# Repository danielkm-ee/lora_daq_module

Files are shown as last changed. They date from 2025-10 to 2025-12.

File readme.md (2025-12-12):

# LoRA DAQ Node
For our Electrical and Computer Engineering practicum at Portland State for 2025 we have developed a LoRA based data acquisition node that can be used for data collection and monitoring systems over large areas.

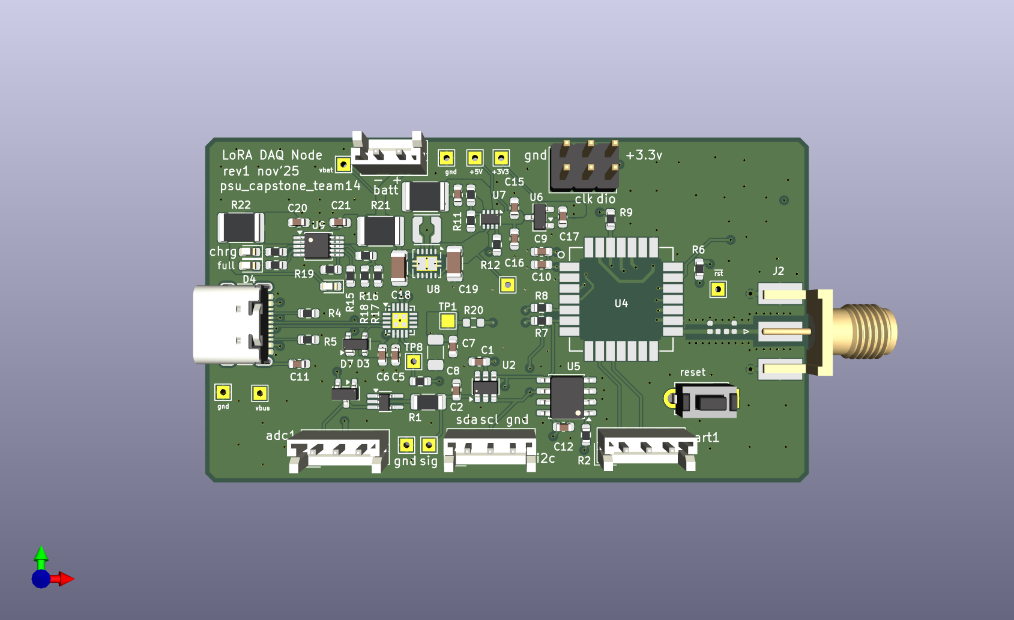
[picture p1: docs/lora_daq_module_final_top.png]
3d model of lora board top


This board is powered by the Seeed Studios Wio-E5 LoRA module for use with it's designated antenna.

## Supported Peripherals
We've done our best to provide a versatile range of peripherals for high quality data collection and application flexibility. This includes a UART interface for communicating with the device via it's USB-C port, a SWD interface for loading and debugging applications, a 16-bit ADC and I2C connector that can be used with analog and I2C compatible sensors.

The device may be powered via it's USB-C (USB 2.0) connection, or by a 1s1p lithium ion battery. The device also
supports battery charging when powered by USB-C with the battery connected.

List of Peripherals
------------------
* 16-bit ADC
* I2C interface
* MicroSD card slot
* 2 external UART interfaces (one via USB-C port)
* 6-pin SWD header for ST-Link v2
* SMA connector for the 868-916MHz LoRA Antenna
* 2-pin JST EH connector for battery power and charging

## Credits
* Manaf Alali - hardware schematics
* Eyad Ahmed  - firmware
* Daniel Monahan - hardware schematics and layout
* Saleh Sabti - hardware schematics
* Dingyu Zhou - firmware

> All team members contributed to every aspect of the project, going beyond the general roles specified here.

----
*Portland State University ECE411 Practicum project, Fall 2025*

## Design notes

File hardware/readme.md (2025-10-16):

# LoRA DAQ Hardware
Here you will find the KiCAD project files for the lora daq module. This project has been separated into three main parts:  
* `adc.kicad_sch` includes the input filter and supporting hardware related to the adc  
* `power_management.kicad_sch` includes the battery controller, ldos, and dc-dc converters  
* `lora_module.kicad_sch` includes the wio-e5, lora antennae, and eeprom  

## KiCAD Version Control Notes (Please read these!)
KiCAD version control will be managed through this git repository, there are some important things to 
keep track of while you work!  

### Git Management
To keep things nice, please keep all of your work confined to the schematic for your module. This should also 
correspond to your git branch. Here's an example:

Say I'm working on the ADC, first I'll make a git branch for my work...
```
$ git checkout -b schematic-adc
Switched to a new branch 'schematic-adc'
```
then I'll do work in the adc.kicad_sch file, and when I'm ready to submit the updated schematic I'll upload it to
my schematic branch.
```
$ git add ./adc.kicad_sch
$ git commit -m "added buffer to the input filter of the ads1115"
$ git push --set-upstream origin schematic-adc
Enumerating objects: 22, done.
Counting objects: 100% (22/22), done.
Delta compression using up to 14 threads
Compressing objects: 100% (20/20), done.
Writing objects: 100% (20/20), 8.72 KiB | 4.36 MiB/s, done.
Total 20 (delta 5), reused 0 (delta 0), pack-reused 0
remote: Resolving deltas: 100% (5/5), completed with 1 local object.
remote: 
remote: Create a pull request for 'test' on GitHub by visiting:
remote:      https://github.com/danielkm-ee/lora_daq_module/pull/new/schematic-adc
remote: 
To github.com:danielkm-ee/lora_daq_module.git
 * [new branch]      schematic-adc -> schematic-adc
Branch 'schematic-adc' set up to track remote branch 'schematic-adc' from 'origin'.
```
This way I can push/pull changes to the adc schematic separately, so I can safely work on the adc schematic without 
the need to resolve merge conflicts.

### Symbol and footprint libraries
When you are creating KiCAD symbols, they will be stored in your local *project* directory. We want these files to 
stay local to your machine until we can all collectively incorporate them into a project symbol library, so we've set 
up the .gitignore file to prevent accidental uploads of your local kicad schematic files, this includes symbols, 
footprints, and project settings related to your local UI.

> #### Files to keep local:
> * `fp-info-cache` -- this helps kicad pull up your most recent footprints faster, this thing is disposable and kicad creates and replaces it automatically
> * all `*.pretty` files -- these are footprint library files, they group your local symbols into library groups
> * all `*.kicad_mod` files -- these are your actual footprints (called 'modern footprint files')

> It is important that these aren't added to your commits because they will cause merge conflicts.

You are free to create and manage your footprint and symbol libraries locally in any way you choose--try to be 
organized because it will help us create a shared symbol library.

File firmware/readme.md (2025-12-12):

# LoRA DAQ Firmware

## Toolchain Setup

This project targets the **STM32WLE5** (Cortex-M4) MCU and uses a GNU-based toolchain with openocd to flash and debug.

### 1. Install Build Tools (on Ubuntu or WSL)
```bash
sudo apt update
sudo apt install build-essential gcc-arm-none-eabi gdb-multiarch make openocd
sudo apt install -y clang-format
```

### 2. Verify Installation
```bash
arm-none-eabi-gcc --version
openocd --version
```
### 3. Project Structure
```
firmware/
├── src/           # Application code and nessary files from external repo
├── config/        # HAL & board configuration TODO
├── lib/           # STM32CubeWL HAL + CMSIS
├── startup_stm32wle5xx.s
├── stm32wl.ld     # Linker script
└── Makefile
```

### 4. Build and Flash
#### Build firmware
```
make
```
#### Flash to STM32 (via ST-Link)
```
make flash
```

#### External make
```
make tx         # Build firmware with TX configuration
make rx         # Build firmware with RX configuration
make flash_tx   # Flash TX firmware to the board
make flash_rx   # Flash RX firmware to the board
```

### 5. Every time before push
#### Run a clean build
```
make clean
make
```
#### Auto-format your C code
```
make format
```
## Development Notes

This firmware is being developed for a LoRa-based data-acquisition system. Its main goals are to:
- Sample digital data from the ADC and other digital sensors over I2C interface
- Transmit the collected data through LoRa
- Store measurements in an external storage module through SPI interface
- Provide real-time debug output over UART
- Implement a low-power architecture using timer-driven interrupts

### HAL Module Configuration
The file `firmware/src/stm32wlxx_hal_conf.h` controls which HAL peripheral modules are enabled in the project.  
To disable a module, comment out its corresponding `HAL_xxx_MODULE_ENABLED` line.

### How to Use HAL Functions
To learn how a specific peripheral works, refer to the HAL driver source files located in:
`firmware\lib\STM32WLxx_HAL_Driver\Src`

### File Structure of Src
I think our initial idea for the `firmware/src` files struture is to put all the header and source code under one folder, but to make clearer for each module we develop, I lay out our code structure as follows:
```
src/
├── app/
│   ├── main.c
│   └── main.h
├── i2c/
│   ├── i2c_driver.c
│   └── i2c_driver.h
├── lora/
│   ├── lora_app.c
│   └── lora_app.h
├── power/
│   ├── power_mgmt.c
│   └── power_mgmt.h
├── scheduling/
│   ├── scheduler.c
│   └── scheduler.h
├── sensors/
│   ├── ads1110.c
│   ├── ads1110.h
│   ├── sensor_digital.c
│   └── sensor_digital.h
├── storage/
│   ├── data_buffer.c
│   └── data_buffer.h
├── uart/
│   ├── uart_debug.c
│   └── uart_debug.h
├── Other system configure files... (Placement TBD)
```
firmware/
├── Makefile           # Main Build Script (Tx/Rx targets, Flash rules)
├── config/            # Hardware Configuration (Pins, Clocks, Interrupts)
├── src/               # User Application Code
│   ├── app/           # Main Entry & Logic
│   ├── lora/          # LoRaWAN Stack & App Layer
│   ├── sensors/       # Drivers (AM2320, ADS1110)
│   ├── scheduling/    # Task Scheduler
│   ├── power/         # Power Management
│   ├── storage/
│   └── i2c/ & uart/   # Hardware Interfaces
├── lib/               # Vendor Libraries (STM32 HAL, CMSIS, Radio Drivers)
├── Utilities/         # Shared Helpers (Timers, LPM, Trace)
└── build/             # Compilation Output (.elf, .bin, .hex)

#### TODO:
- [x] cleanup structure for contribution and reviews
- [] cleanup the external relied system configuration files
- [] better code structure

### LoRa module
The LoRa module was built using the reference project at
https://github.com/Seeed-Studio/LoRaWan-E5-Node/tree/main/Projects/Applications/LoRaWAN/LoRaWAN_End_Node  

It relies on the SubGHz LoRa driver that I included in `firmware\lib\SubGHz_Phy`. At first, I tried to use the radio driver on its own to configure LoRa directly on the chip, but it didn’t work until I pulled in most of the `.c` and `.h` files from the example application. Those files appear to contain essential HAL initialization and system-level setup that the driver depends on. Because of this, all files placed directly under the `src` folder are currently used for HAL and board-level configuration. After adding them, I was able to configure LoRa transmission successfully and confirm it using my SDR.

Some of these files directly under `/src` are clearly unnecessary and should eventually be removed. I will check after all system have been set up.

I also tried to understand the original Seeed code to get more understanding for lora, but it includes extensive LoRaWAN network-server configuration. This adds a large amount of logic beyond the PHY layer, which makes it harder to follow for our case for point-to-point LoRa use case. So I directly referred to `radio.h` under `firmware\lib\SubGHz_Phy` to locate the functions used for radio initialization and configuration. 

Update: I have test with external dev board flashing RX firmware `make rx` and verify through a point-to-point test that our LoRa module is correctly configured and can transmit the correct packet signal that can be decoded.

All of the LoRa application code is organized under `src/lora`.

#### TODO:
- [x] Test the signal physically transmitted
- [x] Test the signal can be decode from other LoRa board

### Scheduling Interrupt
The scheduling system of transmitting and sampling for now is implemented using a timer-based interrupt driven by TIM2 timer. I abandoned initial thought for implementing FreeRTOS for such structure. (Yes, a bit complex for me - I overestimate myself and maybe not too important to consider that if we want to add more color for the firmware, but at first we should have a at least functional firmware!)

The timer is configured to generate an interrupt every millisecond, and its internal counter is used to track elapsed seconds. Inside the interrupt callback, the firmware increments a `second_counter` and check if our counter has reached the setup sampling and transmission intervals. When the accumulated seconds meet the intervals goal, the interrupt will set `sample_flag` or `tx_flag`, while in the main loop will use to check to decide which action to take.

In the main loop, using `__WFI();` to let CPU just sleep while no interrupt.

All of the scheduling code is organized under `src/scheduling`.

#### TODO:
- [x] Think of a way for low power schdeduling
- [] Power profiling to see if the codebase really enable low power

### UART Debug
The current stage of UART is enable upon code that I took from the reference project at
https://github.com/Seeed-Studio/LoRaWan-E5-Node/tree/main/Projects/Applications/LoRaWAN/LoRaWAN_End_Node

The UART setup is handled through functions in `firmware\src\timer_if.c`(taken from example code), which has enabled the UART peripheral. Using this setup, I wrote application UART codes for serial debugging outputs.

All of the UART code is organized under `src/uart`.

#### TODO:
- [x] Enable UART to debug
- [] Using UART to see the data sampling and receiving

### Sensor interface and Sensor Data

#### TODO:
- [] Enable I2C
- [] Data structure for nessary information and transmission 
- [] Configure sensors and ADC properly
- [] Validate correct data acquisition

### Test
I want all the test code that everyone commits to be formatted using clang-format, and I also want testing to be driven through the Makefile.

#### TODO:
- [] enable CI test
- [] think of unit test cases

## Stage of Development
TODO:
- [x] Building and Flashing code structure
- [x] Enabling LoRa
- [] Enabling I2C
- [] Configure ADC and digital sensor if needed
- [x] UART debuging
- [] Github CI test
- [] LoRa testing
- [] Sensor data validation

### (HEAD -> firmware_init, origin/firmware_init)

#### Stage commit 398cc2e363845a623673a12c9f33951d18dbbad1 
At this stage of the commit, we are now able to enable LoRa transmission, UART debugging output, and schedule the main loop for sampling and transmitting using a timer-based interrupt. After you build the project with the Makefile and flash the firmware, you should see UART output over USB like:
```
Sampling...
Transmitting...
Transmission complete.
```
This repeats every 1 second. If you also connect the SMA output to a signal analyzer or an SDR, you should see the waveform dancing at 915 MHz.
#### Stage commit 2383b4ef38c4a43d3942959597c4a2f3eaec716b
At this stage of the commit, we have initialized the bare-metal coding structure so the firmware can be built and flashed without relying on any external tedious GUI tools. Instead, we build the code using gcc and flash it using OpenOCD. In this commit, we managed to drive the onboard LED through GPIOB PIN 5 using the official HAL driver.

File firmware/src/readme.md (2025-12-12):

# Source Code Structure

## Modules

- `app/` - Main application
- `lora/` - LoRa communication
- `i2c/` - I2C sensors
- `uart/` - UART interface
- `power/` - Power management
- `scheduling/` - Task timing

## step up files (Don't Modify)
Files in `src/` are configuration/setup files required by our chip — do not edit them.

## Adding a Module

1. Create `src/your_module/`
2. Add `your_module.h` and `your_module.c`
3. Update Makefile
4. Test before integrating

## Build
```bash
make clean
make
make flash
```

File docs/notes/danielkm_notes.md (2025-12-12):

# Development notes
author: daniel

## RN2483 using nRF52810 host
I’ve looked into two LoRA solutions tonight (10/9/25) and this is the one I think we would enjoy the most.

I read the datasheets for the STM32wl55cc with the RN2483, the stm board uses cortex m4 and cortex m0 cpus, the m4 is for general embedded systems use, the m0 is the rf/secure/lora enabled cpu. It gets complicated.

I like the RN2483 because it’s controlled through a UART with acii commands and has a nice LoRAWAN protocol api that we could control using any MCU we choose. This allows us the freedom to use nRF as we wanted. The caveat compared to using the stm board is that st provides it’s own debug programmer, and nrf requires some for of SWD like J-Link. Initally I was like.. damn.. because J-Flash probes are like $400-$1200, but then I found the J-Link EDU Mini for $60.

We’d need an nRF chip supporting uart, swd, and i2c at the minimum, so I found the cheapest option and it’s the nRF52810, for about $2.40 per chip in a QFN48 or QFN32 package.

[https://shop-us.segger.com/product/j-link-edu-mini-8-08-91](https://shop-us.segger.com/product/j-link-edu-mini-8-08-91)
When we eventually need to flash a bootloader on the nRF chip, this is the most affordable option.

#### Useful sources from tonight
[lorawan primer](https://www.iotforall.com/a-primer-for-loralorawan)
[antenna strip trace impedence calculator for future layout stuff](https://www.pasternack.com/t-calculator-stripline.aspx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)
[another lorawan primer](https://en.iotrouter.com/in-what-topology-are-lora-and-lorawan-network-structures-deployed/)

# Wio-E5 Schematic development notes

Making a note here while I try to finish the schematic for the lora module.

During the design review Eric brought up some good points regarding the peripherals. Here's what we've landed on thus far...

On-Board Peripherals:
- I2C EEPROM - for storing device configuration, calibration parameters, unique device ID and whatnot
- SD Card - for storing data locally maybe used for debugging or as a failsafe, but we figured it would provide some much-obliged flexibility.

Other things I've been working to implement are the SWD connections. According to docs from STM32 and the datasheet for the wio-e5 board the default pins for the serial peripheral interface (SPI) SWD/ST-Link are as shown in the table here.

| Wio Package Pin | STM32 Pin Name | Description |
| :---: | :---: | :--- |
| 3 | PA13 | SWDIO |
| 4 | PA14 | SWCLK |

As far as the remaining pins, I've attempted to retain the pinout according the Wio-E5 datasheet, though I am providing the exported pinout in [docs](../wio-e5pinout.csv).

Here's a table showing the current pinout:

| Position | Name | Type | Signal | Label |
| --- | --- | --- | --- | ----- |
| A1 | VSSSMPS | Power  | | |
| A2 | VDDSMPS | Power  | | |
| A4 | PA14 | I/O | DEBUG_JTCK-SWCLK | |
| A5 | VDDA | Power  | | |
| A7 | VDD | Power  | | |
| A8 | VBAT | Power  | | |
| A9 | PA12 | I/O | | |
| B1 | VLXSMPS | Power  | | |
| B2 | VFBSMPS | Power  | | |
| B3 | PA15 | I/O | I2C2_SDA | |
| B4 | PB15 | I/O | I2C2_SCL | |
| B5 | VREF+ | MonoIO | | |
| B6 | PC14-OSC32_IN  | I/O | | |
| B7 | VSS | Power  | | |
| B8 | PA13 | I/O | DEBUG_JTMS-SWDIO | |
| B9 | PA11 | I/O | | |
| C1 | PB3 | Output | GPIO_Output | |
| C2 | PB4 | Output | GPIO_Output | |
| C3 | PB7 | I/O | USART1_RX | |
| C4 | PB9 | I/O | SPI2_NSS | |
| C5 | PC15-OSC32_OUT | I/O | | |
| C6 | PB14 | I/O | SPI2_MISO | |
| C7 | PC13 | I/O | | |
| C8 | PA10 | I/O | SPI2_MOSI | |
| D2 | PB5 | Output | GPIO_Output | |
| D3 | PB8 | I/O | | |
| D4 | PC2 | I/O | | |
| D5 | PC3 | I/O | | |
| D6 | PA0 | I/O | | |
| D7 | PB13 | I/O | SPI2_SCK | |
| D8 | PB2 | I/O | | |
| D9 | VSS | Power  | | |
| E1 | PB6 | I/O | USART1_TX | |
| E2 | VDD | Power  | | |
| E3 | VSS | Power  | | |
| E4 | PC5 | I/O | | |
| E5 | PA9 | Output | GPIO_Output | |
| E6 | PB12 | I/O | | |
| E7 | PB1 | I/O | | |
| E8 | VDDRF | Power  | | |
| E9 | VDD | Power  | | |
| F1 | PC1 | I/O | LPUART1_TX | |
| F2 | PC0 | I/O | LPUART1_RX | |
| F3 | PC4 | I/O | | |
| F4 | PA6 | I/O | | |
| F5 | NRST | Reset  | | |
| F6 | PB0-VDD_TCXO | I/O | | |
| F7 | VDDRF1V55 | Power  | | |
| F8 | OSC_OUT | MonoIO | | |
| G2 | PC6 | I/O | | |
| G3 | PA1 | I/O | | |
| G4 | PB11 | I/O | | |
| G5 | VSS | Power  | | |
| G6 | VSSRF | Power  | | |
| G7 | VSSRF | Power  | | |
| G8 | VSSRF | Power  | | |
| G9 | OSC_IN | MonoIO | | |
| H1 | PA3 | I/O | USART2_RX | |
| H2 | PA2 | I/O | USART2_TX | |
| H3 | PA7 | I/O | | |
| H4 | PB10 | Output | GPIO_Output | |
| H5 | VDD | Power  | | |
| H6 | VSSRF | Power  | | |
| H7 | RFI_N | MonoIO | | |
| H8 | VDDPA | Power  | | |
| H9 | VR_PA | Power  | | |
| J1 | PA4 | I/O | | |
| J2 | PA5 | I/O | | |
| J3 | PA8 | I/O | | |
| J5 | PH3-BOOT0 | I/O | | |
| J6 | RFI_P | MonoIO | | |
| J8 | RFO_LP | MonoIO | | |
| J9 | RFO_HP | MonoIO | | |

# Nov 12th -- Schematic updates and Preliminary layout

## Schematic updates 
Yesterday I was able to merge the drawing sheets for the adc, lora module, and power management schematics. I worked on the schematic to get it ready for layout, and added to the power management schematic.

Here's a quick changelog:
--------------
* Added power switching IC to select USB vs Battery power to the power management schematic
* Added two pin connector for battery
* added pullup for the reset pin on the lora module
* added large DNP capacitor at the 3V3 output from the CP2102 as a fallback power supply
* added footprints to all components

More detailed comments
----------------
There are two ways we can arrange the power circuits. We could (1) boost the 3.7V battery voltage, then perform power switching between VBUS and VBATT, then send the winner to the LDO. or (2) compare VBUS and VBATT, then send the winner to the boost/buck converter, then the LDO. Currently I'm using option (1), but we may want to move to option (2) as the power switching circuit will help to limit current draw from the battery when we are not using it.

When adding footprints I attempted to be accurate as I could without making custom footprints. It's possible that the footprints I've used need modifications and we'll have to check on that before we order the boards next week.

## Preliminary Layout
Tonight I was able to arrange the components, and I've used reference layouts for every aspect of the circuit. This includes the layouts provided on the data sheets for the MCP73833, TPS2116, and TPS63002, and otherwise I used the dev board and application notes as a reference.

I was not able to lay out all of the traces, particularly because I haven't decided how I want my power planes set up. Tonight I focused on fitting the components onto the board with a great attention to detail on their arrangement and orientations. I'll be submitting the preliminary layout and current schematics to canvas for the week 6 assignment, and to github (for the assignment and for our own reference.)

# Nov 14th - BOM and Rough draft of CAD
I'm currently working through the symbol fields table component-by-component to assign part numbers and finalize our footprints as best as I can. I've run into a few cases where we may need to make some changes and I want to be sure to explain them here!

changelog:
----------
* Replacing the ADS1115 with the ADS1110
> Basically, the ADS1115 comes in three packages; a QFN, a TSSOP, and a VSSOP. When assigning the prelim footprint I used the TSSOP because it is much more friendly for hand soldering, with a pin spacing of about .85mm. It's closest counterpart would be the VSSOP, though this has a .5mm spacing which will make it very difficult to solder. The TSSOP would have been fine to use, but Digikey only stocks the VSSOP and the QFN, which present considerable challenges to an already difficult buildup of this board thus far. 
> Because we aren't using the four channels on the ADS1115, there is no need to stick to this specific part. Additionally, the added channels create a more expensive and difficult ADC circuit for our board which is hard to justify for this prototype. I looked to the ADS1119 which comes in a TSSOP with the same number of channels, but an even more reasonable option here is the ADS1110 which comes in an SOT23-5 and has a single differential input. Digikey has around 5k stocked and they come in multiple variants with different I2C addresses, and the SOT23-5 is a much more hand-solder friendly package. This will require some careful review of the ADC circuit, though the ADS111x series does a good job of being close to standard so we may be able to avoid major changes here.

When looking for resistors I noticed a vast majority of 10kΩ resistors, I assume these are for pull ups. I've been using 4.7k for these, which is a very viable option, but I wonder if we should move to 10k to reduce quiescent current draw as were operating on battery power... will look into this later on.

Another note, I found that the CP2102N has some form of battery charger detection that I can't believe I've missed up until now. Not sure what this entails but it's another thing to explore as I review our power schematic.

As far as resistors go, I am using 0603 1/10W everywhere for now. Once we've had another pass over everything we can bump up footprints and power tolerances as needed.

> Also, note to self.... FILL OUT THE PRICE PER UNIT FIELD AS YOU GO!!  
> Currently 75 percent through the part assignment and will have to go over the whole list again T.T

> > *Actually, I think digikey will be able to give me pricing based on a csv.. so crisis averted.

For the 3.3uH inductor used on the buck/boost tps63002 I am using the Coilcraft LPS3015 series based on the reccommended inductor list from table 2 on page 11 of the IC's datasheet. This is a marketplace item, shipped through coildcraft directly. In general I have avoided marketplace items.

Another exception I've made here is the resistor rule mentioned earlier, I am using an automotive grade 50Ω resistor at the pi network at the antenna, though this may be overkill. For refrence, the price difference is about 6x, where typical resistors are 10 cents, this one is 62 cents. like i said,,, maybe overkill!

Another area we'll definitely want to explore is connectors, particularly headers. Currently I'm ordering pre-cut pin headers in the array sizes we need, but since we're hand-soldering these down that's completely unnecessary. May be cheaper to just order a pair of long 1-row and 2-row headers to cut down to size by ourselves.

# antenna layout
I've looked into the microscrip design for the antenna connector, had some discussion with Maxwell, and consulted online sources and came up with the following options:

Using the microstrip line calculator on KiCAD with the following parameters:
| er | tan(delta) | rho | H | H(top) | T | ur | freq  | L  | Z0 |
|----|---|---|---|---|-----|----|---|----|----|
|3.67| 0.012 |1.72e-8|.2021mm| .2021mm|.0432| 1  | 880MHz|10mm|50Ω |

I got W = 0.486816 which I rounded to 0.487 for the microstrip trace width.

We have two options, either trust the microstrip working, or adding a pi network for impedance matching if we run into issues.

## Keeping the pi network
to keep the pi network, we will have to use 0402 pads and place them directly in line with the microstrip. They have to be as close to the 0.487 trace width as possible, or they present an impedance discontinuity.

This complicates things in general, so the other option is...

## Ditch the pi network
Just lay out the microstrip and bet things will work out okay. Worst case we can cut open some traces and try our best to do something about an impedance mismatch. Based on timeline, this may be our best option.

# Ground gap and via fencing
Back to the general layout decisions, I've used the convention that the ground gap should be H1+H2, which for our board is 0.4042mm, and our via fencing should be spaced no more than (1/10)λ = (1/10)(1/(2πf))*(3e8) = 0.005425m or 6mm.
I've applied both of these rules to the antenna layout.

# Final design notes, changes, checkoffs
I've added 1812 resistors at the inputs and outputs of the power circuits. One from VBUS to the MCP7338, another from the battery to the buck/boost, and a final one at the input of VBUS to the power mux. 
Final failsafes for power will be to remove the 0Ω to the power mux, then mod wire the VBUS pad to the LDO. We would also want to desolder the power mux I believe.

I've fixed the LEDs for the battery charger, originally I made up their indicators but now we have a green led at STAT2 which indicates full/stopped charging. Amber at stat1 indicates charging in progress, and red at PG indicates power is on/off.

I added a 3 pin JST connector for the i2c bus and removed the testpoints for the sda and scl to save room.

I added the pi network back in and set up the board for a 1.6mm 4 layer jlcpcb board with 1oz top and 10z middle layers.

I also replaced the two pin header used for the battery with a two pin jst receptacle.

I labeled all test points, shrunk reference texts to declutter the board, and made necessary modifications to flood planes and traces to facilitate power jumpers.

I added a reset switch to restart the microprocessor that can be left unsoldered if desired.

The ADC input filter has been rearranged and redesigned according to andrews instructions,
the buffer has been moved to the input, the voltage divider was removed and the power rails were changed to +3.3V. I put the anti-aliasing low-pass filter at the output of the buffer and used a 47Ω and 4.7uF to set the cutoff at 720Hz. I used the 47Ω with the aim of having a low output impedance.

I updated the antenna trace width to 0.49mm according to the updated jlc pcb parameters, I then added the pi impedance matching network using 0402 components. They are a bit large, though I believe we may be close enough here and wanted to bring the option back in incase the jlc impedance calculations aren't great.

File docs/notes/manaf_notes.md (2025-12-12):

# Development Notes
Author: Manaf Alali 

# Power Management Module Notes 10/21
- Started mapping out the full power system for the board.
- Goal: The board must be powered by a 3.7V LiPo battery and be rechargeable via USB.
- The system needs to provide a stable 3.3V for the main LoRa MCU, ADC, and other chips.

# November 8, 2025 - Design Change (Rev 2)
- Action: Removed the 3.3V buck-boost converter from the original design.
- Reason: We decided to simplify the power tree. Instead of running two separate 
buck-boost converters from the battery, we are now using a two-stage approach.

# New Design:
- A 5V buck-boost (TPS63002) creates a stable +5V rail from the battery.
- I then added a simple Low-Dropout Regulator (LDO), the MCP1700, which
takes that stable 5V as its input and efficiently steps it down to our main +3.3V rail.

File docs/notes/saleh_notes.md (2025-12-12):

# Development Notes - ADC Integration
auther: saleh sabti

On October 16, 2025, I researched the ADC component for our LoRA DAQ system, focusing on the ADS1115 integrated with the Nordic nRF52840. Here’s my findings based on the datasheets I looked up:

### Technical Findings

**I2C Address Configuration:**
- ADDR pin connection determines I2C address 
- Four I2C addresses (0x48-0x4B) Default 0x48 when ADDR→GND 
- I2C comm. operates at standard (100kHz), fast (400kHz), or high-speed (3.4MHz).
- contains four 16-bit registers accessible via an 8-bit pointer register

**Config register bit mapping (default 0x8583):**
- Bit 15 (OS): Operational status 
  - 0: No effect (read), device performing conversion (write)
  - 1: Start single conversion (write), device not converting (read)
- Bit 8 (MODE): Operating mode
  - 0: Continuous conversion
  - 1: Single-shot (power-down after conversion)
- Important: ADDR pin must be tied to something, not floating!

**Power**
ADC Power Consumption:
- Continuous mode: 150µA @ 3.3V
- Single-shot mode: 0.5µA sleep (huge savings!)
So now I guess if our measurement cycle is (every 5 min):

**Noise and Filtering**
- Hardware: RC filter (1kΩ + 100nF) gives 1.6kHz cutoff between sensor output and ADC input.
- we can do it in software but we need a library

**Conversion timing analysis (sample per min.):**
- 8 SPS: 125ms per conversion
- 128 SPS: 7.8ms per conversion (default)
- 860 SPS: 1.16ms per conversion
  - **To save power we can use single shot mode (8SPS) where it sleep between readings. For continuous monitoring, using 128 SPS mode and update each channel reading at ~32ms intervals.**
 
**Noise and Filtering**
- RC filter (1kΩ + 100nF) gives 1.6kHz cutoff between sensor output and ADC input.
- we can do it in software but we need a library

### Resources & Links
**Datasheets**
- [ADS1115 Datasheet](https://www.ti.com/lit/ds/symlink/ads1115.pdf)
- [Ultra-Small, Low-Power, 16-Bit ADC with Internal Reference (Rev. B)](https://cdn-shop.adafruit.com/datasheets/ads1115.pdf)

**Code Libraries**
- [Adafruit ADS1X15 Library](https://github.com/adafruit/Adafruit_ADS1X15) - implementation

# October 26, 2025 - ADC Schematic Design

On October 26, 2025, I worked on creating the schematic for the ADC circuit, which includes the sensor input, low-pass RC filter, protection diodes, and the I2C interface connections. Here's what I did based on the datasheets I looked up:

### Implementation
**Design References:**
I started in the datasheet:
- Figure 7-1: Shows the ADS1115 block diagram with all components and I2C interface
- Figure 9-1: Typical connections for the ADS1115
- Figure 9-5: Basic hardware configuration

**Component Selection & Placement:**
- ADS1115 - ADC with I2C interface
- Sensor input connectors 
- Input protection diodes
- Input filter: RC low-pass filter (fc ≈ 3.4 kHz)
  - R1: 1k ohm series resistors
  - C1: 47nF capacitors
- R3, R4: 10k ohm I2C pull-up resistors
- C3: 0.1uF VDD decoupling capacitor

**Filter Design:**
- Hardware: RC filter (1kΩ + 47nF) gives 3.4kHz cutoff between sensor output and ADC input
  - To prevent high-frequency noise

**Next Steps:**
- Connect input signal path: sens. => Protection => R1 =>  C1 =>  AIN0
- Run ERC to check for errors

### Git Activity
```bash 
git checkout -b schematic-adc
git add hardware/lora_daq_module/adc.kicad_sch
git commit -m "added ADC input filter schematic"
git push origin schematic-adc
```

### Resources & Links
**Datasheets:**
- [ADS1115 Datasheet](https://www.ti.com/lit/ds/symlink/ads1115.pdf)

# Nov 10, 2025 - ADC Schematic Design Optimization

On November 10, 2025, I optimized the voltage divider resistor values after reviewing the OPA333 datasheet. Daniel suggested we could meet three requirements with one voltage divider instead of adding separate protection circuitry.

### Problem Identified
While reviewing **OPA333 datasheet Section 7.3.2** (Input Voltage), found critical requirement:
> "Input voltages that exceed the power supplies can cause excessive current to flow into or out of the input pins. Momentary voltages greater than the power supply can be tolerated if the input current is limited to 10 mA. This limitation is easily accomplished with an input resistor, as shown in Figure 18."

Since our soil moisture sensor outputs up to 5V (exceeds 3.3V supply by 1.7V), we need input current protection.

### Solution
Daniel suggested increasing the voltage divider ratio to accomplish three things simultaneously:

**1. Voltage divider:** Scale 5V → 4.096V for ADS1115 optimal range  
**2. Input protection:** Limit current to <10mA per OPA333 datasheet  
**3. FSR matching:** Stay within ±4.096V ADS1115 range for 125µV resolution

### Design Calculations

**Voltage divider:**
```
Target: 4.096V from 5V input
For voltage divider: Vout = Vin × (R2/(R3+R2))

R3 = 47kΩ  (series input protection)
R2 = 220kΩ (to ground)

Voltage scaling: 5V × (220k/(47k+220k)) = 4.12V 
Input protection: 5V/47kΩ = 106µA
FSR match: 4.12V < 4.3V max 
```

**RC filter cutoff:**
```
R1 = 1kΩ
C1 = 47nF (changed from 100nF)
f_cutoff = 1/(2π × 1k × 47nF) = 3.39 kHz
```

### Component Updates
- R3: 2.2kΩ → **47kΩ**
- R2: 3.9kΩ → **220kΩ**  
- C1: 100nF → **47nF**

**Schematic Status:** Finalized - only BOM and component boxing remaining

### ADS1115 Configuration Planning (next steps)
```
Gain: ±4.096V (GAIN_ONE) → 125µV resolution
Data rate: 128 SPS → 8ms conversion time
Mode: Single-shot → 0.5µA sleep current (vs 150µA continuous)
Resolution: 16-bit → 65,536 counts
Config register: 0xC383
```

### Wio-E5 I2C Interface
Started looking into STM32 development:
- **I2C2 pins:** PB15 (SCL), PA15 (SDA)
- **Tool:**  STM32CubeIDE for development
- **Debug:** ST-Link for programming interface

**Next Steps:**
- Complete STM32CubeIDE setup today
- Configure I2C2 peripheral
- Write I2C scanner test code

### Resources & Links
**Datasheets:**
- [OPA333 Datasheet](https://www.ti.com/lit/ds/symlink/opa333.pdf) 
- [ADS1115 Datasheet](https://www.ti.com/lit/ds/symlink/ads1115.pdf)
- [Wio-E5 Module Datasheet V1.1](https://files.seeedstudio.com/products/317990687/res/LoRa-E5%20module%20datasheet_V1.1.pdf)

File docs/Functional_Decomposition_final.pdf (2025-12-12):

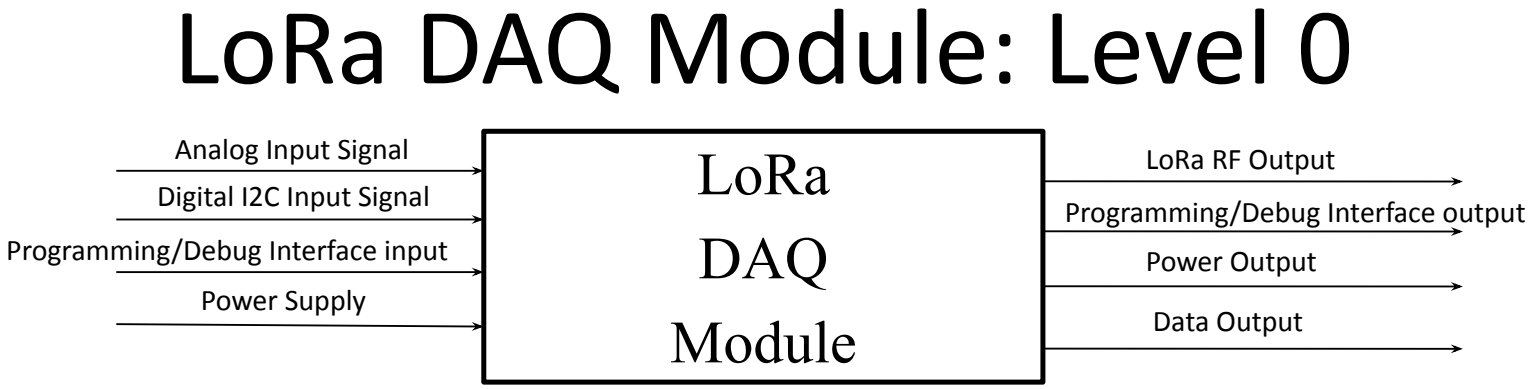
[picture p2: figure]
LoRa DAQ Module: Level 0; LoRa; DAQ; Module; Analog Input Signal; Digital I2C Input Signal; Programming/Debug Interface input; Power Supply; LoRa RF Output; Programming/Debug Interface output; Power Output; Data Output

Module | LoRa DAQ Module
Inputs | Analog Input Signal: up to 0.33 V peak from analog sensors Digital I²C Input Signal: SDA, SCL from digital sensors Programming/Debug Interface Input: from ST-Link or UART interface Power Supply: 4.2 V–2.9 V battery or 5 V USB
Outputs | LoRa RF Output: 902–928 MHz Programming/Debug Interface Output: ST-Link or UART interface Power Output: 3.3 V for sensors Data Output: SD card interface
Functionality | The LoRa DAQ Module reads data from custom analog and digital sensors, stores measurements on a local SD card, and can transmit real-time data through the 902–928 MHz LoRaWAN radio. The system is designed for long-term, low-power operation, enabling continuous data collection and transmitting on a chargeable battery supply.

# LoRa DAQ Module: Level 1

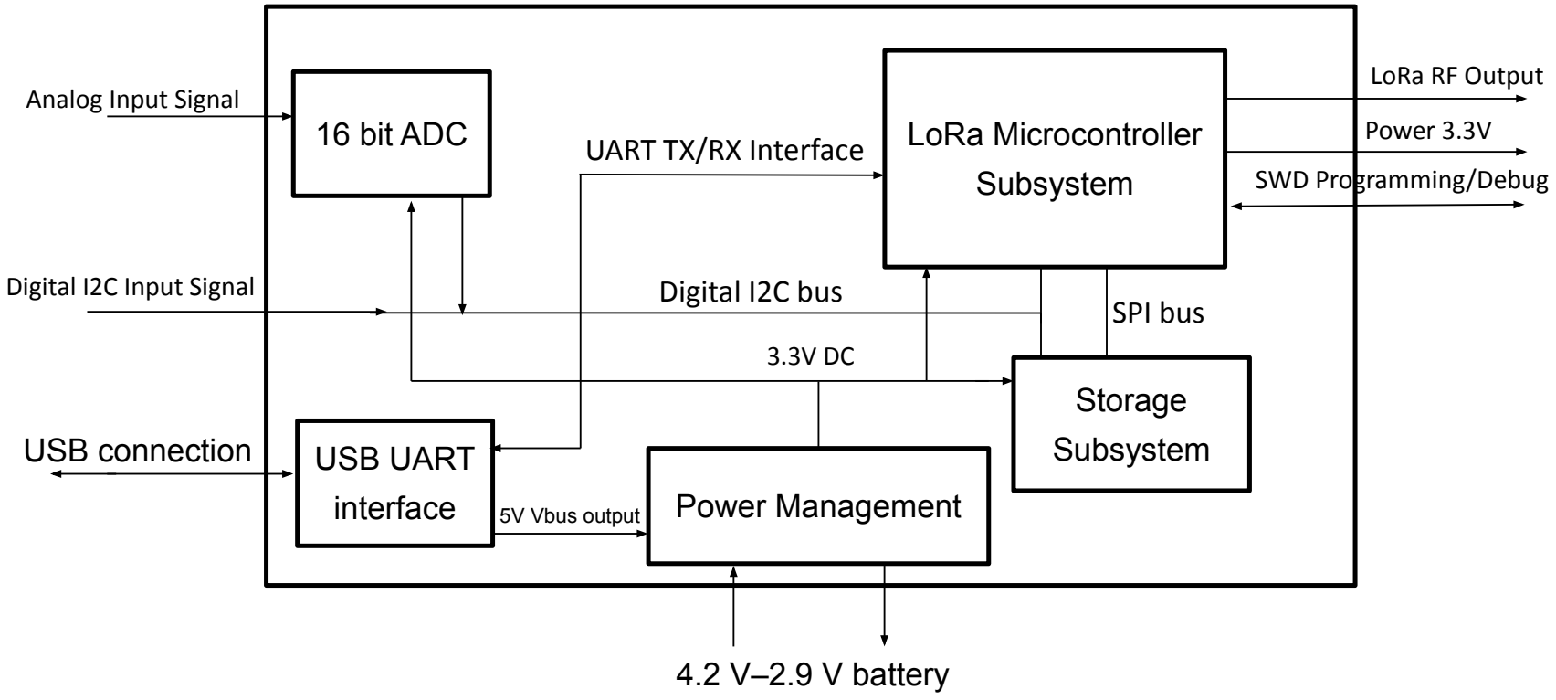
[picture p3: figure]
Power Management; 16 bit ADC; LoRa Microcontroller; Subsystem; 4.2 V–2.9 V battery; Analog Input Signal; Digital I2C Input Signal; Digital I2C bus; USB UART; interface; 5V Vbus output; UART TX/RX Interface; USB connection; Storage; SPI bus; LoRa RF Output; Power 3.3V; SWD Programming/Debug

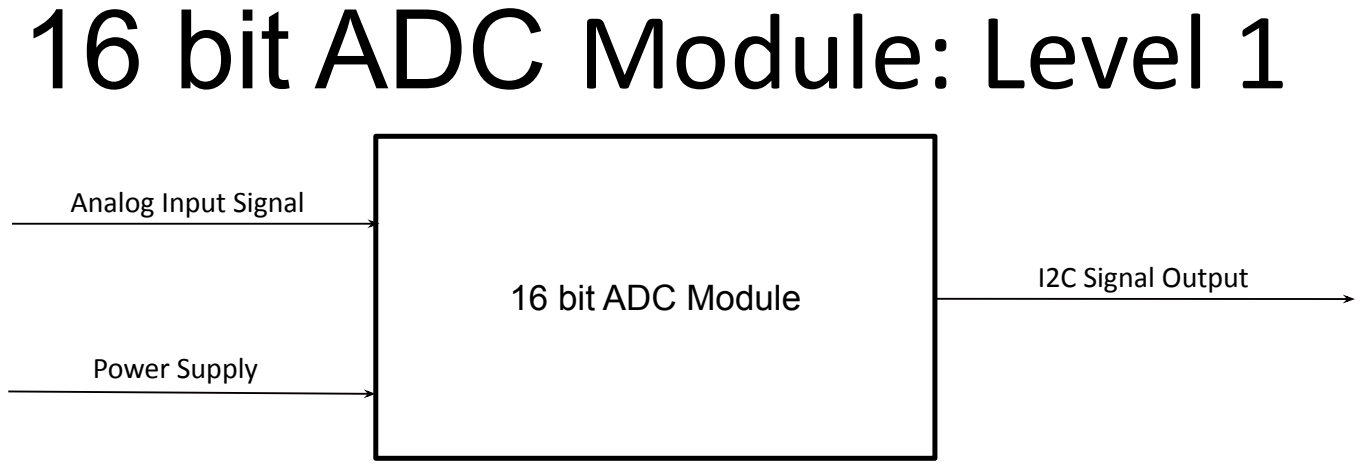
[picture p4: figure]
16 bit ADC Module: Level 1; 16 bit ADC Module; Analog Input Signal; Power Supply; I2C Signal Output

Module | 16 bit ADC Module
Inputs | Analog Input Signal: up to 0.33 V peak from analog sensors Power Supply: 3.3V power supply from power management
Outputs | I2C Signal Output: The converted analog input signal is transmitted to the microcontroller through I2C interface (SDA/SCL).
Functionality | The 16-bit ADC module samples the external analog input from connected sensors, conditions the signal using an internal gain amplifier, and converts it into a high-resolution digital value. The resulting digital data is transmitted to the microcontroller through the I2C interface.

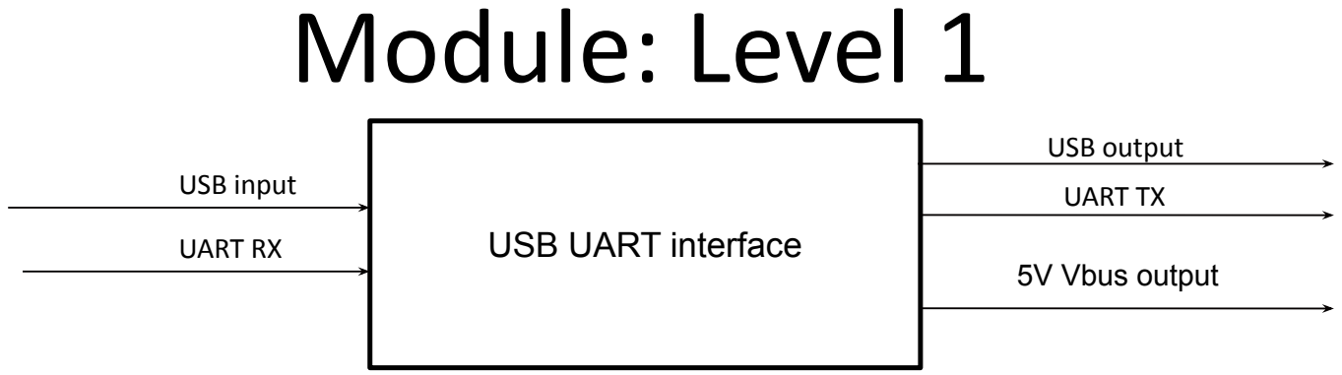
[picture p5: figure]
Module: Level 1; USB UART interface; USB input; UART TX; 5V Vbus output; USB output; UART RX

Module | USB UART interface
Inputs | USB Input: USB data and 5 V power supplied from a computer through the USB connector UART RX: Serial data received from the microcontroller.
Outputs | USB Output: Serial data transmitted back to the computer through the USB connection (converted from UART). UART TX: Serial data transmitted to the microcontroller 5 V VBUS Output: Provides the 5 V USB power to the power-management subsystem.
Functionality | The USB UART interface converts USB data from the computer into UART signals that the our microcontroller can process and convert the MCU UART back into USB communication with the host computer. This module also forwards the USB 5V VBUS supply to our power management block, enabling our system to operate or charge our battery when connecting to a USB port

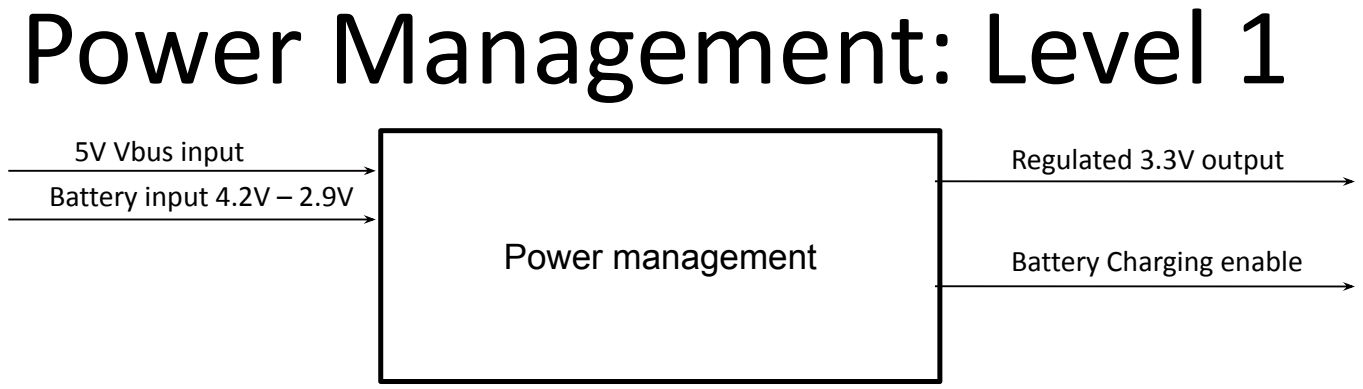
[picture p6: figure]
Power Management: Level 1; Power management; 5V Vbus input; Battery input 4.2V – 2.9V; Regulated 3.3V output; Battery Charging enable

Module | Power Management Module
Inputs | 5 V VBUS Input: USB-supplied 5 V provided through the USB-UART interface. This voltage is used to power the system and to charge the battery. Battery Input (4.2 V – 2.9 V): Li-ion battery voltage supplied, used when USB is not connected.
Outputs | Regulated 3.3 V Output: Primary logic-level power rail used by the microcontroller, ADC module, peripherals, and sensors. Battery Charging Enable : Managed charging of the Li-ion battery using the charger IC when USB power is available.
Functionality | The Power Management module automatically manages all system power sources. It selects between USB 5 V and the battery using a power-mux, charges the Li-ion battery when USB is connected, and provides a stable 3.3 V rail for all system components. An internal 5 V regulator is also used within the power circuitry if using battery to make continuous operation and seamless transitions between USB and battery power mode.

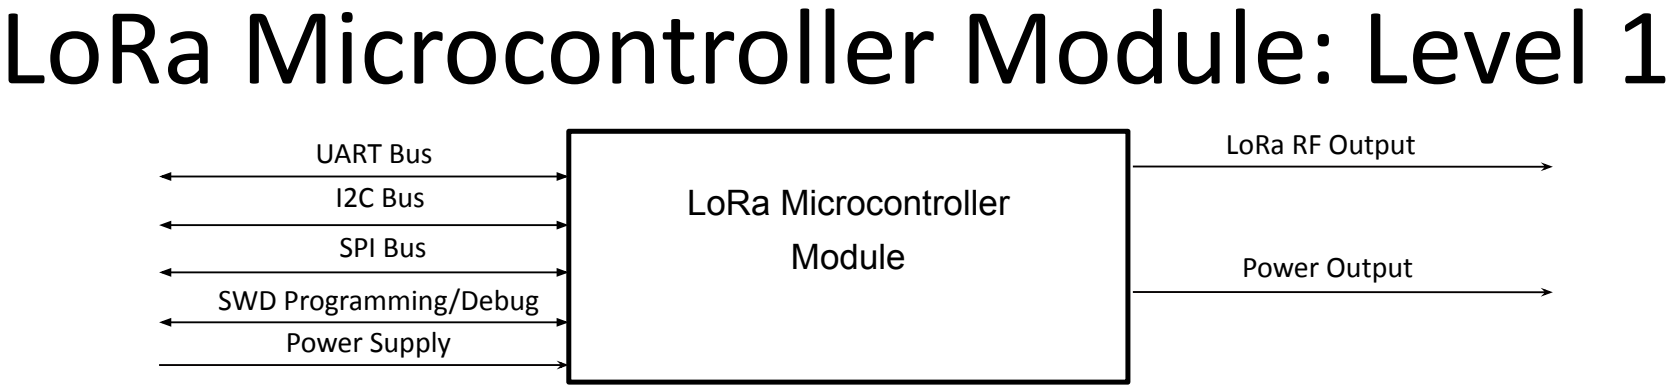
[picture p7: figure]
LoRa Microcontroller Module: Level 1; LoRa Microcontroller; Module; UART Bus; I2C Bus; SPI Bus; Power Supply; LoRa RF Output; Power Output; SWD Programming/Debug

Module | LoRa Microcontroller Module
Data interface I/O and power | UART Interface: Bidirectional serial communication with the USB-UART interface (TX/RX). I2C Bus: Bidirectional digital interface used to communicate with the ADC, EEPROM, and external I2C sensors. SPI Bus: Bidirectional digital interface used for SD card storage and Read. Programming/Debug Interface: SWD bidirectional interface for firmware programming and debugging (ST-Link). Power Supply: 3.3 V regulated input from the Power Management Module.
External Outputs | LoRa RF Output: 902–928 MHz radio-frequency output for wireless transmission. Power Output: 3.3 V for sensors power supply
Functionality | The LoRa Microcontroller Module manages system control, communicates with digital sensors, and storage devices, and sends collected data through the 902–928 MHz LoRa radio. It interfaces with the ADC, EEPROM, SD card, and USB-UART bridge through UART, I2C, and SPI buses. The module runs on a 3.3 V supply and supports firmware programming and debugging via the SWD interface.

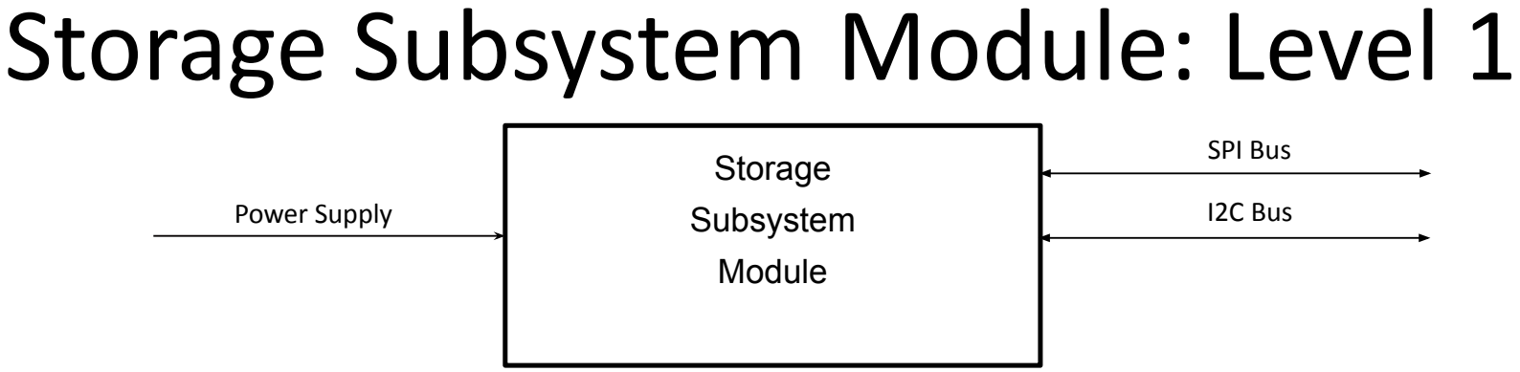
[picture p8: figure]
Storage Subsystem Module: Level 1; Storage; Subsystem; Module; SPI Bus; Power Supply; I2C Bus

Module | Storage Subsystem Module
Data interface I/O | SPI Bus: Bidirectional SPI communication interface used to read from and write to the micro-SD card. I2C Bus: Bidirectional I²C interface used for accessing the onboard EEPROM for configuration and calibration data.
Input | Power Supply: 3.3 V regulated power from the Power Management Module
Functionality | The Storage Subsystem Module provides digital storage for the DAQ system. The micro-SD card stores large amounts of sensor data through the SPI bus, while the EEPROM stores small configuration values or calibration data over the I2C bus. Together, these support long-term data logging and persistent system settings for debugging and validation.

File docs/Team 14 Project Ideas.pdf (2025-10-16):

# Team 14 Project Ideas

Eyad Ahmed, Daniel Monahan, Dingyu (Eric) Zhou, Manaf Alali, Saleh Sabti

### Project 1: LoRA DAQ Boards (Preferred Choice)

A brief project description of the idea; i.e., the concept of operation

For this project we would be creating a device to collect data from environmental sensors for field research applications and use a LoRA radio module transmit data to a central gateway.

List the sensor(s)
ADS1115 16bit adc, I2C header to support following:

* Temp and humidity sensor DHT11

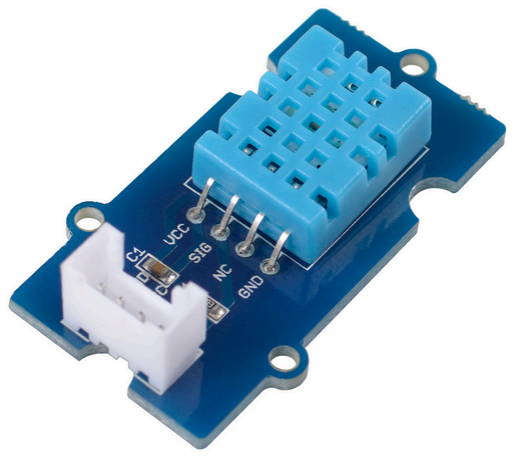
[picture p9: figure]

* SEN-13322 soil moisture sensor

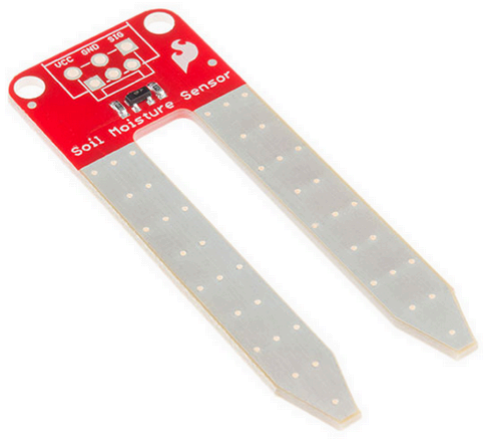
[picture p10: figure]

List the controller(s)
LoRA Transceiver & MCU: Wio-E5 Wireless Module - STM32WLE5JC, ARM Cortex-M4 and SX126x embedded, supports LoRaWAN on EU868 & US915

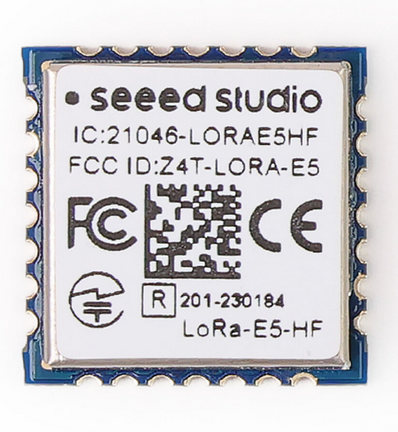
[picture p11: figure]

List the actuator(s)
CP2102 USB to UART bridge (for USB interface)

On-board LoRA TX module

LoRA Antenna (Seeed 113070002)

### Project 2: DRA818V Walkie-Talkie

A brief project description of the idea; i.e., the concept of operation
A Walkie talkie for two way radio communication using the DRA818V transceiver module. The module would use the VHF Band for communication.

List the sensor(s)
Microphone

Keypad input

DRA818V transceiver module

List the controller(s)
Microcontroller (eg. stm32g4)

List the actuator(s)
Speaker

DRA818V transceiver module

### Project 3: Tunable PID Controller for lever position

A brief project description of the idea; i.e., the concept of operation
A tunable PID controller that controls the position of a lever arm to match a user-defined set point. The ‘tunable’ part meaning that the user has the ability to set the three PID coefficients via Rotary encoder

List the sensor(s)
Rotary encoder (eg. KY-040)

List the controller(s)
Microcontroller (eg. stm32g4)

List the actuator(s)
Motor Controller (eg. DRV8304 )

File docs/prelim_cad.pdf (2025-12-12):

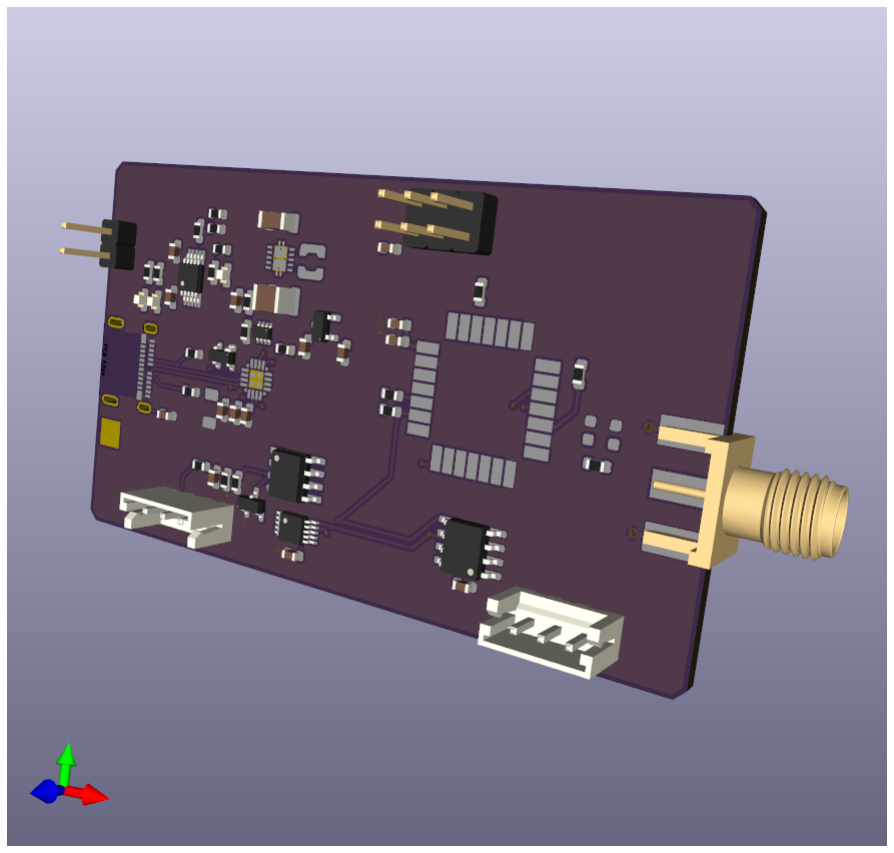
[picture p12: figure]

1

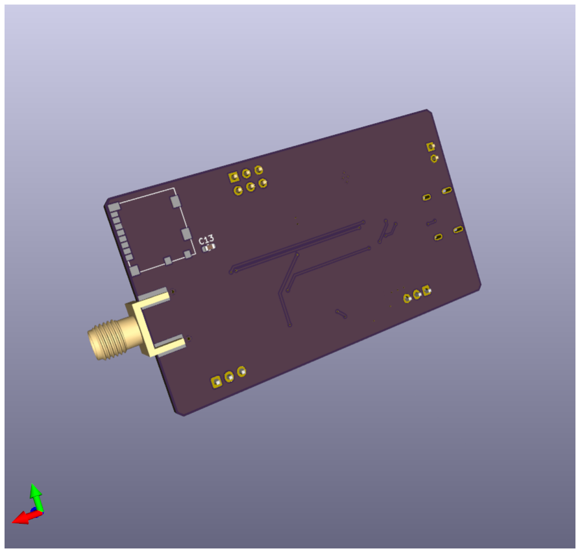
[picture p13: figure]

2

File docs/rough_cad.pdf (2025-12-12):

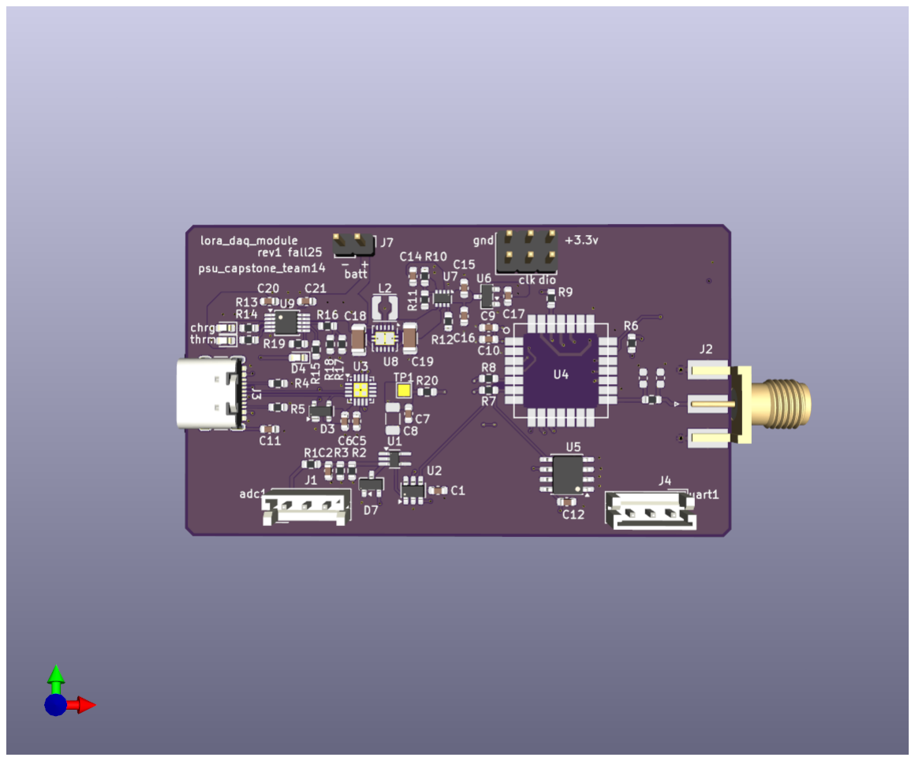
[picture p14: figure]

1

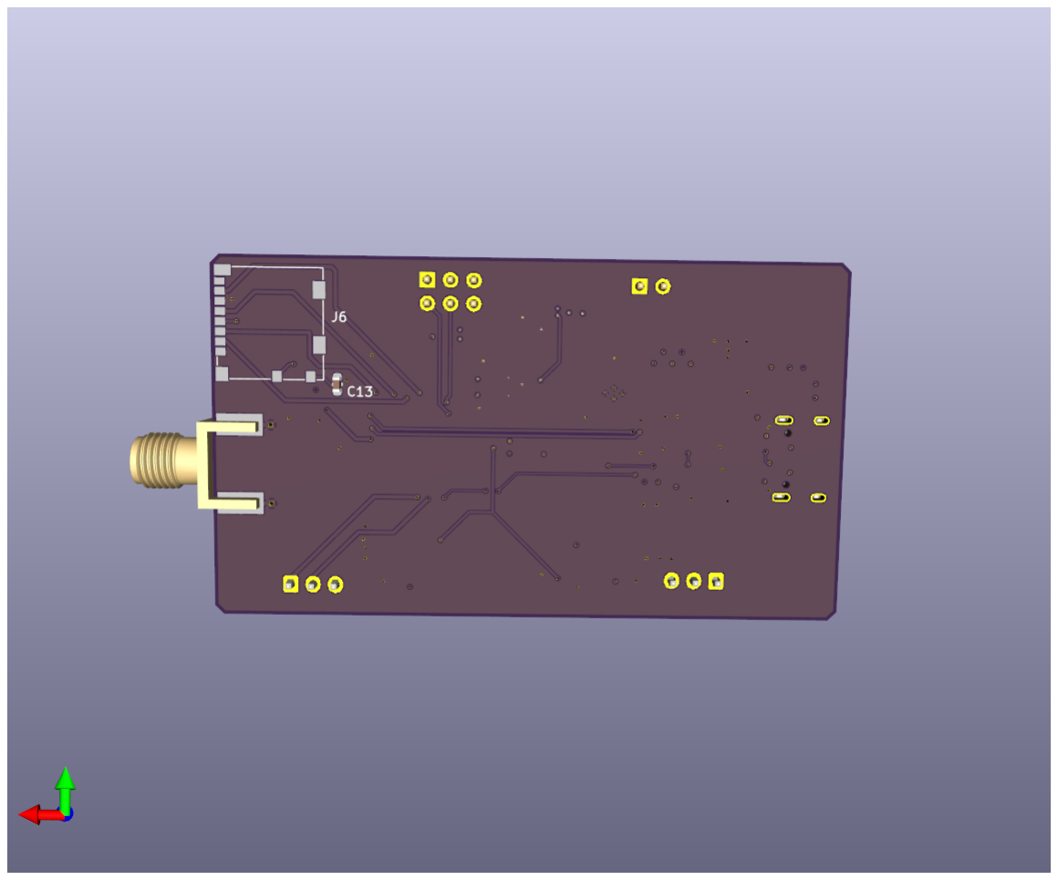
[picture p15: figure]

2

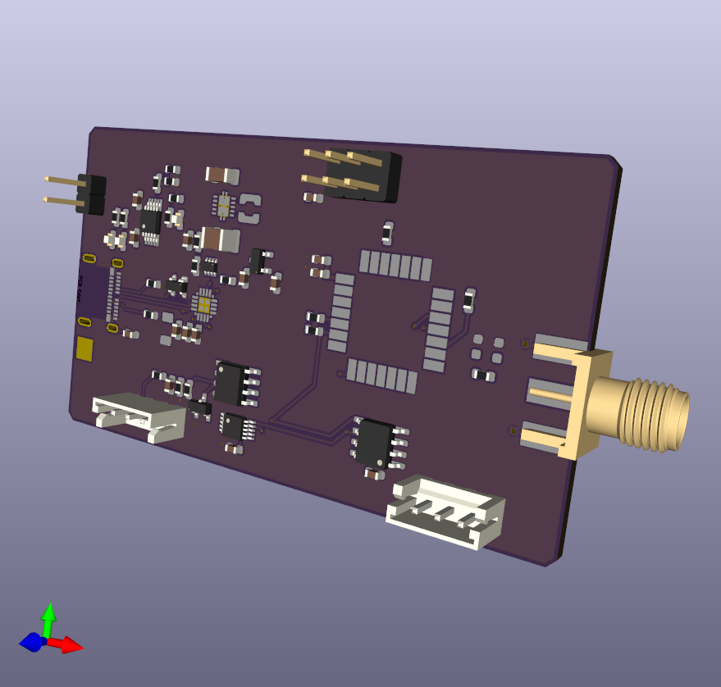
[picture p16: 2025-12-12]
docs/lora_daq_module_prelim_cad_top.png

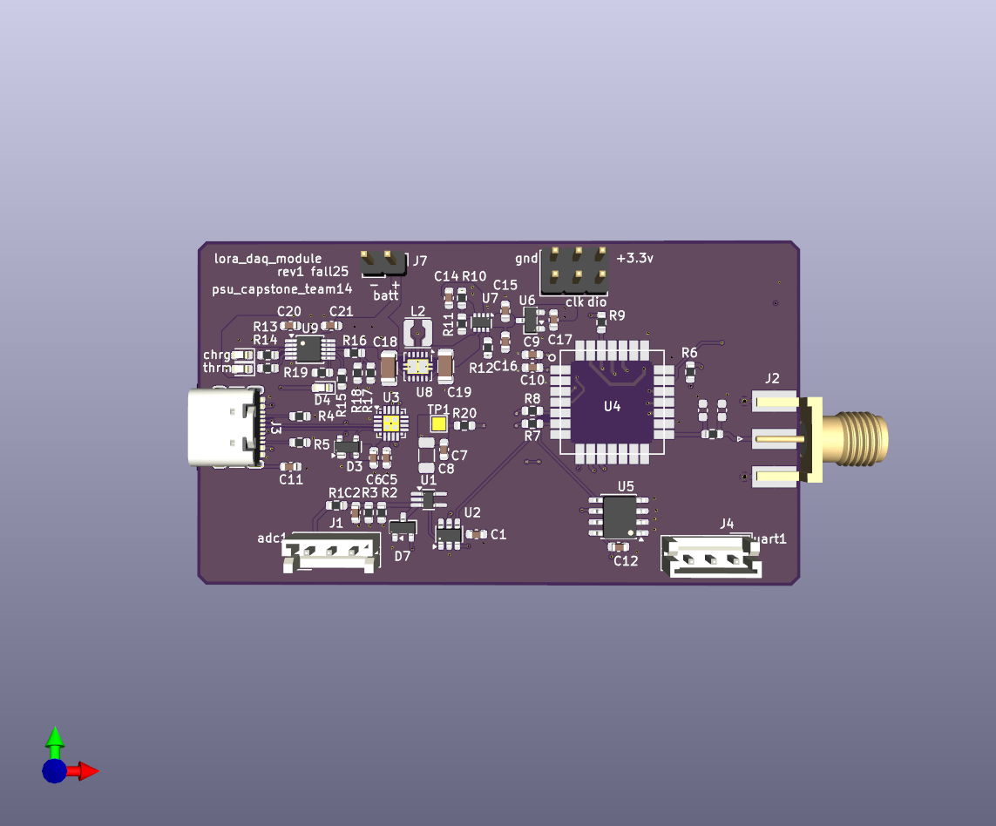
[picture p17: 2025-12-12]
docs/lora_daq_module_rough_cad_top.png

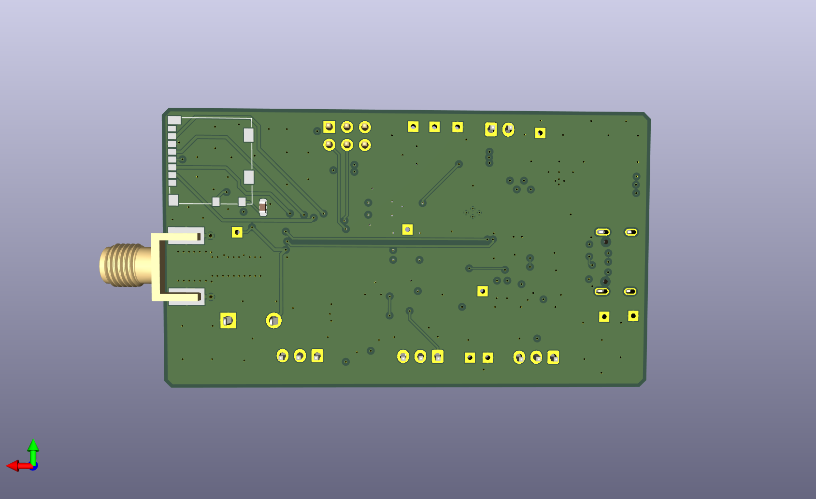
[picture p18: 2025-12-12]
docs/lora_daq_module_final_bottom.png

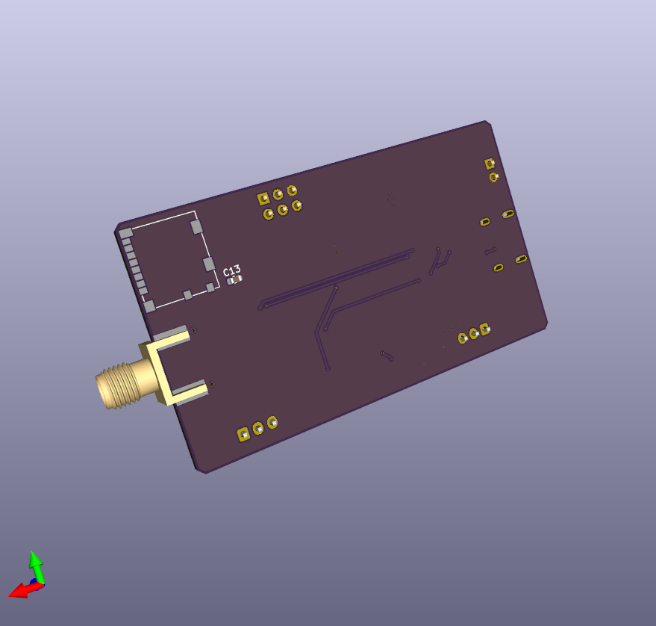
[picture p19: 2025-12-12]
docs/lora_daq_module_prelim_cad_bottom.png

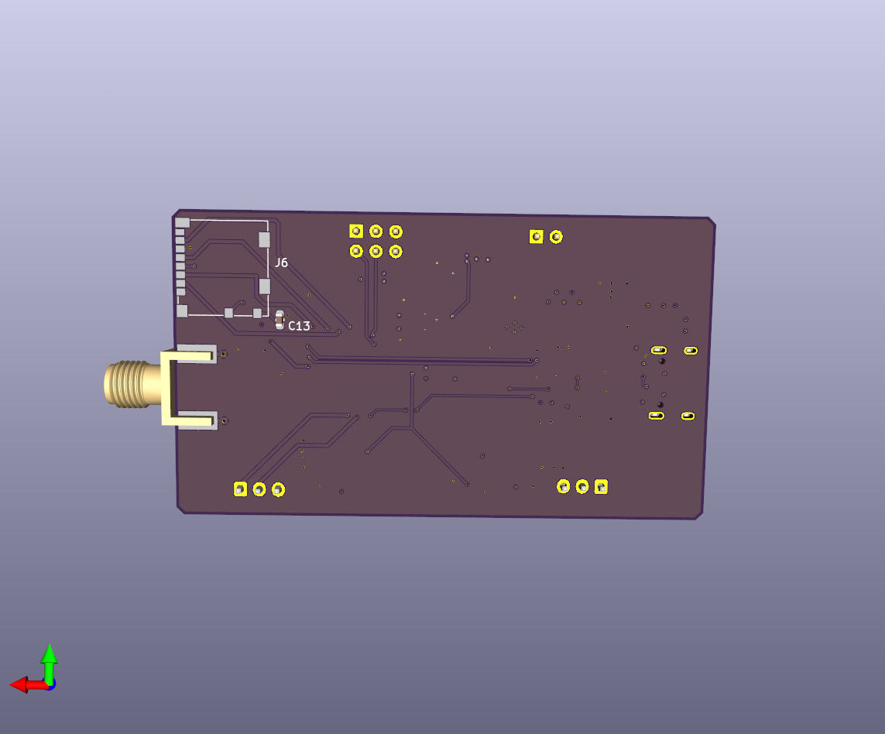
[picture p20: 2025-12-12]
docs/lora_daq_module_rough_cad_bottom.png

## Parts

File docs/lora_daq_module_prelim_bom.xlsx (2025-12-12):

Bill Of Materials for: Team 14
Last modified: Nov. 14th 2025
PCB version: rev1.0
BOM revision: r0
Qty | Reference Designators | Mfr | Mfr Part Number | Description | Dist | Dist Part Number | Cost Ea. | Cost Total
1 | C18 | Samsung Electro-Mechanics | CL31A106KBHNNNE | CAP CER 10UF 50V X5R 1206 | Digi-Key | 1276-2876-1-ND | $0.09 | $0.09
1 | C19 | TDK Corporation | C3216JB1C336M160AB | CAP CER 33UF 16V JB 1206 | Digi-Key | 445-11694-1-ND | $1.05 | $1.05
5 | C1,C6,C7,C9,C12 | YAGEO | CC0603KRX7R7BB104 | CAP CER 0.1UF 16V X7R 0603 | Digi-Key | 311-1088-1-ND | $0.08 | $0.40
2 | C11,C13 | Murata Electronics | GCM188R72A103KA37D | CAP CER 10000PF 100V X7R 0603 | Digi-Key | 490-4781-1-ND | $0.10 | $0.20
2 | C2,C14 | YAGEO | CC0603KRX7R8BB473 | CAP CER 0.047UF 25V X7R 0603 | Digi-Key | 311-1373-1-ND | $0.10 | $0.20
7 | C5,C10,C15,C16,C17,C20,C21 | Murata Electronics | GCM188R71C105KA64D | CAP CER 1UF 16V X7R 0603 | Digi-Key | 490-5241-1-ND | $0.15 | $1.05
1 | D3 | Littelfuse Inc. | SP0503BAHTG | TVS DIODE 5.5VWM 8.5VC SOT1434 | Digi-Key | F2715CT-ND | $0.60 | $0.60
1 | D4 | Lite-On Inc. | LTST-C191KGKT | LED GREEN CLEAR SMD | Digi-Key | 160-1446-1-ND | $0.15 | $0.15
1 | D5 | Lite-On Inc. | LTST-C191KSKT | LED YELLOW CLEAR SMD | Digi-Key | 160-1448-1-ND | $0.15 | $0.15
1 | D6 | Lite-On Inc. | LTST-C190KRKT | LED RED CLEAR CHIP SMD | Digi-Key | 160-1436-1-ND | $0.14 | $0.14
1 | D7 | Diotec Semiconductor | BAS40-04 | DIODE ARR SCHOTT 40V 200MA SOT23 | Digi-Key | 4878-BAS40-04CT-ND | $0.12 | $0.12
1 | J1 | JST Sales America Inc. | B3B-EH-A | CONN HEADER VERT 3POS 2.5MM | Digi-Key | 455-B3B-EH-A-ND | $0.11 | $0.11
1 | J2 | Molex | 732511153 | SMA JACK EDGE MOUNT 50 OHM | Digi-Key | 900-0732511153-ND | $3.83 | $3.83
1 | J3 | Molex | 1054500101 | CONN RCP USB3.1 TYPEC 24P SMD RA | Digi-Key | WM12856CT-ND | $2.40 | $2.40
1 | J4 | JST Sales America Inc. | B3B-EH-A | CONN HEADER VERT 3POS 2.5MM | Digi-Key | 455-B3B-EH-A-ND | $0.11 | $0.11
1 | J5 | Würth Elektronik | 61300621121 | CONN HEADER VERT 6POS 2.54MM | Digi-Key | 732-5295-ND | $0.51 | $0.51
1 | J6 | Molex | 1040310811 | CONN MICRO SD CARD R/A SMD | Digi-Key | WM6357CT-ND | $2.04 | $2.04
1 | J7 | Würth Elektronik | 61300211121 | CONN HEADER VERT 2POS 2.54MM | Digi-Key | 732-5315-ND | $0.12 | $0.12
1 | L1 | Vishay Dale | TNPW120650R0BEEN | RES 50 OHM 0.1% 0.52W 1206 | Digi-Key | 541-TNPW120650R0BEENCT-ND | $0.62 | $0.62
1 | L2 | Coilcraft | LPS3015-332MRC | FIXED IND 3.3UH 1.4A 130MOHM SMD | Digi-Key | 2457-LPS3015-332MRC-ND | $1.43 | $1.43
1 | R1 | YAGEO | RC0603FR-0747KL | RES 47K OHM 1% 1/10W 0603 | Digi-Key | 311-47.0KHRCT-ND | $0.10 | $0.10
1 | R2 | Stackpole Electronics Inc | RMCF0603FT220K | RES 220K OHM 1% 1/10W 0603 | Digi-Key | RMCF0603FT220KCT-ND | $0.10 | $0.10
1 | R10 | YAGEO | RC0603FR-07680KL | RES 680K OHM 1% 1/10W 0603 | Digi-Key | 311-680KHRCT-ND | $0.10 | $0.10
1 | R11 | Stackpole Electronics Inc | RMCF0603FT470K | RES 470K OHM 1% 1/10W 0603 | Digi-Key | RMCF0603FT470KCT-ND | $0.10 | $0.10
1 | R17 | Murata Electronics | NCU18XH103F60RB | THERMISTOR NTC 10KOHM 3380K 0603 | Digi-Key | 490-16279-1-ND | $0.14 | $0.14
1 | R18 | Stackpole Electronics Inc | RMCF0603FT150K | RES 150K OHM 1% 1/10W 0603 | Digi-Key | RMCF0603FT150KCT-ND | $0.10 | $0.10
3 | R13,R14,R15 | YAGEO | RC0603JR-07470RL | RES 470 OHM 5% 1/10W 0603 | Digi-Key | 311-470GRCT-ND | $0.10 | $0.30
3 | R3,R16,R19 | Stackpole Electronics Inc | RMCF0603FT1K00 | RES 1K OHM 1% 1/10W 0603 | Digi-Key | RMCF0603FT1K00CT-ND | $0.10 | $0.30
2 | R4,R5 | YAGEO | RC0603FR-075K1L | RES 5.1K OHM 1% 1/10W 0603 | Digi-Key | 311-5.10KHRCT-ND | $0.10 | $0.20
5 | R6,R7,R8,R9,R12 | YAGEO | RC0603JR-074K7L | RES 4.7K OHM 5% 1/10W 0603 | Digi-Key | 311-4.7KGRCT-ND | $0.10 | $0.50
1 | U1 | Texas Instruments | OPA333AIDCKR | IC OPAMP ZERO-DRIFT 1CIRC SC70-5 | Digi-Key | 296-19547-1-ND | $1.88 | $1.88
1 | U2 | Texas Instruments | ADS1110A0IDBVR | IC ADC 16BIT SIGMA-DELTA SOT23-6 | Digi-Key | 296-25890-1-ND | $4.73 | $4.73
1 | U3 | Silicon Labs | CP2102N-A02-GQFN20R | IC USB TO UART BRIDGE QFN20 | Digi-Key | 336-5886-1-ND | $5.59 | $5.59
1 | U4 | Seeed Technology Co., Ltd | 317990829 | RF TXRX MOD ISM<1GHZ SMD LORA | Digi-Key | 1597-317990829CT-ND | $7.68 | $7.68
1 | U5 | onsemi | CAT24C256WI-GT3 | IC EEPROM 256KBIT I2C 1MHZ 8SOIC | Digi-Key | CAT24C256WI-GT3OSCT-ND | $0.53 | $0.53
1 | U6 | Microchip Technology | MCP1700T-3302E/TT | IC REG LINEAR 3.3V 250MA SOT23-3 | Digi-Key | MCP1700T3302ETTCT-ND | $0.51 | $0.51
1 | U7 | Texas Instruments | TPS2116DRLR | 1.6-V TO 5.5-V, 40-M, 2.5-A, LOW | Digi-Key | 296-TPS2116DRLRCT-ND | $0.90 | $0.90
1 | U8 | Texas Instruments | TPS63002DRCR | IC REG BUCK BOOST 5V 1.6A 10VSON | Digi-Key | 296-19644-1-ND | $2.44 | $2.44
1 | U9 | Microchip Technology | MCP73833T-AMI/UN | IC BATT CNTRL LI-ION 1CEL 10MSOP | Digi-Key | MCP73833T-AMI/UNCT-ND | $1.14 | $1.14
 |  |  |  |  |  |  | TOTAL | $42.66
VERSION INFO
Rev | Date
1.0r0 | 2025-11-14

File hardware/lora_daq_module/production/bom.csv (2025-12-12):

Designator | Footprint | Quantity | Value | LCSC Part #
C1, C12, C6, C7, C9 | 0603 | 5 | .1u
C10, C15, C16, C17, C20, C21, C5 | 0603 | 7 | 1u
C11, C13 | 0603 | 2 | 10n
C14 | 0603 | 1 | 47n
C18 | 1206 | 1 | 10u
C19 | 1206 | 1 | 33u
C2 | 0603 | 1 | 4.7u
C8 | 1206 | 1 | 4.7u
D3 | SOT-143 | 1 | SP0503BAHT
D4 | 0603 | 1 | Green
D5 | 0603 | 1 | Yellow
D6 | 0603 | 1 | Red
D7 | SOT-23 | 1 | BAS40-04
J1 | JST_EH_B3B-EH-A_1x03_P2.50mm_Vertical | 1 | JST3pinfemale
J2 | SMA_Molex_73251-1153_EdgeMount_Horizontal | 1 | SMA_Edge_50Ω | CONSMA001-C-G
J3 | USB_C_Receptacle_GCT_USB4105-xx-A_16P_TopMnt_Horizontal | 1 | USB_C_Receptacle_USB2.0_14P
J4 | JST_EH_B3B-EH-A_1x03_P2.50mm_Vertical | 1 | EXT_UART
J5 | PinHeader_2x03_P2.54mm_Vertical | 1 | SWD
J6 | microSD_HC_Molex_104031-0811 | 1 | Micro_SD_Card_Det1
J7 | JST_EH_B2B-EH-A_1x02_P2.50mm_Vertical | 1 | jst_b2beh
J8 | JST_EH_B3B-EH-A_1x03_P2.50mm_Vertical | 1 | EXT_I2C
L1 | 0402 | 1 | 0
L2 | L_Coilcraft_LPS3010 | 1 | 3.3uH
R1 | 1206 | 1 | 47
R10 | 0603 | 1 | 680k
R11 | 0603 | 1 | 470k
R12, R2, R3, R6, R7, R8, R9 | 0603 | 7 | 4.7k
R13, R14, R15 | 0603 | 3 | 470
R16, R19 | 0603 | 2 | 1k
R17 | 0603 | 1 | 10k_therm
R18 | 0603 | 1 | 150k
R20 | 0603 | 1 | 0
R21, R22, R23 | 1812 | 3 | 0
R4, R5 | 0603 | 2 | 5.1k
SW1 | SW_PUSH_1P1T_6x3.5mm_H5.0_APEM_MJTP1250 | 1 | MJTP1250
TP10 | TestPoint_THTPad_1.5x1.5mm_Drill0.7mm | 1 | tp_vbus
TP12 | TestPoint_THTPad_1.5x1.5mm_Drill0.7mm | 1 | tp_siggnd
TP13 | TestPoint_THTPad_1.5x1.5mm_Drill0.7mm | 1 | tp_batgnd
TP14 | TestPoint_THTPad_1.5x1.5mm_Drill0.7mm | 1 | tp_usbgnd
TP15 | TestPoint_THTPad_1.5x1.5mm_Drill0.7mm | 1 | tp_sig+
TP2 | TestPoint_THTPad_1.5x1.5mm_Drill0.7mm | 1 | tp_vbatt
TP3 | TestPoint_THTPad_1.5x1.5mm_Drill0.7mm | 1 | tp_5vbatt
TP4 | TestPoint_THTPad_1.5x1.5mm_Drill0.7mm | 1 | tp_5v
TP5 | TestPoint_THTPad_1.5x1.5mm_Drill0.7mm | 1 | tp_3v3
TP8 | TestPoint_THTPad_1.5x1.5mm_Drill0.7mm | 1 | tp_rusb
TP9 | TestPoint_THTPad_1.5x1.5mm_Drill0.7mm | 1 | tp_rstup
U1 | SOT-353_SC-70-5_Handsoldering | 1 | OPA333
U2 | SOT-23-6 | 1 | ADS1110A0IDBVR
U3 | SiliconLabs_QFN-20-1EP_3x3mm_P0.5mm_EP1.8x1.8mm | 1 | CP2102N-Axx-xQFN20
U4 | LoRa-E5 | 1 | Wio-E5_STM32WLE5JC
U5 | SOIC-8-1EP_3.9x4.9mm_P1.27mm_EP2.29x3mm | 1 | CAT24C256
U6 | SOT-23 | 1 | MCP1700x-330xxTT
U7 | SOT-583-8 | 1 | TPS2116DRL
U8 | Texas_DRC0010J_ThermalVias | 1 | TPS63002
U9 | MSOP-10_3x3mm_P0.5mm | 1 | MCP73833

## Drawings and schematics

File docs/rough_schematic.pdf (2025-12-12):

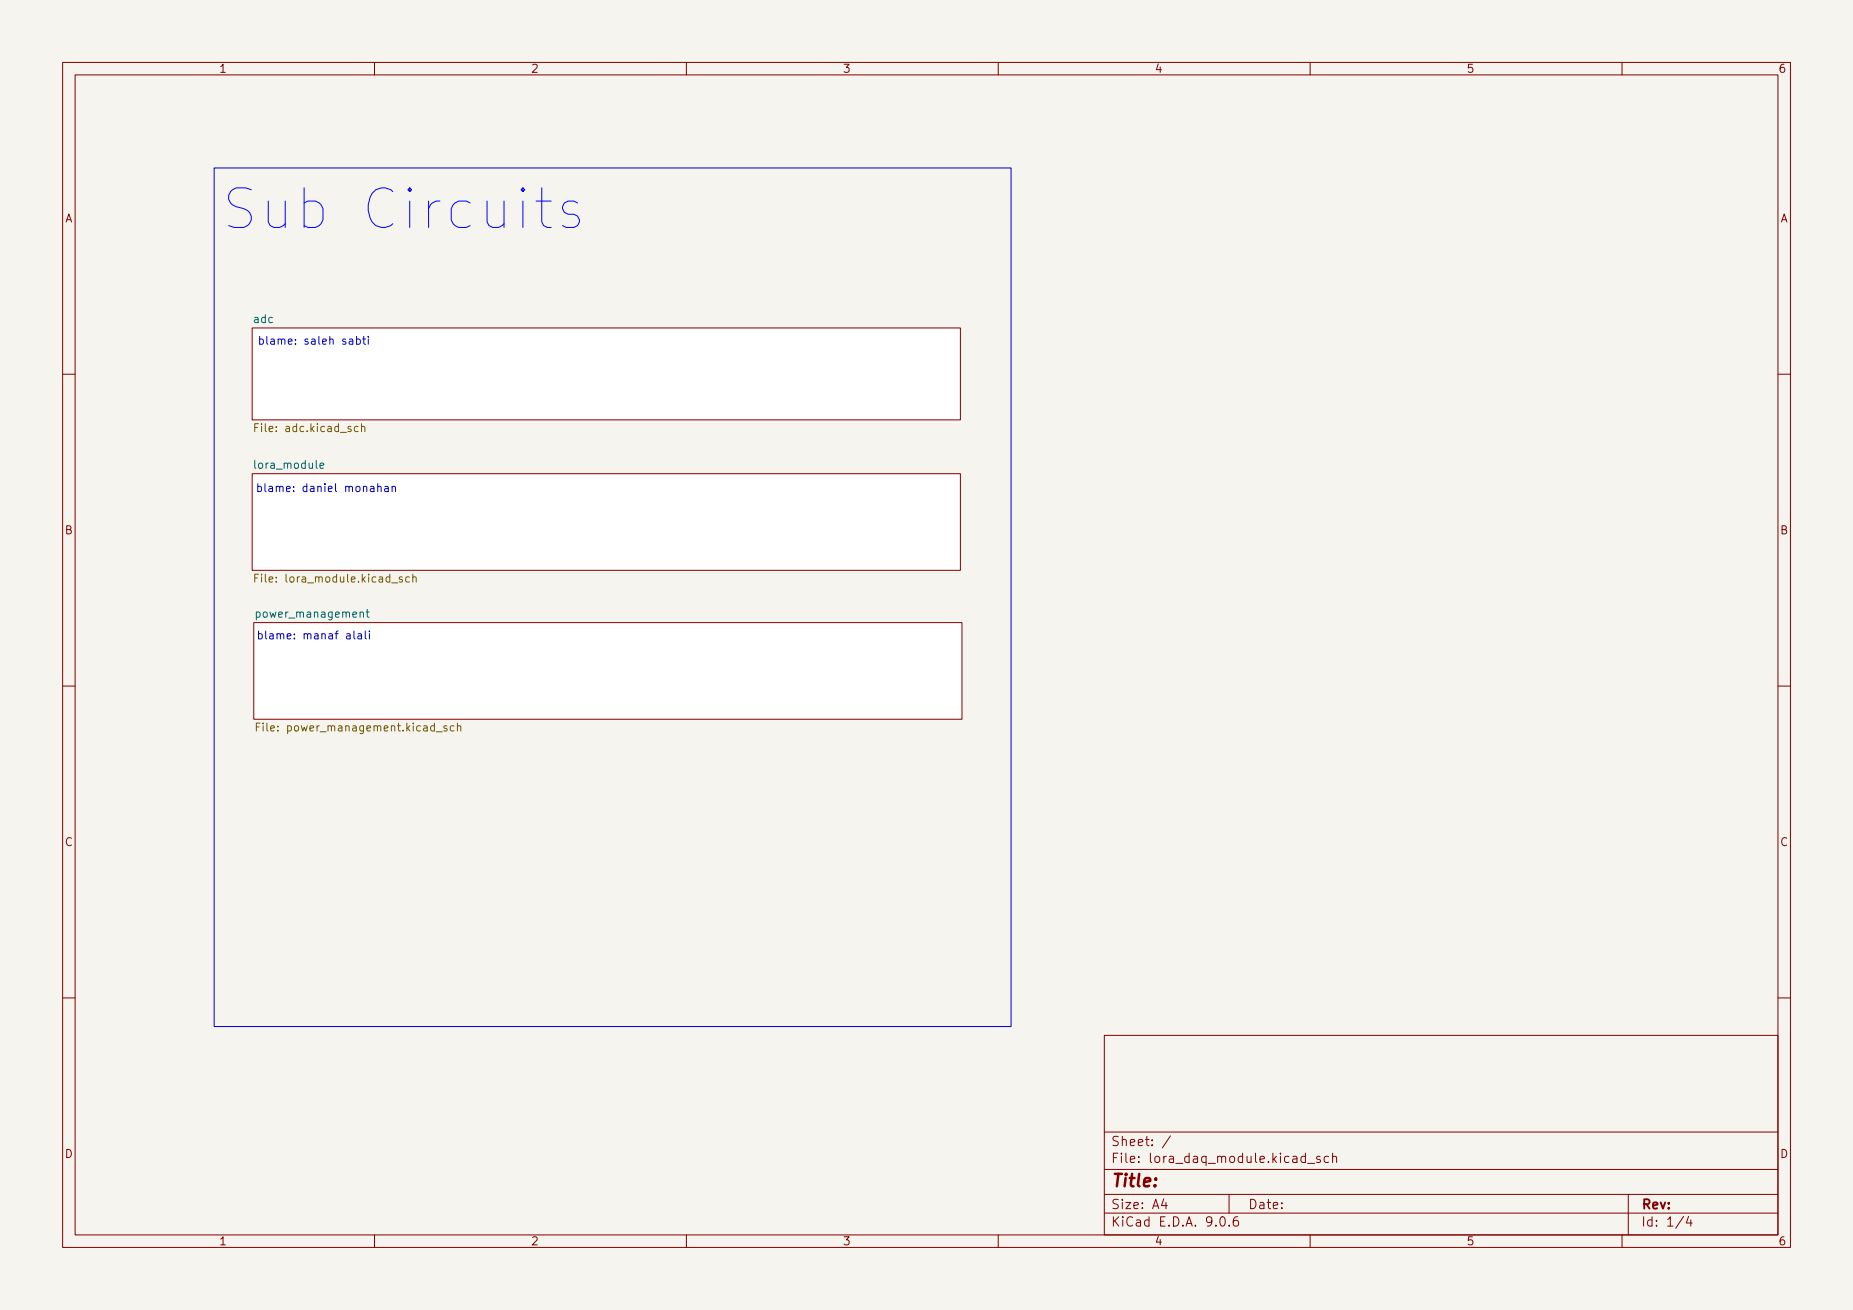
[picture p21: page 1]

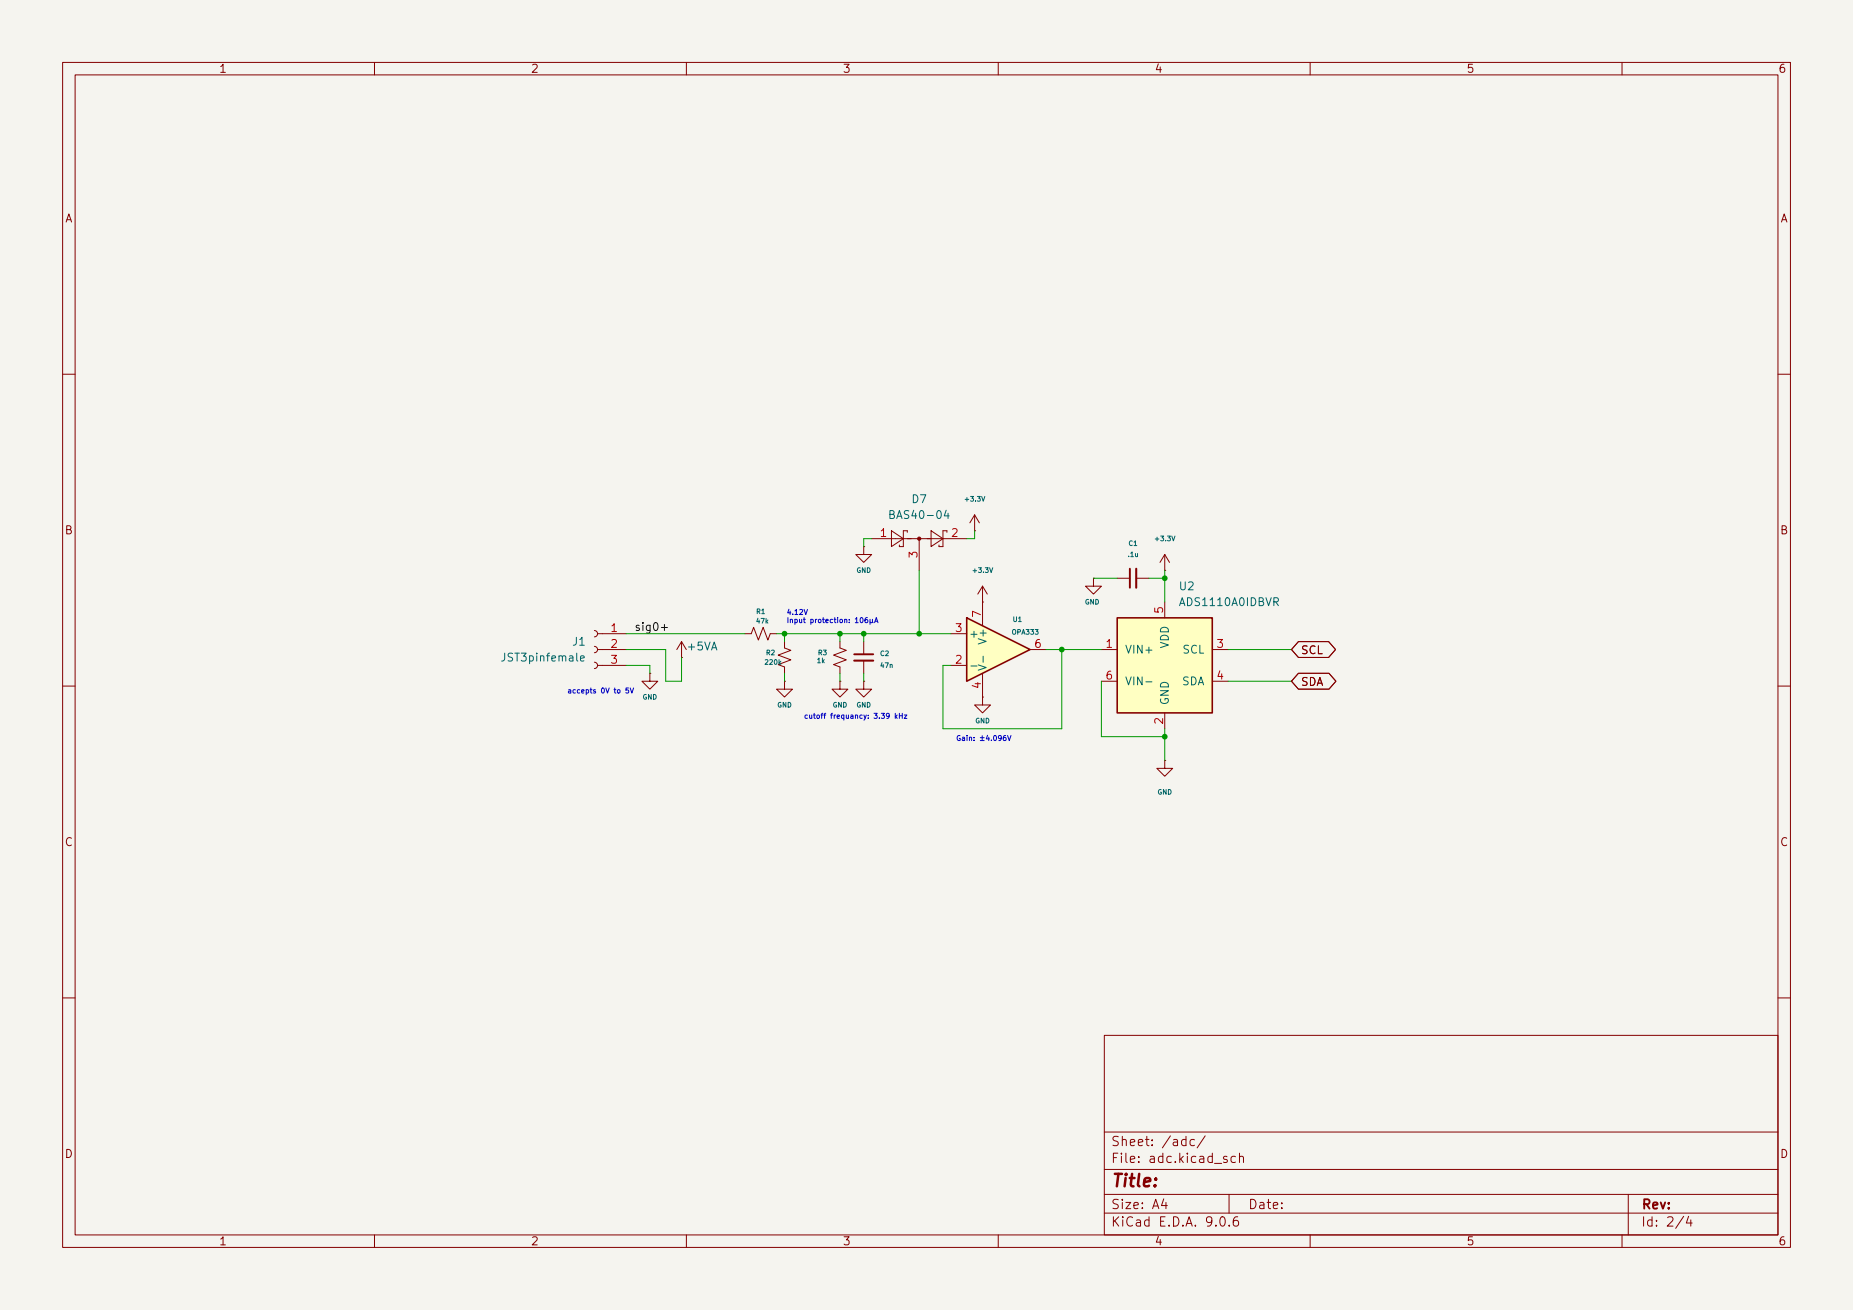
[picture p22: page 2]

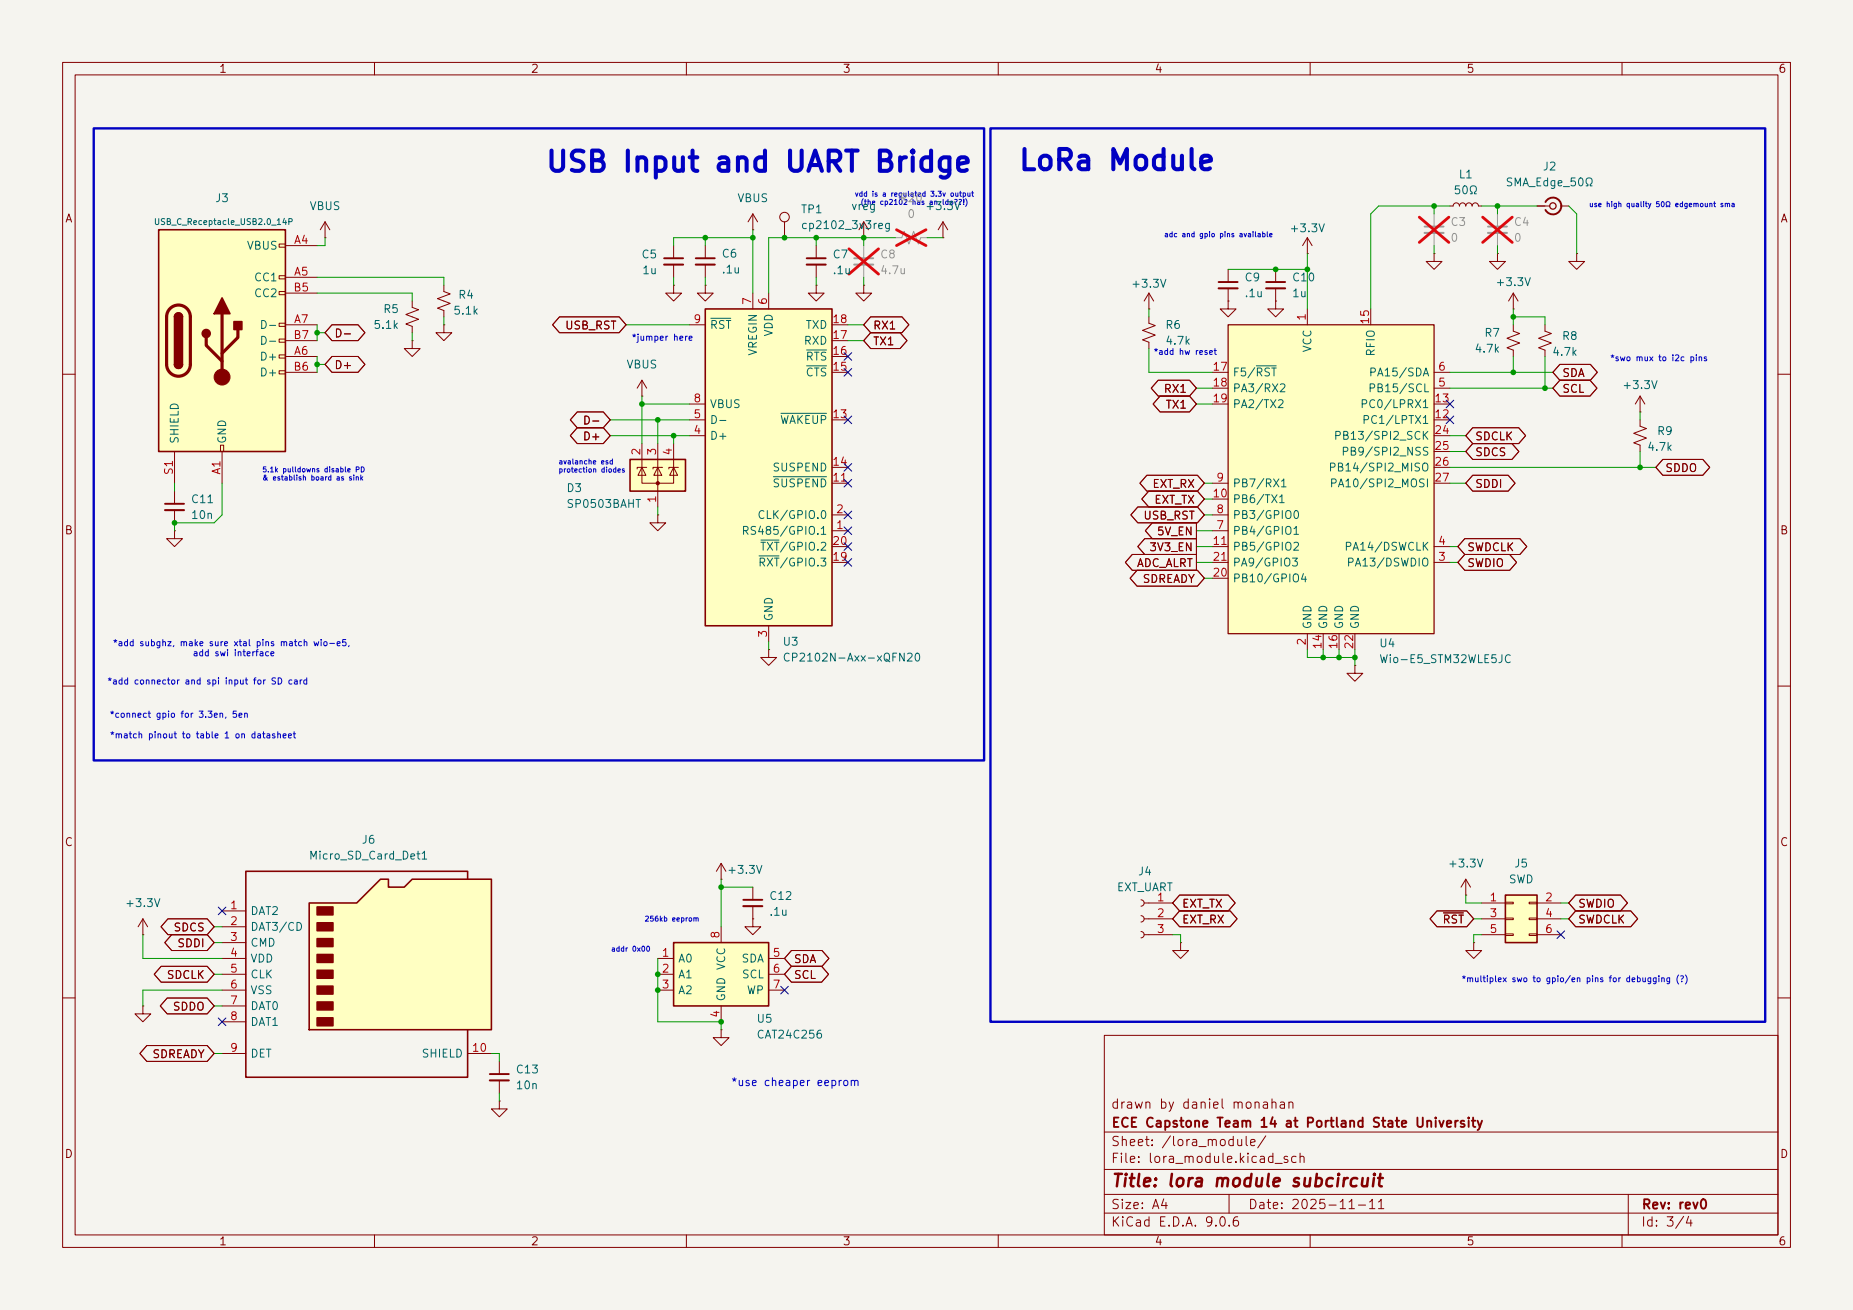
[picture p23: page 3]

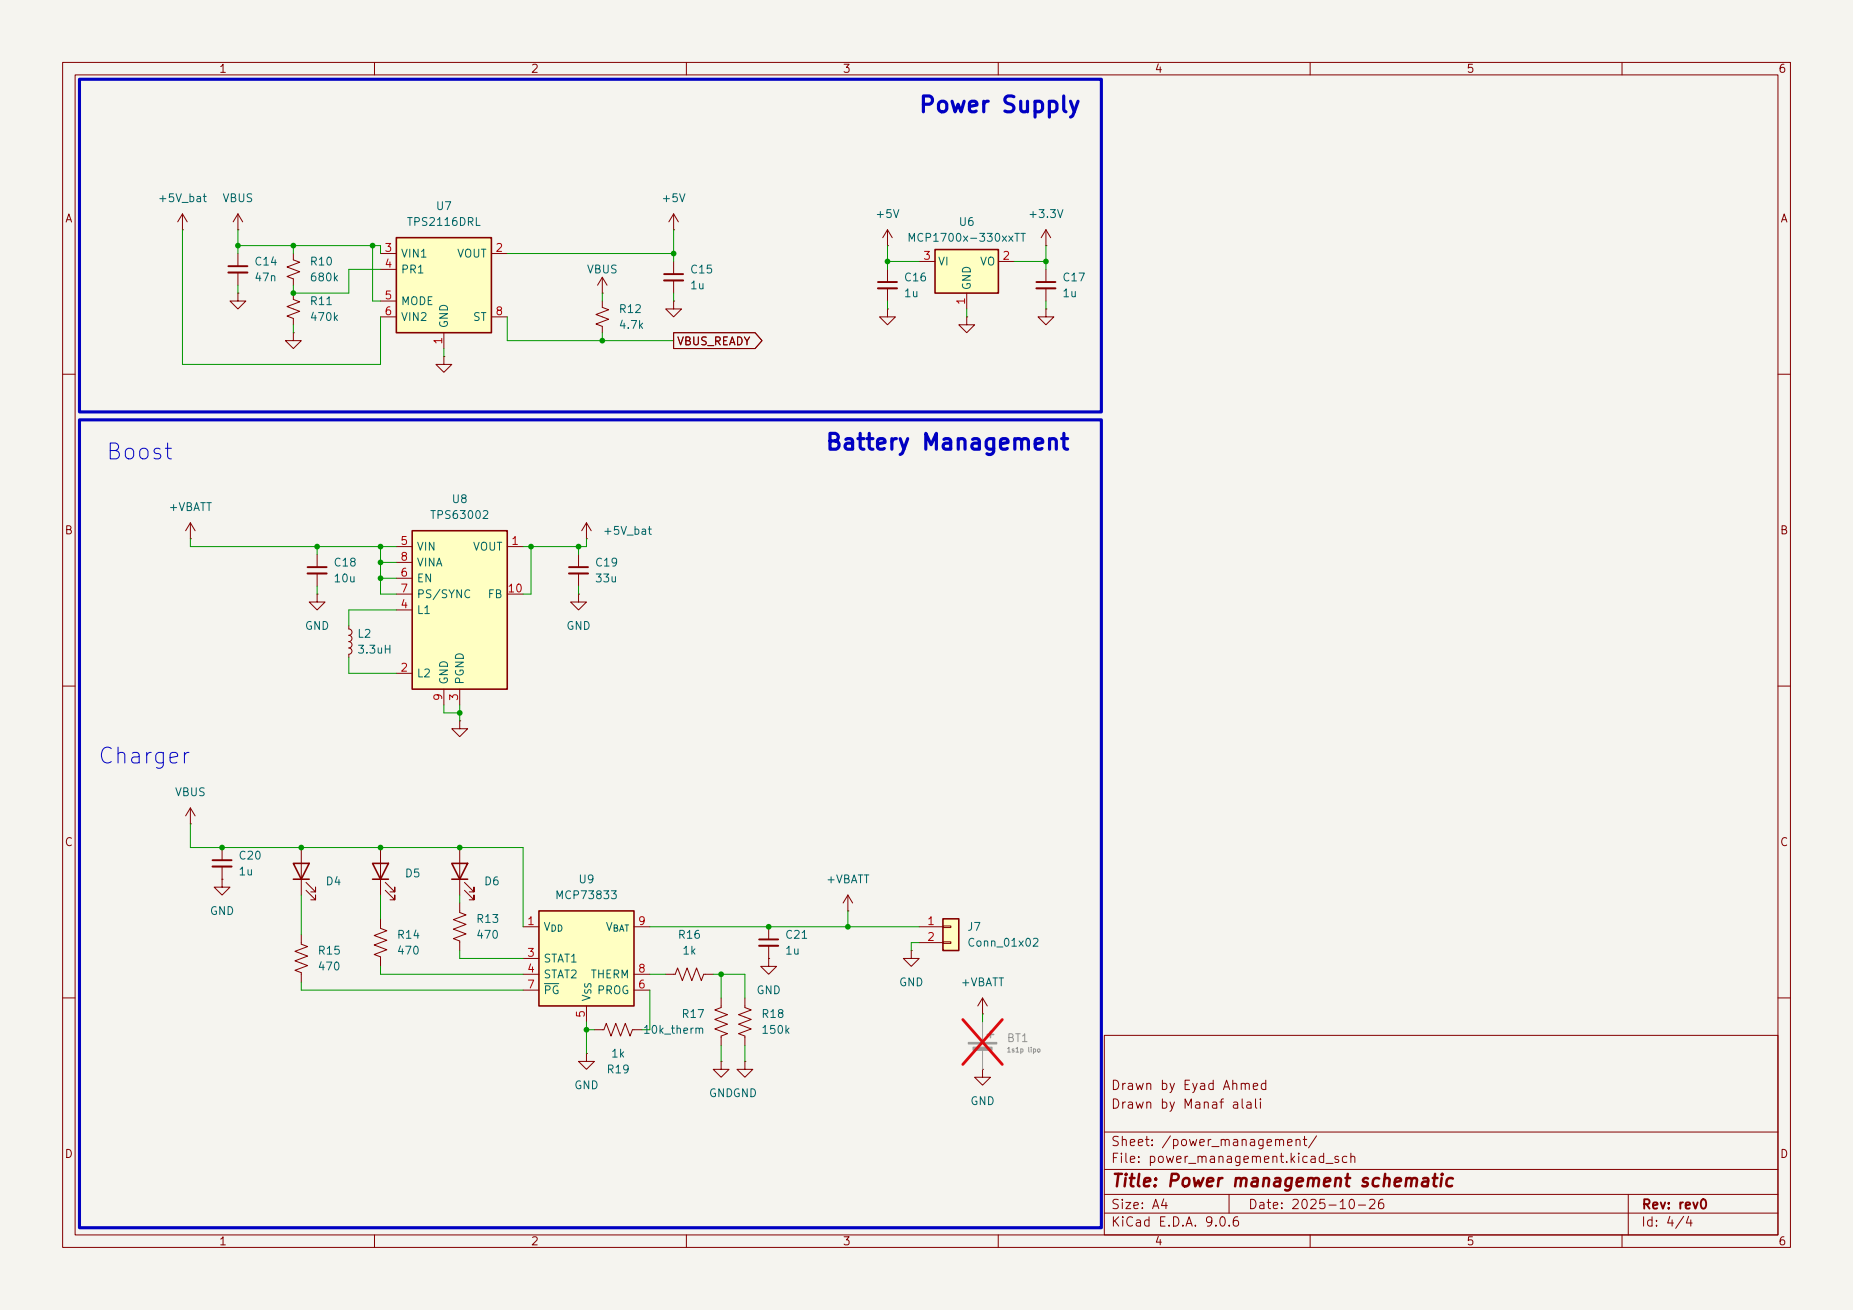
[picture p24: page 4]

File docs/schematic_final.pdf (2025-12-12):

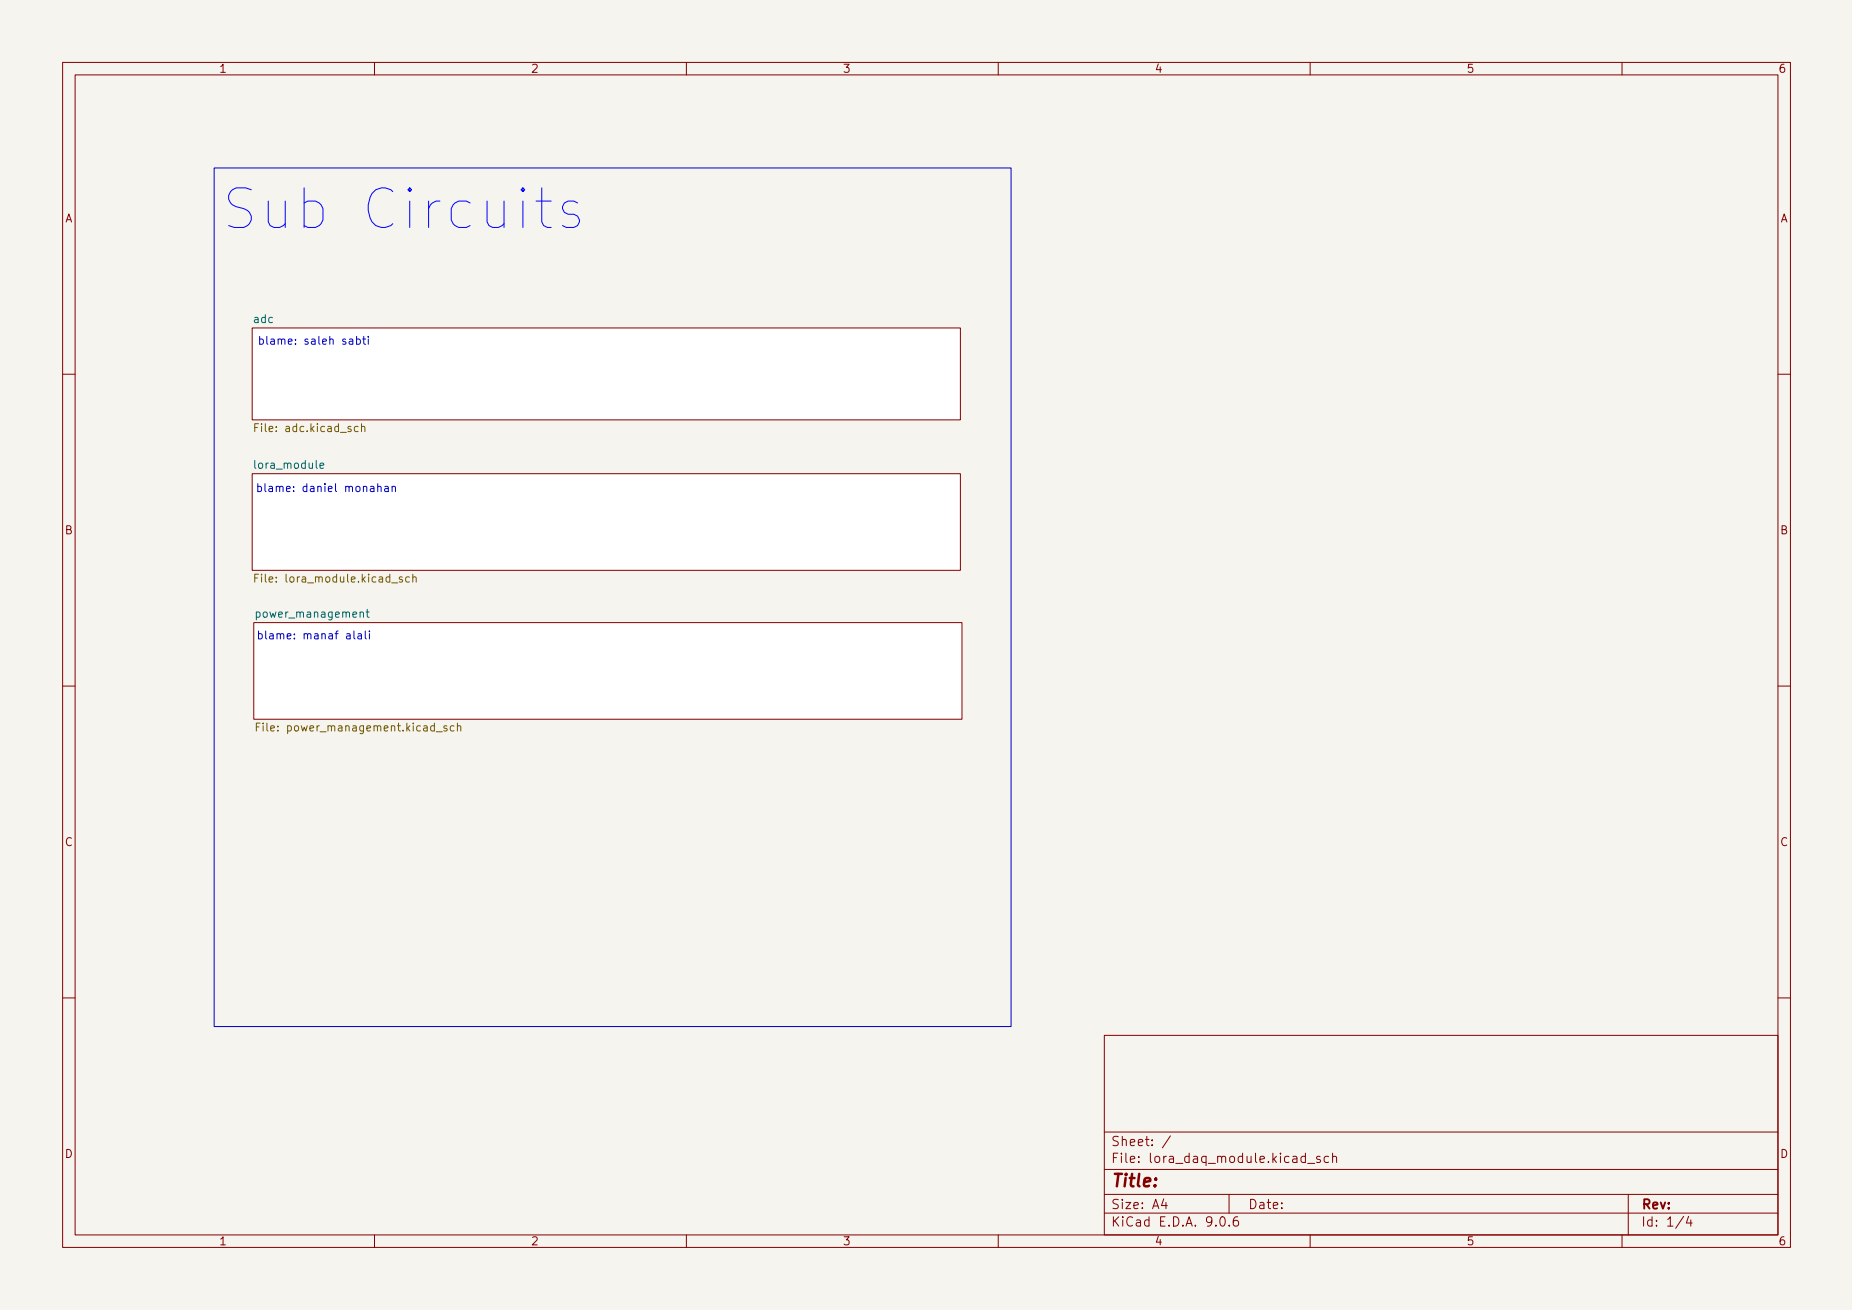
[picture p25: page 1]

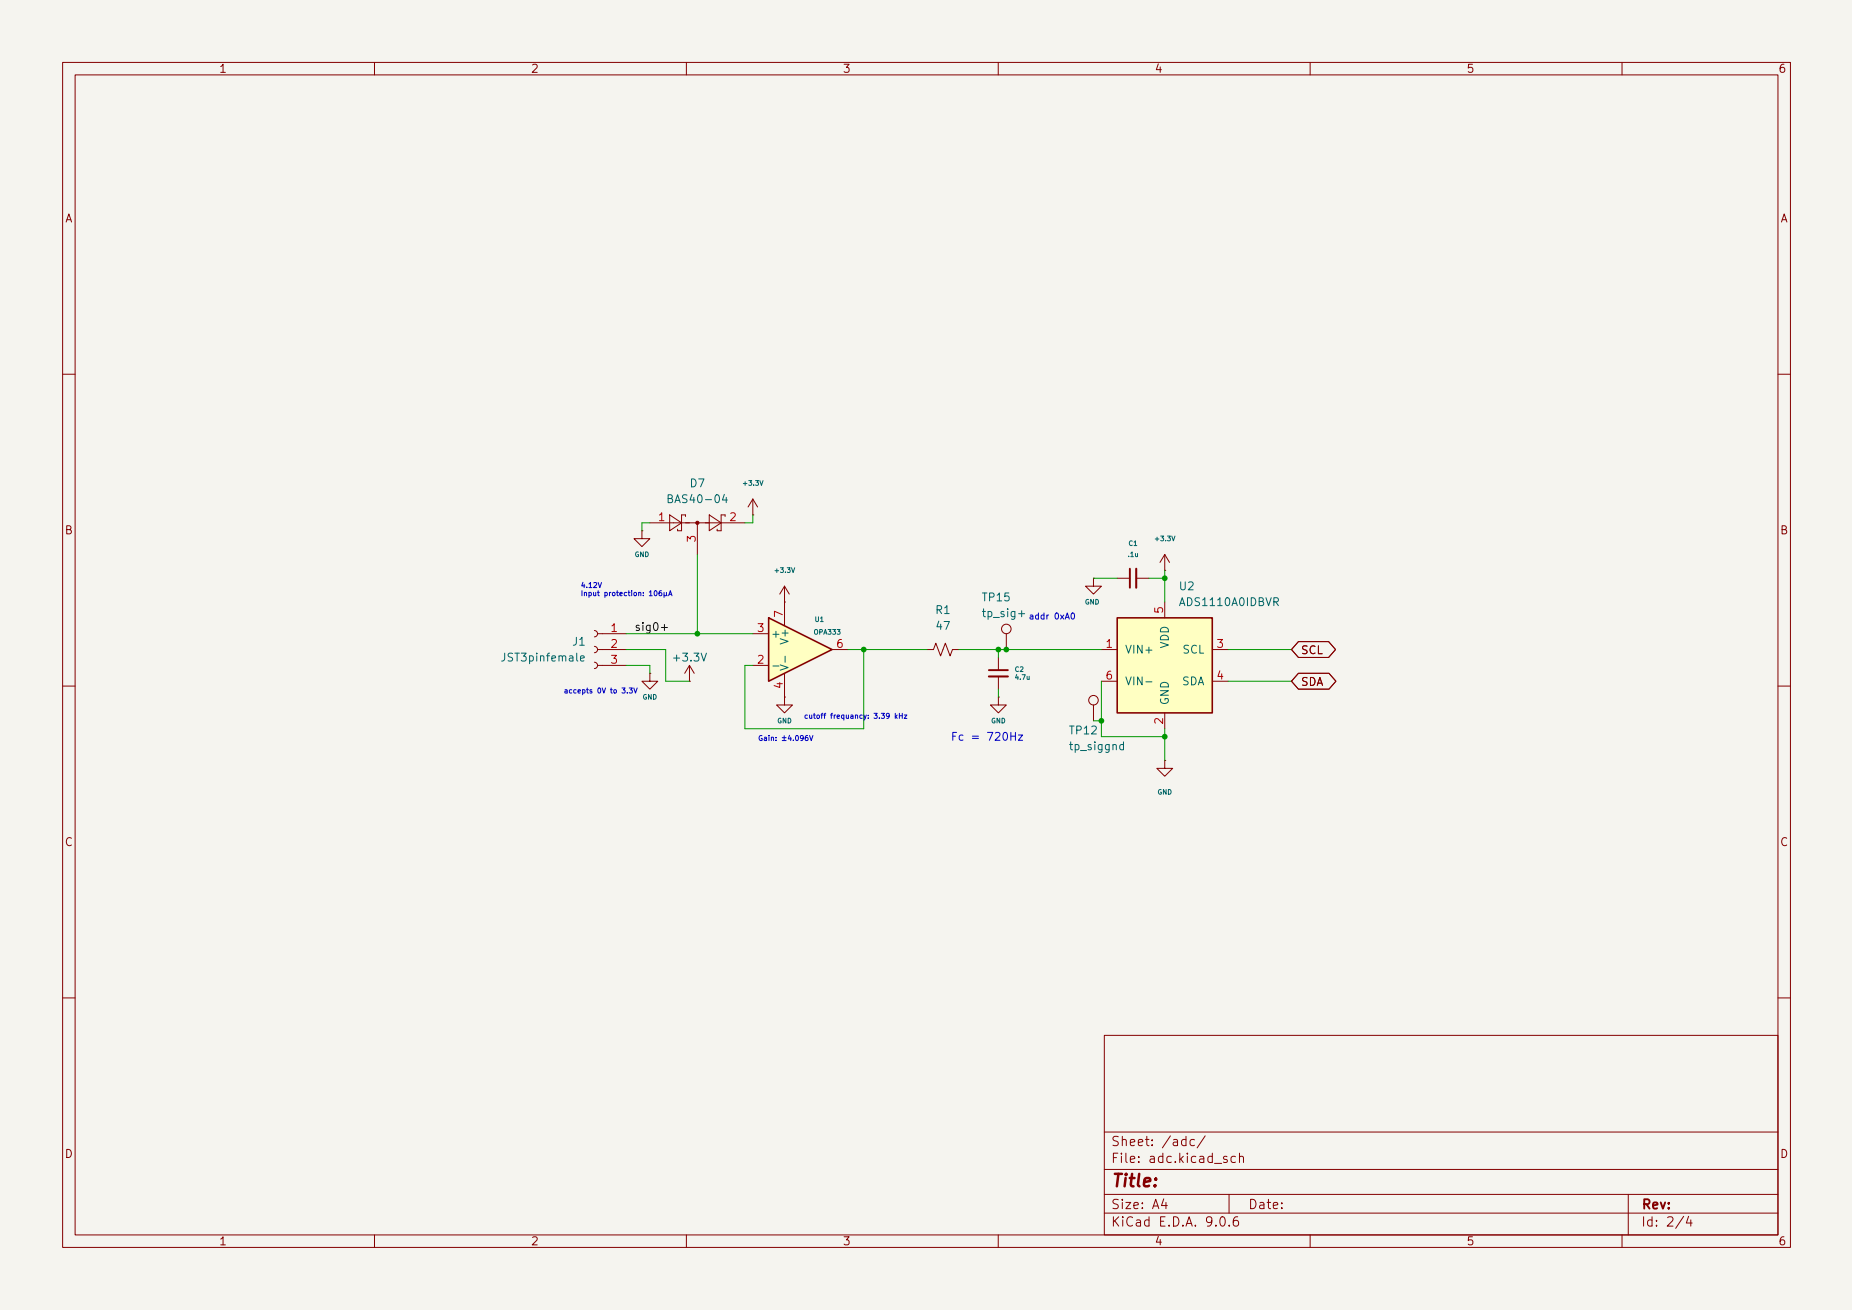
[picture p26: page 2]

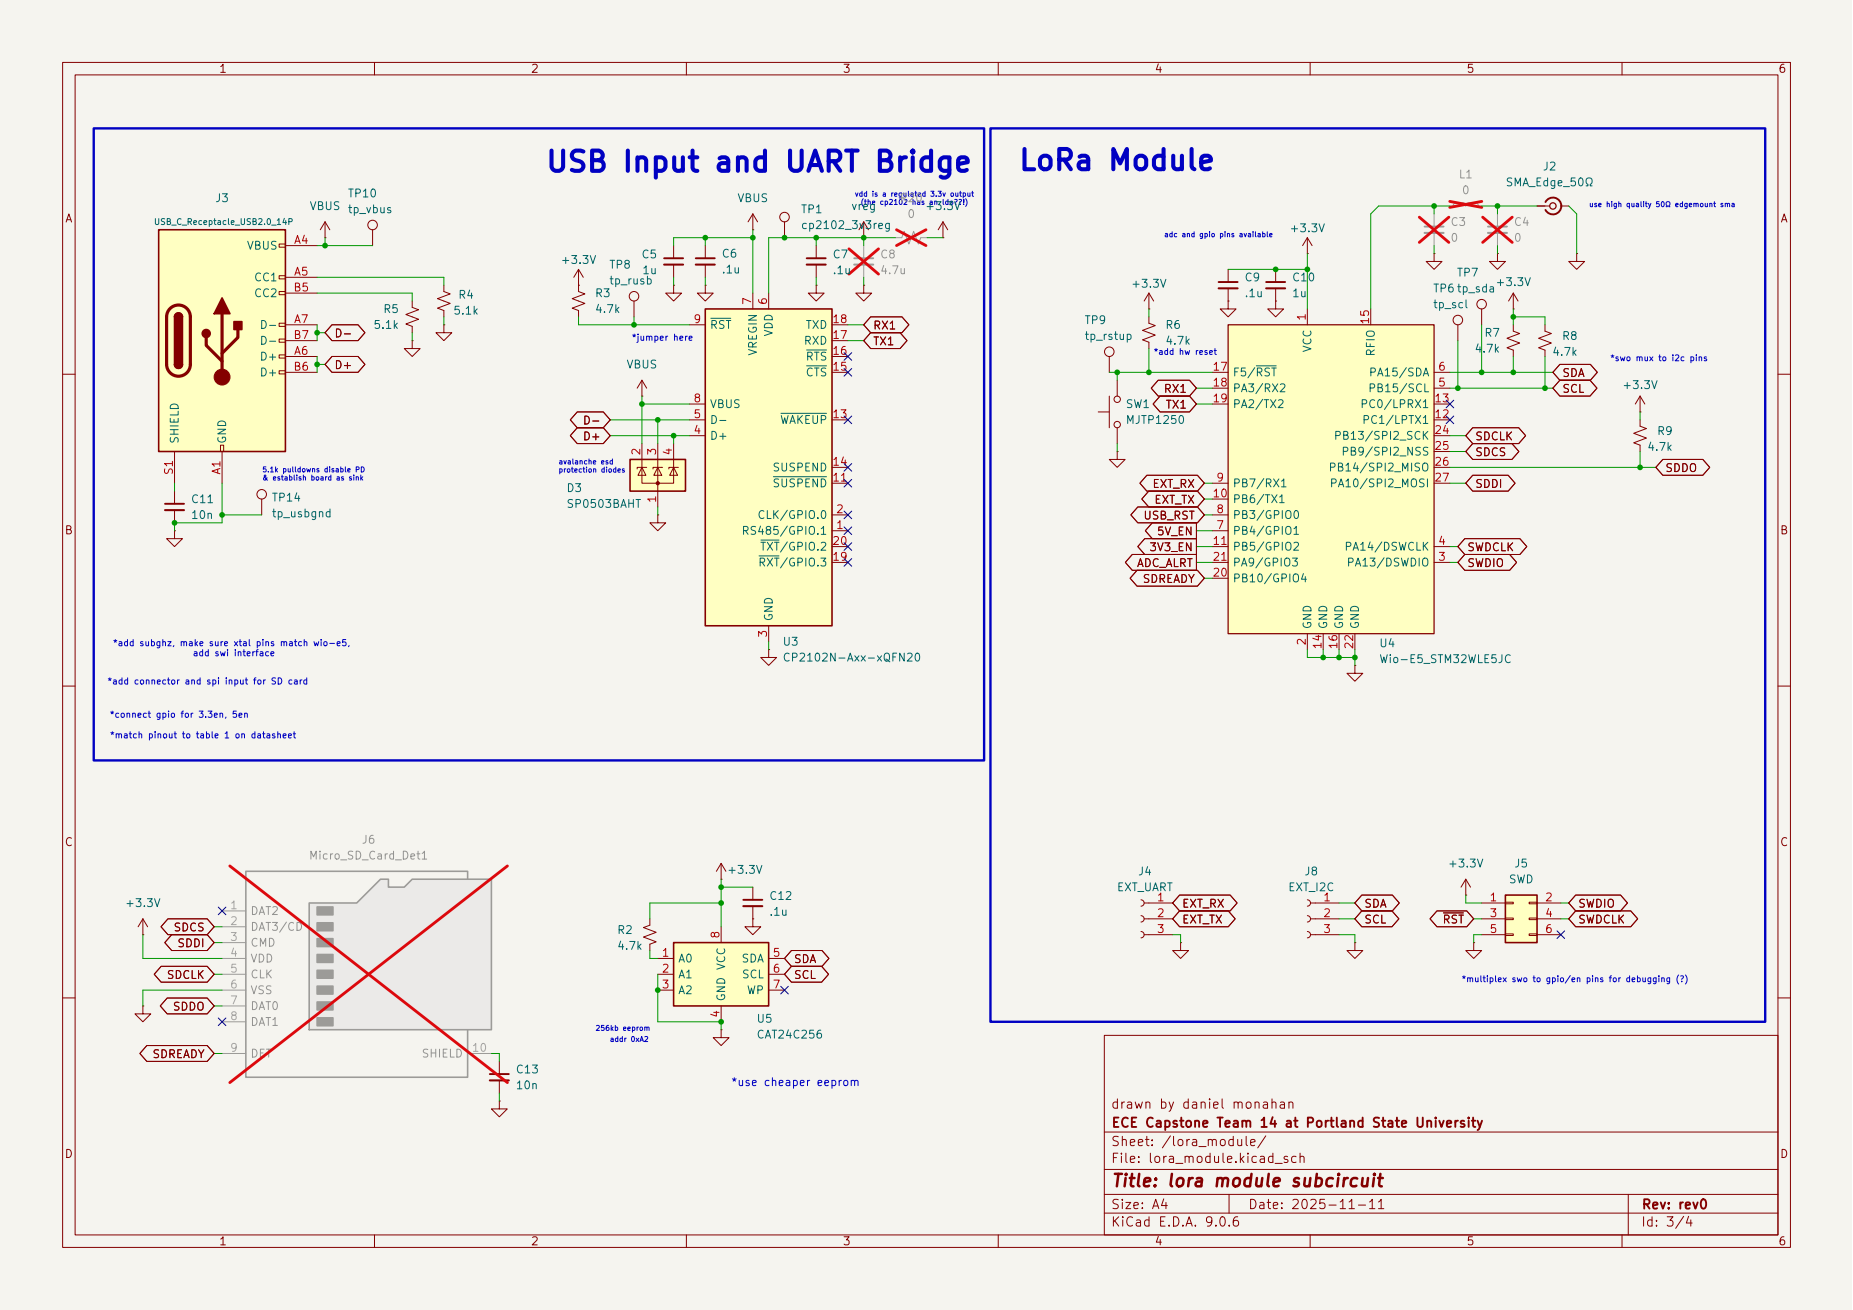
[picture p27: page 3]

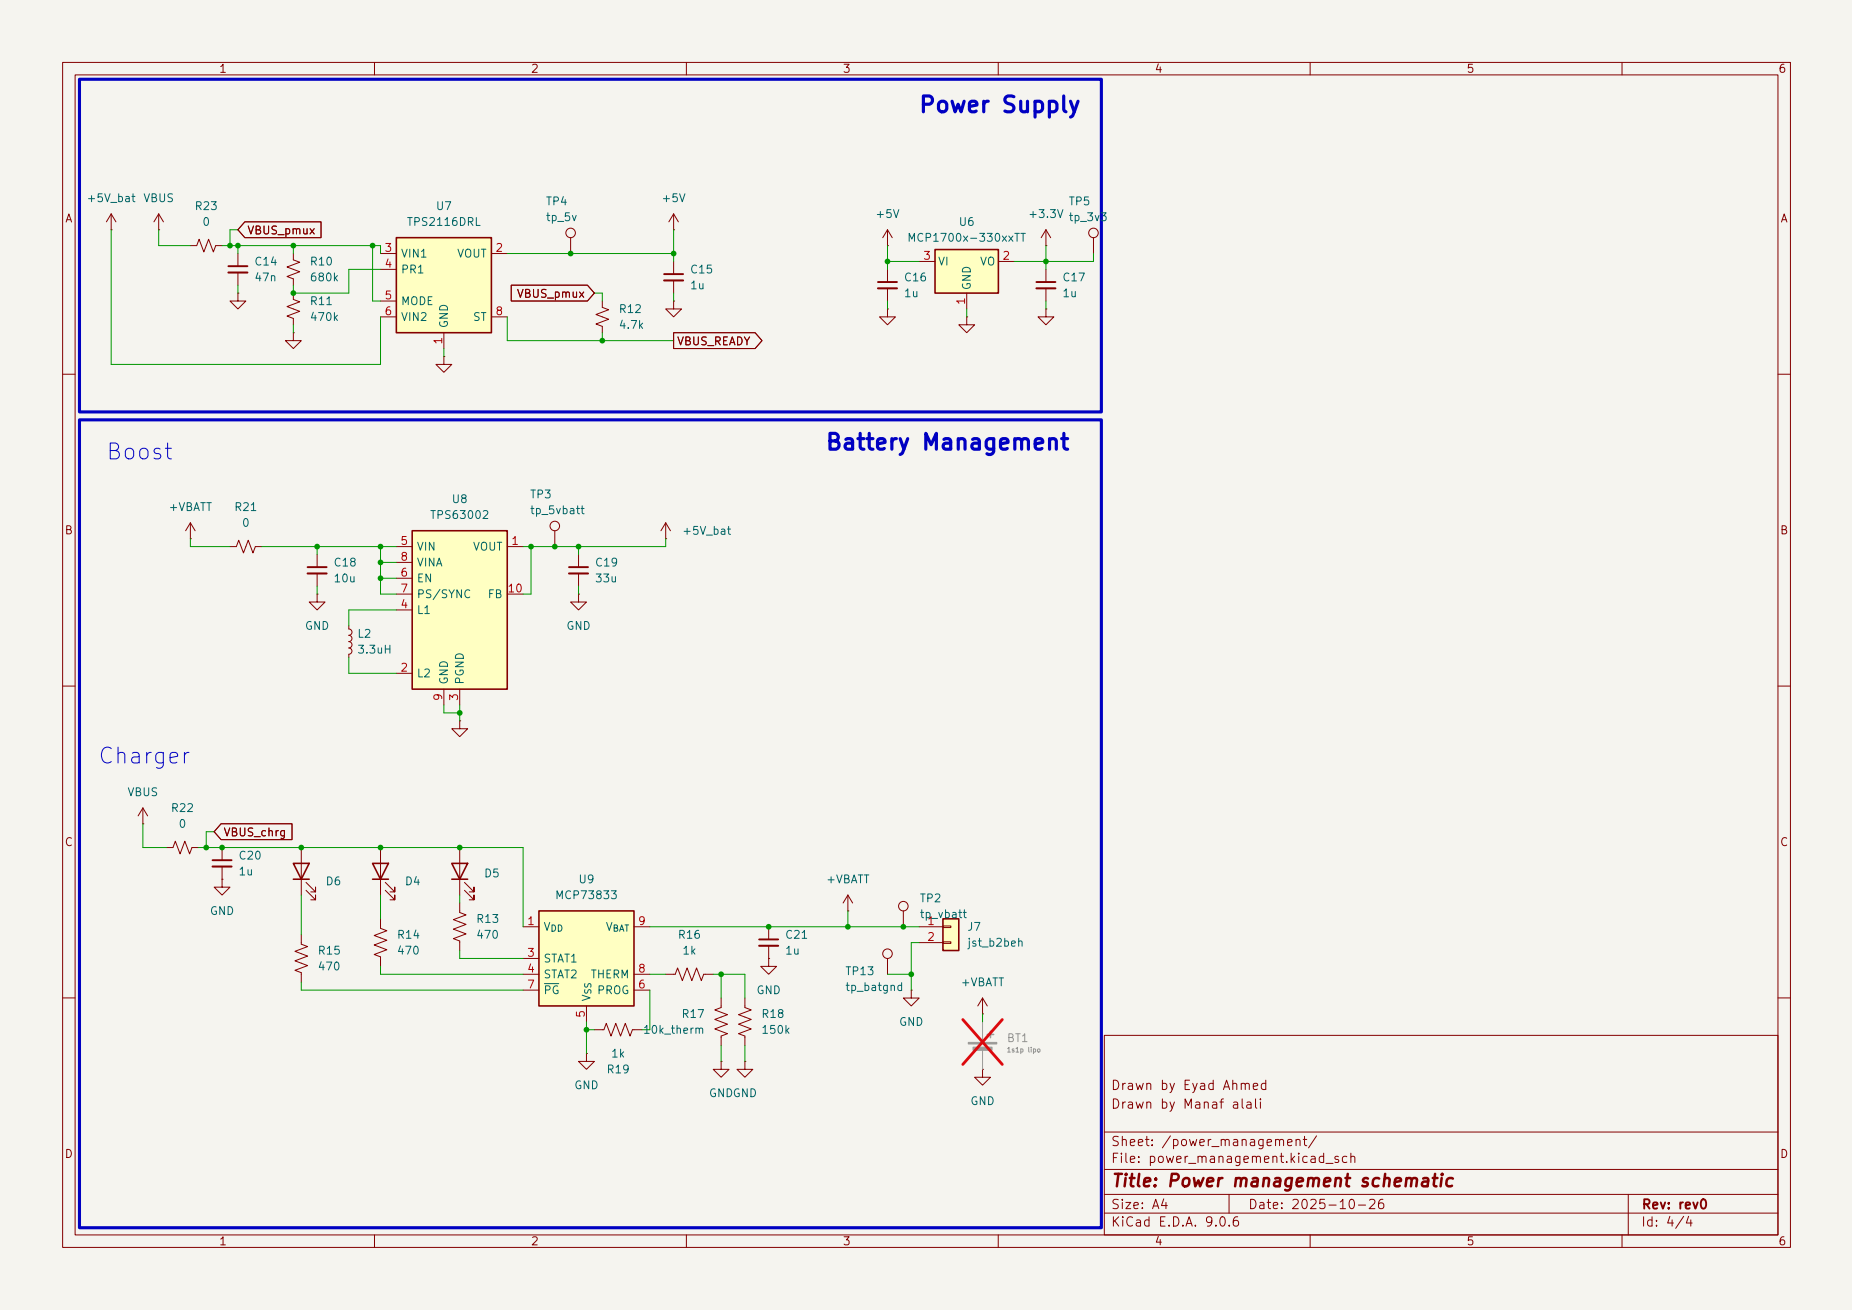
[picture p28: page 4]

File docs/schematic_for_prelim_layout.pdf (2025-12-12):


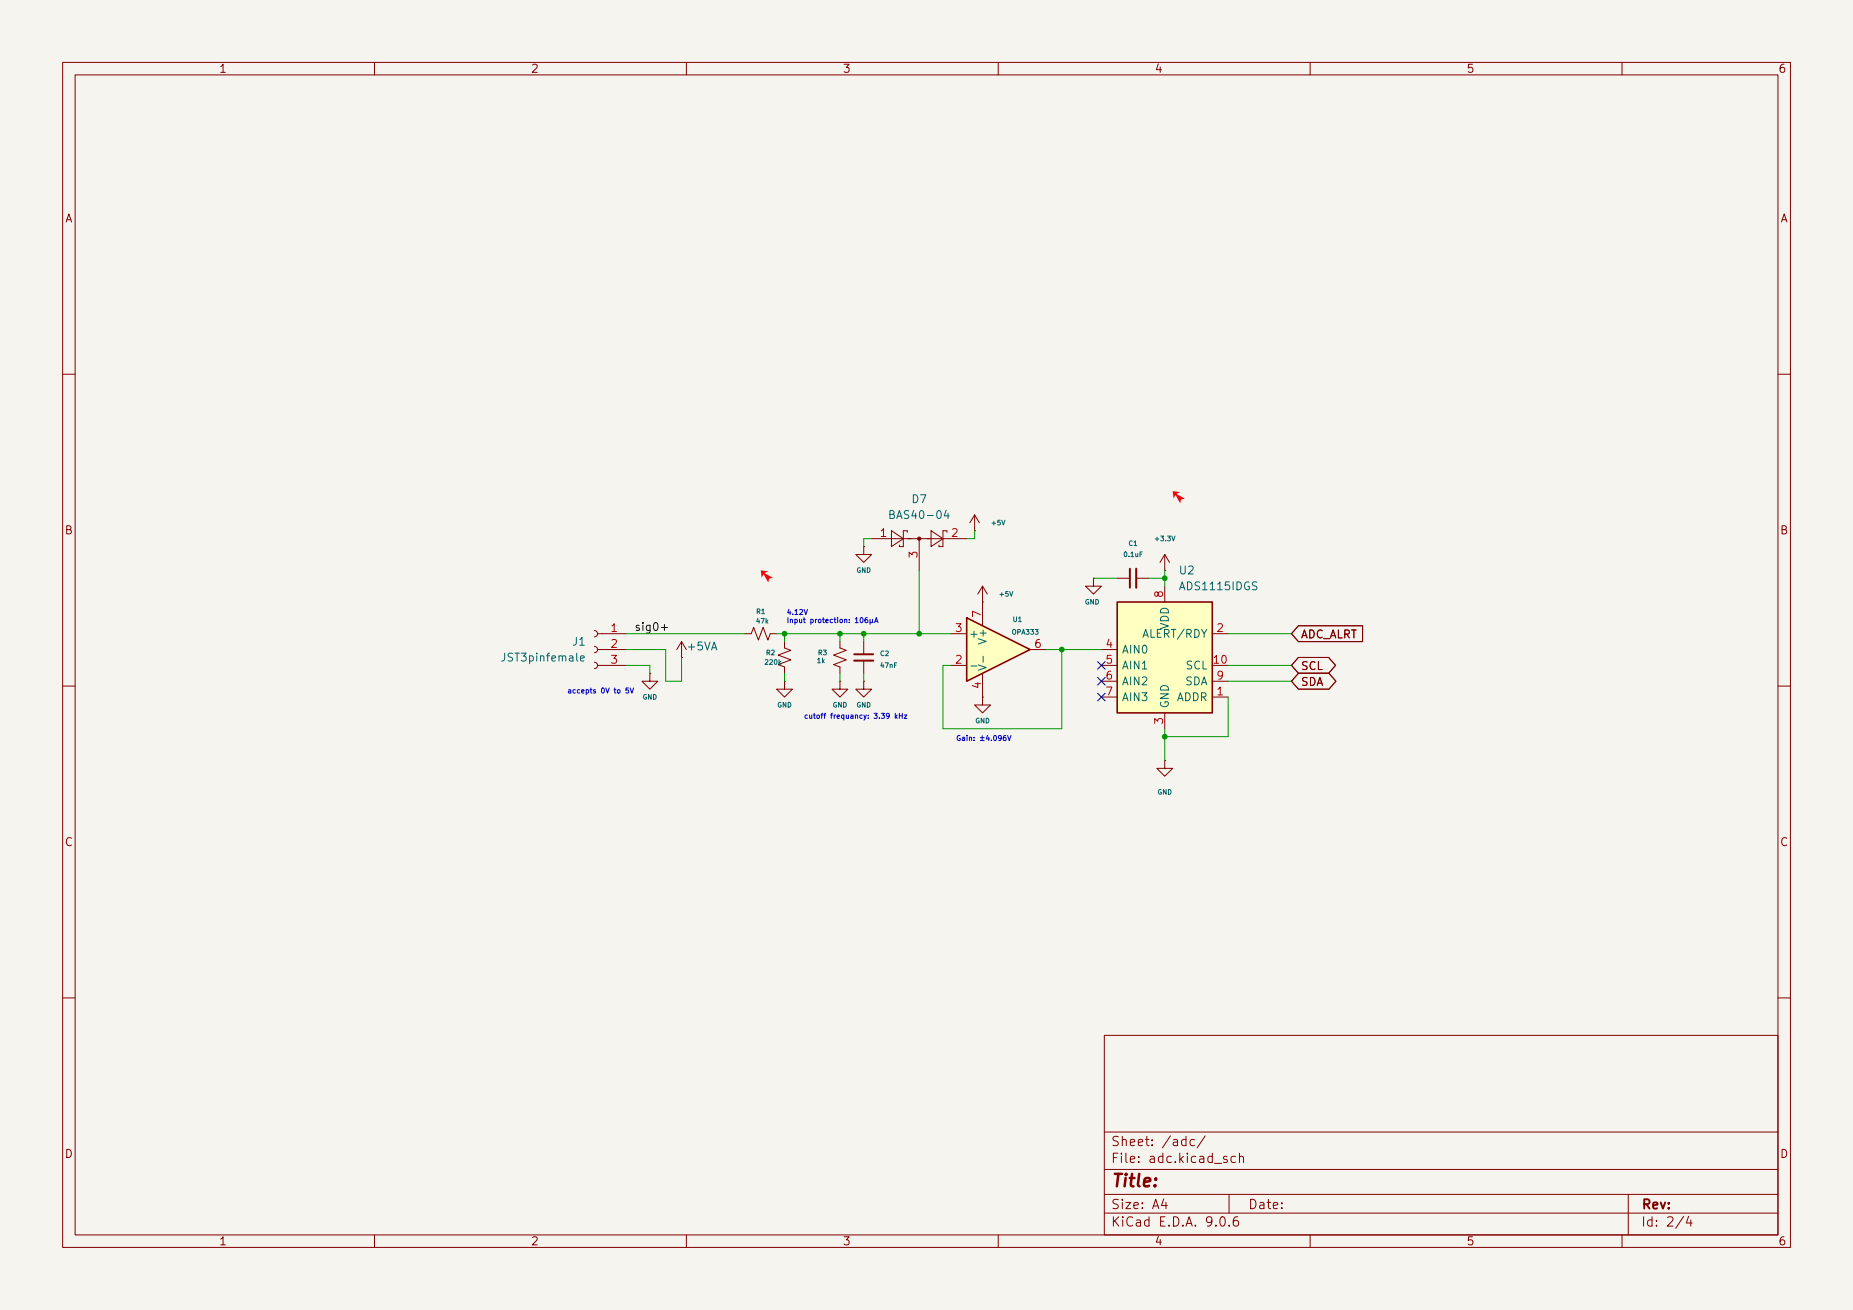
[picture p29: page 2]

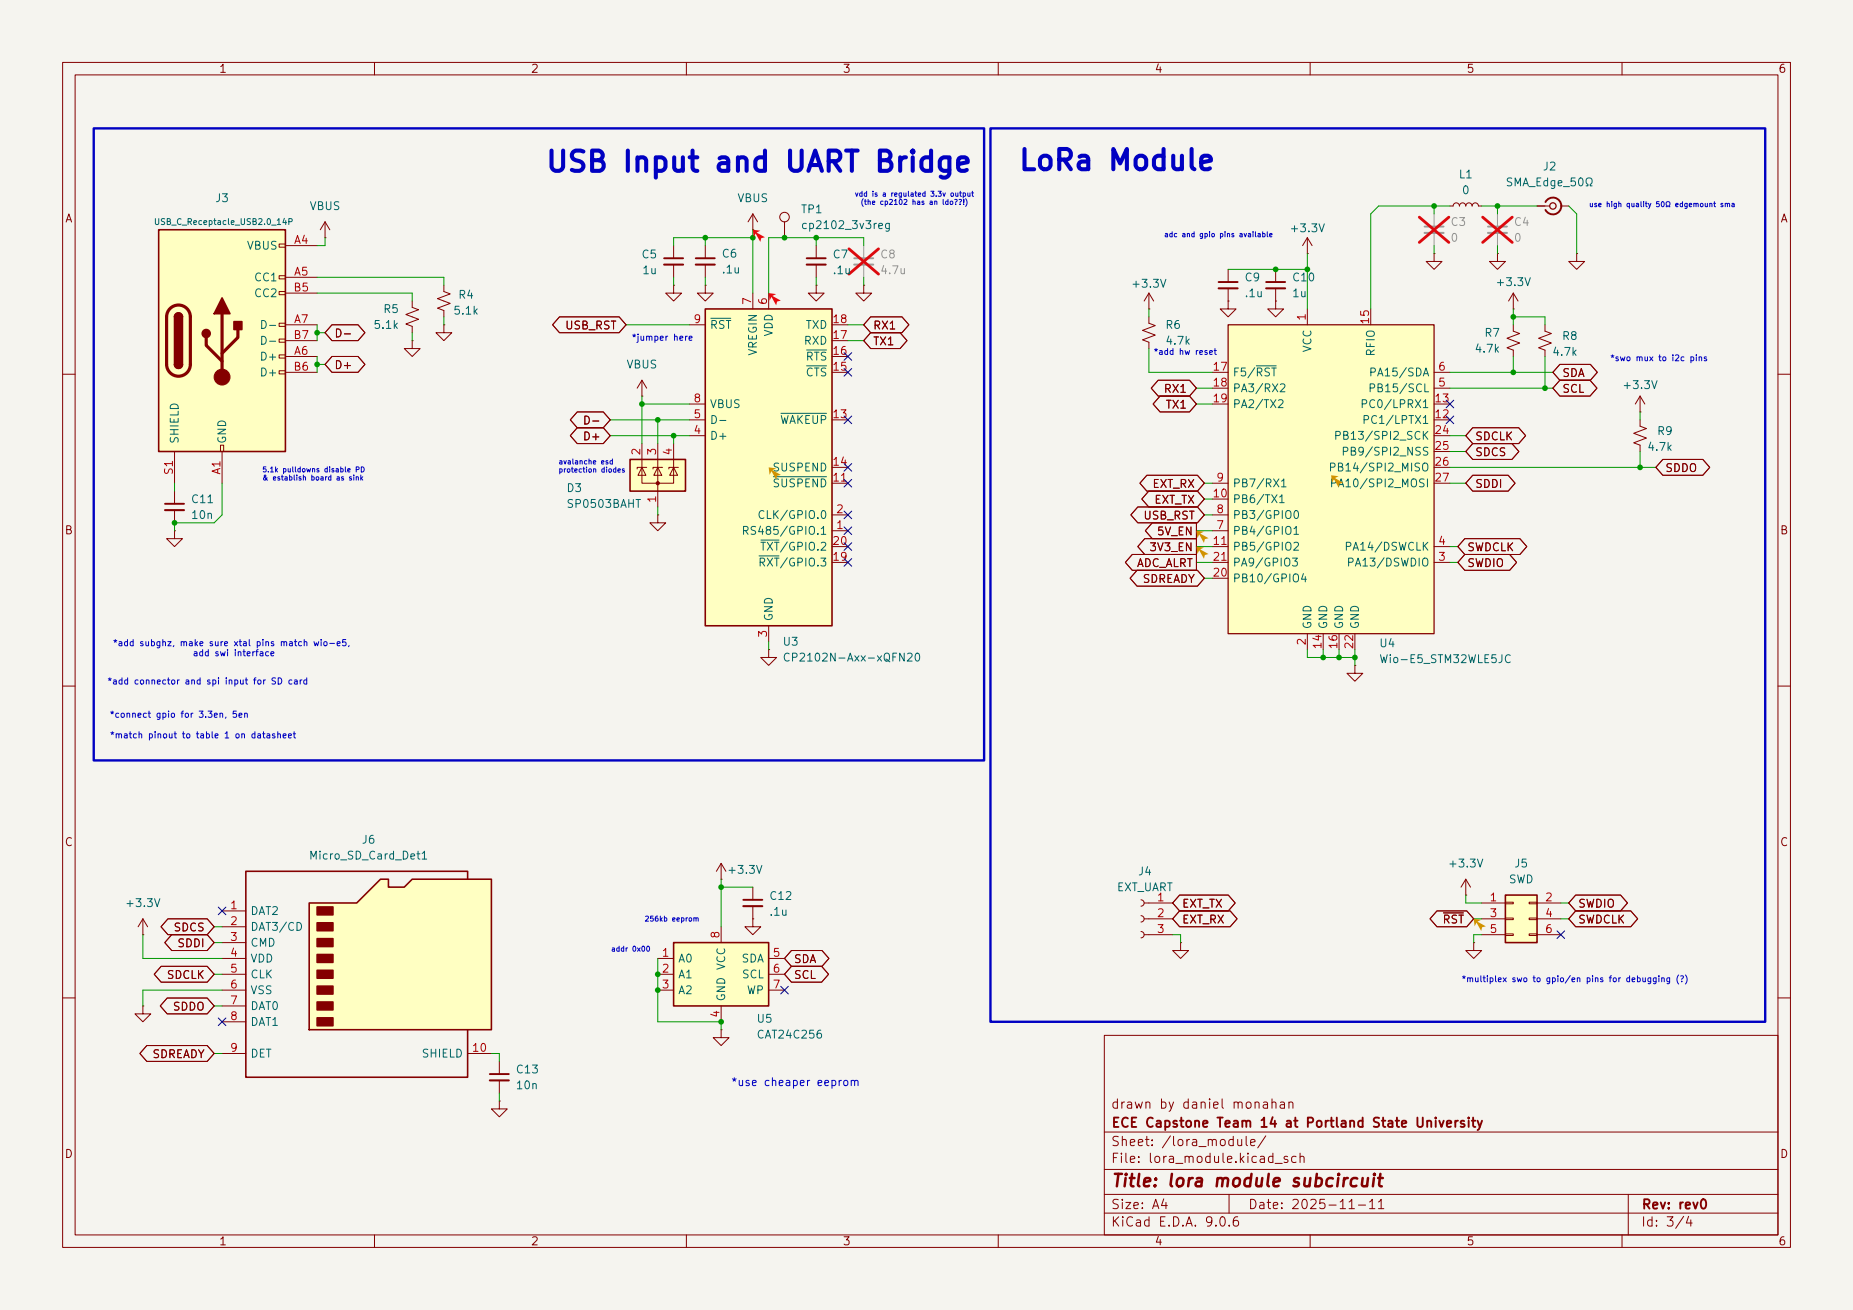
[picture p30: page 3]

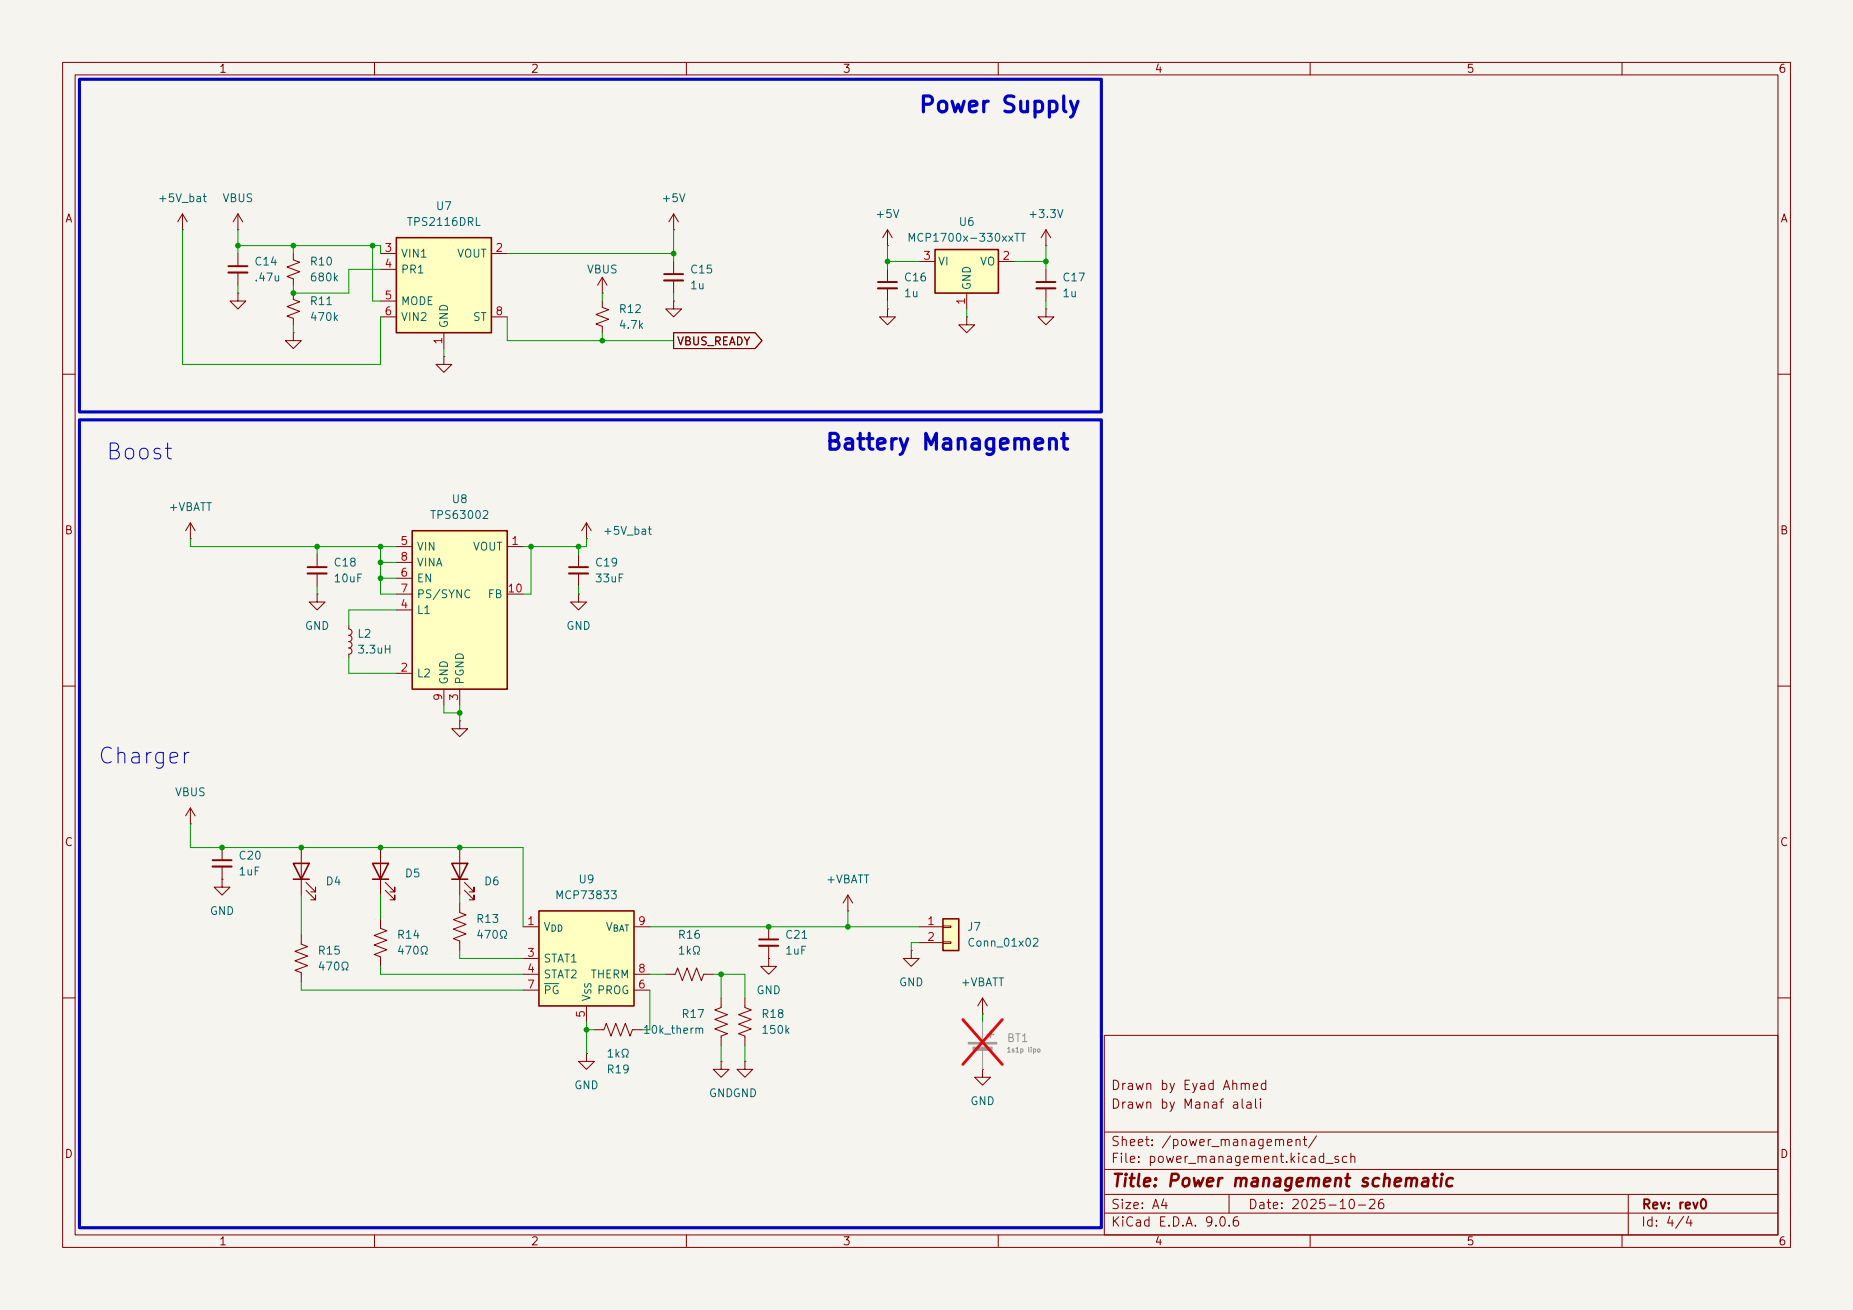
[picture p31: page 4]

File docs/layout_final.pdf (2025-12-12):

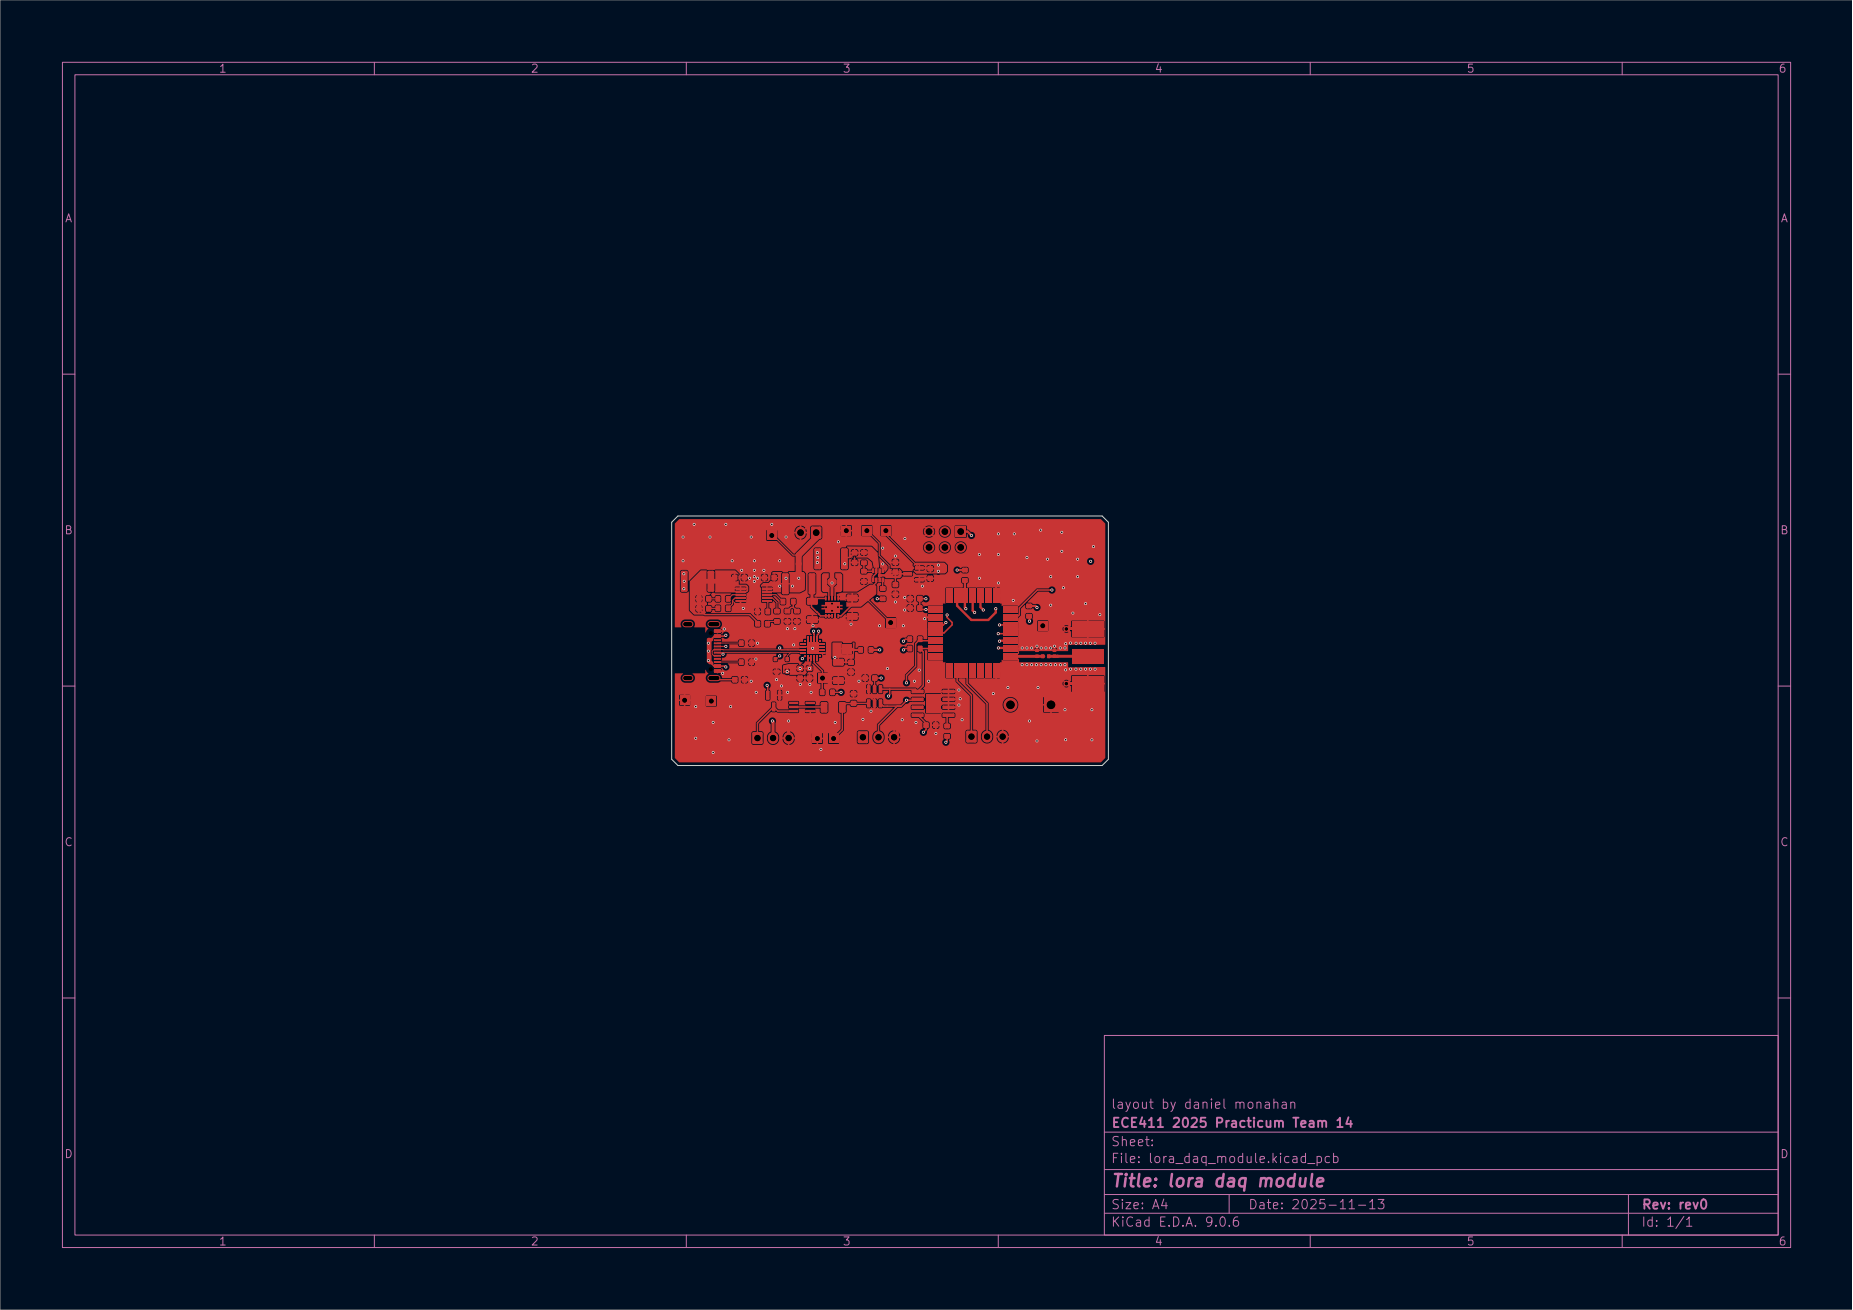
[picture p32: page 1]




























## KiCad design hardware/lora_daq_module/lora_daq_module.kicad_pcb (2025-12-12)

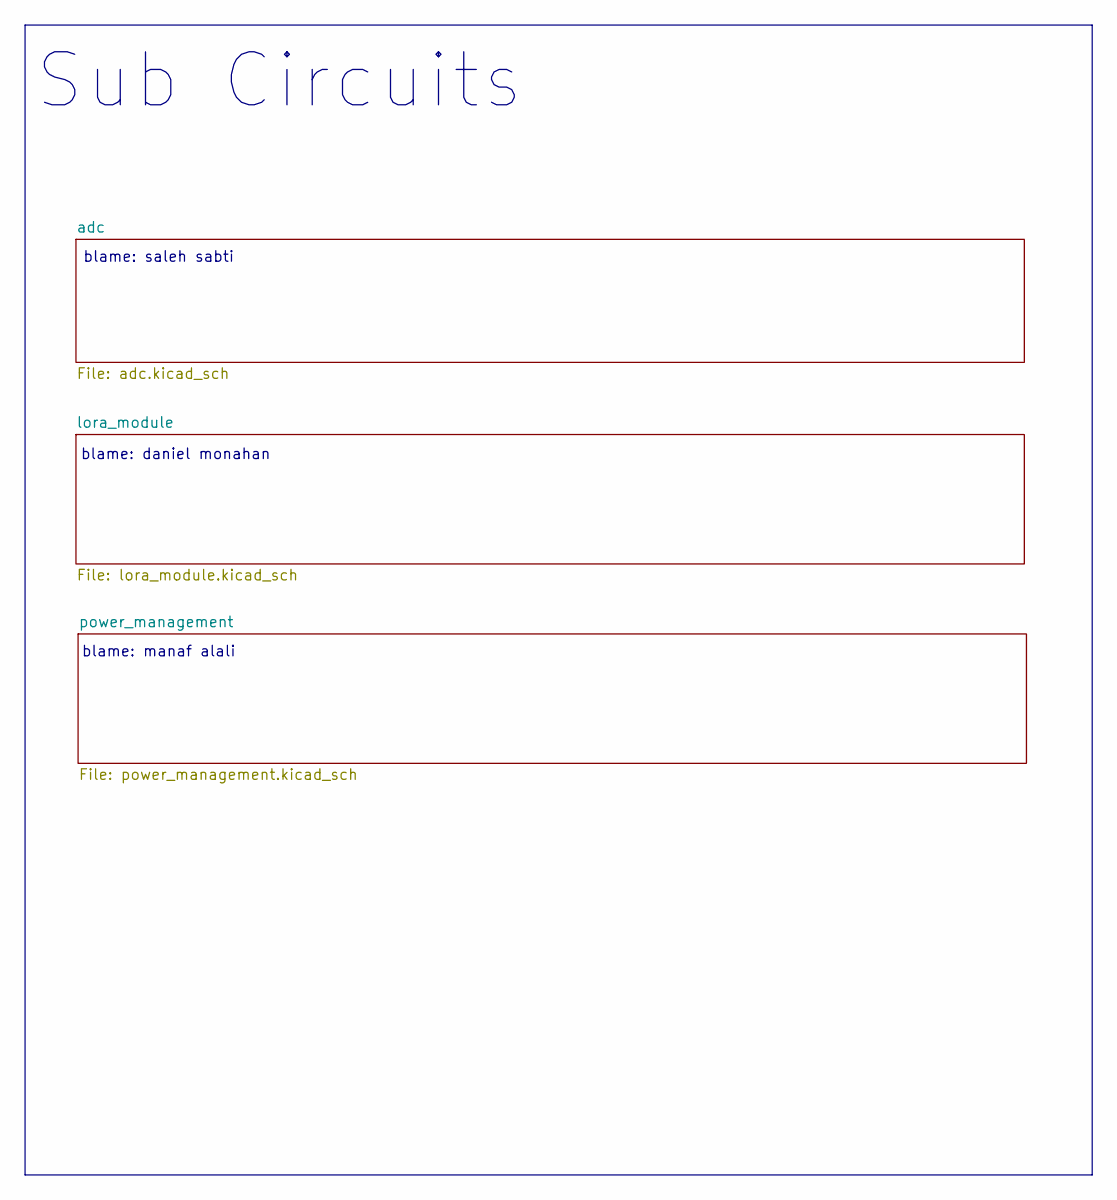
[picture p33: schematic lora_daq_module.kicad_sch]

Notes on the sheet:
blame: manaf alali
blame: saleh sabti
blame: daniel monahan
Sub Circuits

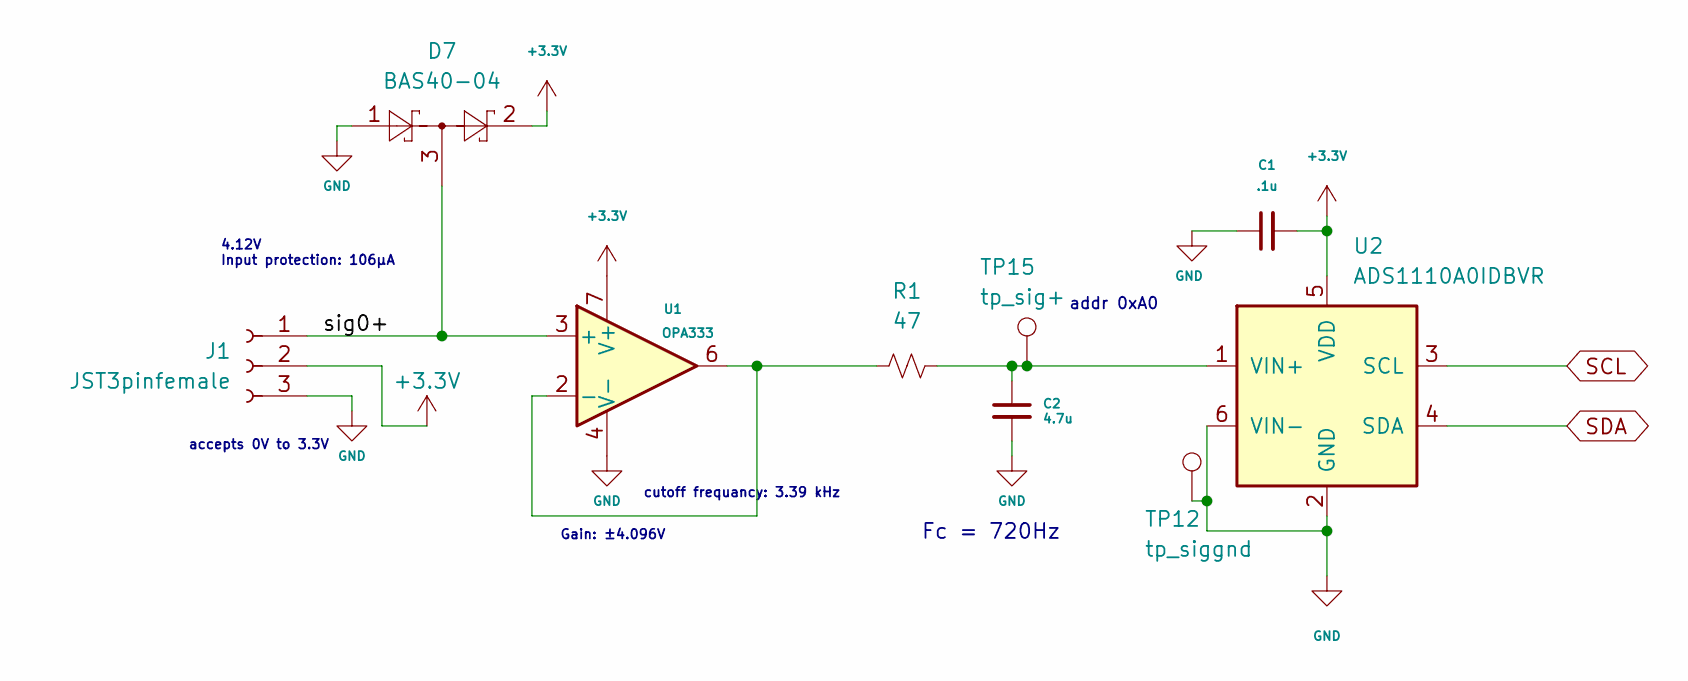
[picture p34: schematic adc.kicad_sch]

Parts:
C1: .1u; C_0603_1608Metric; Mfr PN CC0603KRX7R7BB104
C2: 4.7u; C_0603_1608Metric; Mfr PN CC0603KRX7R8BB473
D7: BAS40-04; SOT-23; Mfr PN BAS40-04
J1: JST3pinfemale; JST_EH_B3B-EH-A_1x03_P2.50mm_Vertical; Mfr PN B3B-EH-A
R1: 47; R_1206_3216Metric; Mfr PN RC1206FR-0747RL
TP12: tp_siggnd; TestPoint_THTPad_1.5x1.5mm_Drill0.7mm
TP15: tp_sig+; TestPoint_THTPad_1.5x1.5mm_Drill0.7mm
U1: OPA333; SOT-353_SC-70-5_Handsoldering; Mfr PN OPA333AIDCKR
U2: ADS1110A0IDBVR; SOT-23-6; Mfr PN ADS1110A0IDBVR

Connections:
+3.3V: C1.2, D7.2, J1.2, U1.7 (V+), U2.5 (VDD); also elsewhere on the board
/adc/sig0+: D7.3, J1.1, U1.3 (+)
GND: C1.1, C2.2, D7.1, J1.3, TP12.1, U1.4 (V-), U2.2 (GND), U2.6 (VIN-); also elsewhere on the board
unnamed: R1.1, U1.2 (-), U1.6
unnamed: C2.1, R1.2, TP15.1, U2.1 (VIN+)
SCL: U2.3 (SCL); also elsewhere on the board
SDA: U2.4 (SDA); also elsewhere on the board

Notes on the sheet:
addr 0xA0
cutoff frequancy: 3.39 kHz
accepts 0V to 3.3V
4.12V Input protection: 106µA
Gain: ±4.096V
Fc = 720Hz

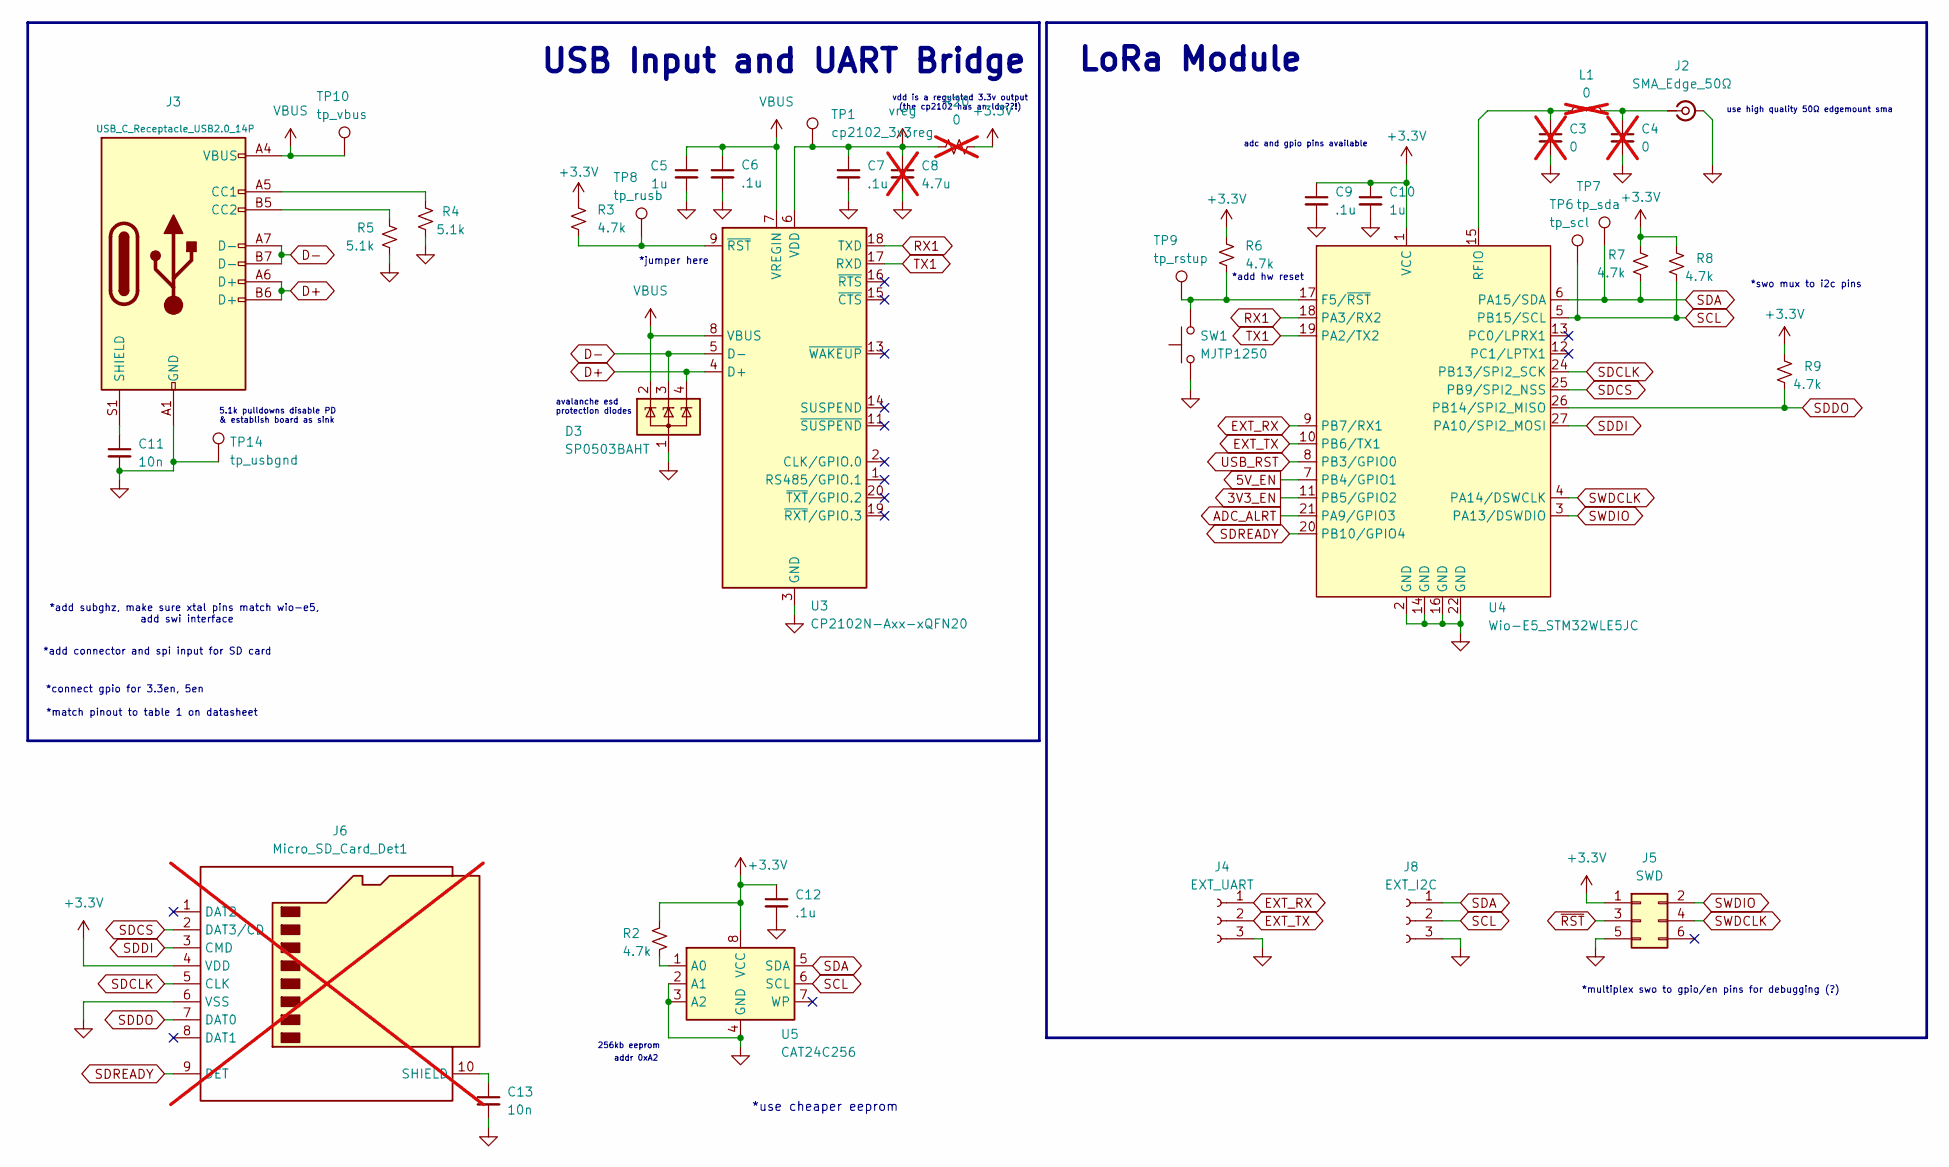
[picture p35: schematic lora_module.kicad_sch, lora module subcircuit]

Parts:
C3, C4: 0; C_0402_1005Metric; not fitted
C5, C10: 1u; C_0603_1608Metric; Mfr PN GCM188R71C105KA64D
C6, C7, C9, C12: .1u; C_0603_1608Metric; Mfr PN CC0603KRX7R7BB104
C8: 4.7u; C_1206_3216Metric; Mfr PN GRM31CR71H475KA12L; not fitted
C11, C13: 10n; C_0603_1608Metric; Mfr PN GCM188R72A103KA37D
D3: SP0503BAHT; SOT-143; Mfr PN SP0503BAHTG
J2: SMA_Edge_50Ω; SMA_Molex_73251-1153_EdgeMount_Horizontal; MPN CONSMA001-C-G
J3: USB_C_Receptacle_USB2.0_14P; USB_C_Receptacle_GCT_USB4105-xx-A_16P_TopMnt_Horizontal; Mfr PN USB4105-GF-A-120
J4: EXT_UART; JST_EH_B3B-EH-A_1x03_P2.50mm_Vertical; Mfr PN B3B-EH-A
J5: SWD; PinHeader_2x03_P2.54mm_Vertical; Mfr PN 61300621121
J6: Micro_SD_Card_Det1; microSD_HC_Molex_104031-0811; Mfr PN 1040310811; not fitted
J8: EXT_I2C; JST_EH_B3B-EH-A_1x03_P2.50mm_Vertical; Mfr PN B3B-EH-A
L1: 0; L_0402_1005Metric; Mfr PN RC0402JR-070RL; not fitted
R2, R3, R6, R7, R8, R9: 4.7k; R_0603_1608Metric; Mfr PN RC0603JR-074K7L
R4, R5: 5.1k; R_0603_1608Metric; Mfr PN RC0603FR-075K1L
R20: 0; R_0603_1608Metric; Mfr PN RMCF0603ZT0R00; not fitted
SW1: MJTP1250; SW_PUSH_1P1T_6x3.5mm_H5.0_APEM_MJTP1250; Mfr PN MJTP1250
TP1: cp2102_3v3reg; TestPoint_Pad_1.5x1.5mm
TP6: tp_scl; TestPoint_THTPad_1.5x1.5mm_Drill0.7mm
TP7: tp_sda; TestPoint_THTPad_1.5x1.5mm_Drill0.7mm
TP8: tp_rusb; TestPoint_THTPad_1.5x1.5mm_Drill0.7mm
TP9: tp_rstup; TestPoint_THTPad_1.5x1.5mm_Drill0.7mm
TP10: tp_vbus; TestPoint_THTPad_1.5x1.5mm_Drill0.7mm
TP14: tp_usbgnd; TestPoint_THTPad_1.5x1.5mm_Drill0.7mm
U3: CP2102N-Axx-xQFN20; SiliconLabs_QFN-20-1EP_3x3mm_P0.5mm_EP1.8x1.8mm; Mfr PN CP2102N-A02-GQFN20R
U4: Wio-E5_STM32WLE5JC; LoRa-E5; Mfr PN 317990829
U5: CAT24C256; SOIC-8-1EP_3.9x4.9mm_P1.27mm_EP2.29x3mm; Mfr PN CAT24C256WI-GT3

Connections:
3V3_EN: U4.11 (PB5/GPIO2)
5V_EN: U4.7 (PB4/GPIO1)
+3.3V: C9.1, C10.1, C12.1, J5.1, J6.4 (VDD), R2.2, R3.1, R6.1, R7.2, R8.2, R9.2, R20.2, U4.1 (VCC), U5.8 (VCC); also elsewhere on the board
ADC_ALRT: U4.21 (PA9/GPIO3)
D+: D3.4 (K), J3.A6 (D+), J3.B6 (D+), U3.4 (D+)
D-: D3.3 (K), J3.A7 (D-), J3.B7 (D-), U3.5 (D-)
EXT_RX: J4.1, U4.9 (PB7/RX1)
EXT_TX: J4.2, U4.10 (PB6/TX1)
GND: C3.2, C4.2, C5.2, C6.2, C7.2, C8.2, C9.2, C10.2, C11.2, C12.2, C13.2, D3.1 (A), J2.2 (Ext), J3.A1 (GND), J3.A12 (GND), J3.B1 (GND), J3.B12 (GND), J4.3, J5.5, J6.6 (VSS), J8.3, R4.1, R5.1, SW1.1, TP14.1, U3.3 (GND), U3.12 (GND), U3.21 (GND), U4.2 (GND), U4.14 (GND), U4.16 (GND), U4.22 (GND), U5.2 (A1), U5.3 (A2), U5.4 (GND); also elsewhere on the board
unnamed: C4.1, J2.1 (In), L1.2
unnamed: J3.A5 (CC1), R4.2
unnamed: J3.B5 (CC2), R5.2
unnamed: C11.1, J3.S1 (SHIELD)
unnamed: C13.1, J6.10 (SHIELD)
unnamed: R3.2, TP8.1, U3.9 (~RST)
unnamed: R6.2, SW1.2, TP9.1, U4.17 (F5/~RST)
unnamed: C3.1, L1.1, U4.15 (RFIO)
unnamed: R2.1, U5.1 (A0)
RX1: U3.18 (TXD), U4.18 (PA3/RX2)
SCL: J8.2, R8.1, U4.5 (PB15/SCL), U5.6 (SCL); also elsewhere on the board
SDA: J8.1, R7.1, U4.6 (PA15/SDA), U5.5 (SDA); also elsewhere on the board
SDCLK: J6.5 (CLK), U4.24 (PB13/SPI2_SCK)
SDCS: J6.2 (DAT3/CD), U4.25 (PB9/SPI2_NSS)
SDDI: J6.3 (CMD), U4.27 (PA10/SPI2_MOSI)
SDDO: J6.7 (DAT0), R9.1, U4.26 (PB14/SPI2_MISO)
SDREADY: J6.9 (DET), U4.20 (PB10/GPIO4)
SWDCLK: J5.4, U4.4 (PA14/DSWCLK)
SWDIO: J5.2, U4.3 (PA13/DSWDIO)
TX1: U3.17 (RXD), U4.19 (PA2/TX2)
USB_RST: U4.8 (PB3/GPIO0)
VBUS: C5.1, C6.1, D3.2 (K), J3.A4 (VBUS), J3.A9 (VBUS), J3.B4 (VBUS), J3.B9 (VBUS), TP10.1, U3.7 (VREGIN), U3.8 (VBUS); also elsewhere on the board
vreg: C7.1, C8.1, R20.1, TP1.1, U3.6 (VDD)
~RST: J5.3

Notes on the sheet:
vdd is a regulated 3.3v output (the cp2102 has an ldo??!)
*use cheaper eeprom
avalanche esd protection diodes
5.1k pulldowns disable PD & establish board as sink
*jumper here
*match pinout to table 1 on datasheet
*add hw reset
use high quality 50Ω edgemount sma
USB Input and UART Bridge
*swo mux to i2c pins
256kb eeprom
*add subghz, make sure xtal pins match wio-e5, add swi interface
addr 0xA2
*add connector and spi input for SD card
LoRa Module
*connect gpio for 3.3en, 5en
adc and gpio pins available
*multiplex swo to gpio/en pins for debugging (?)

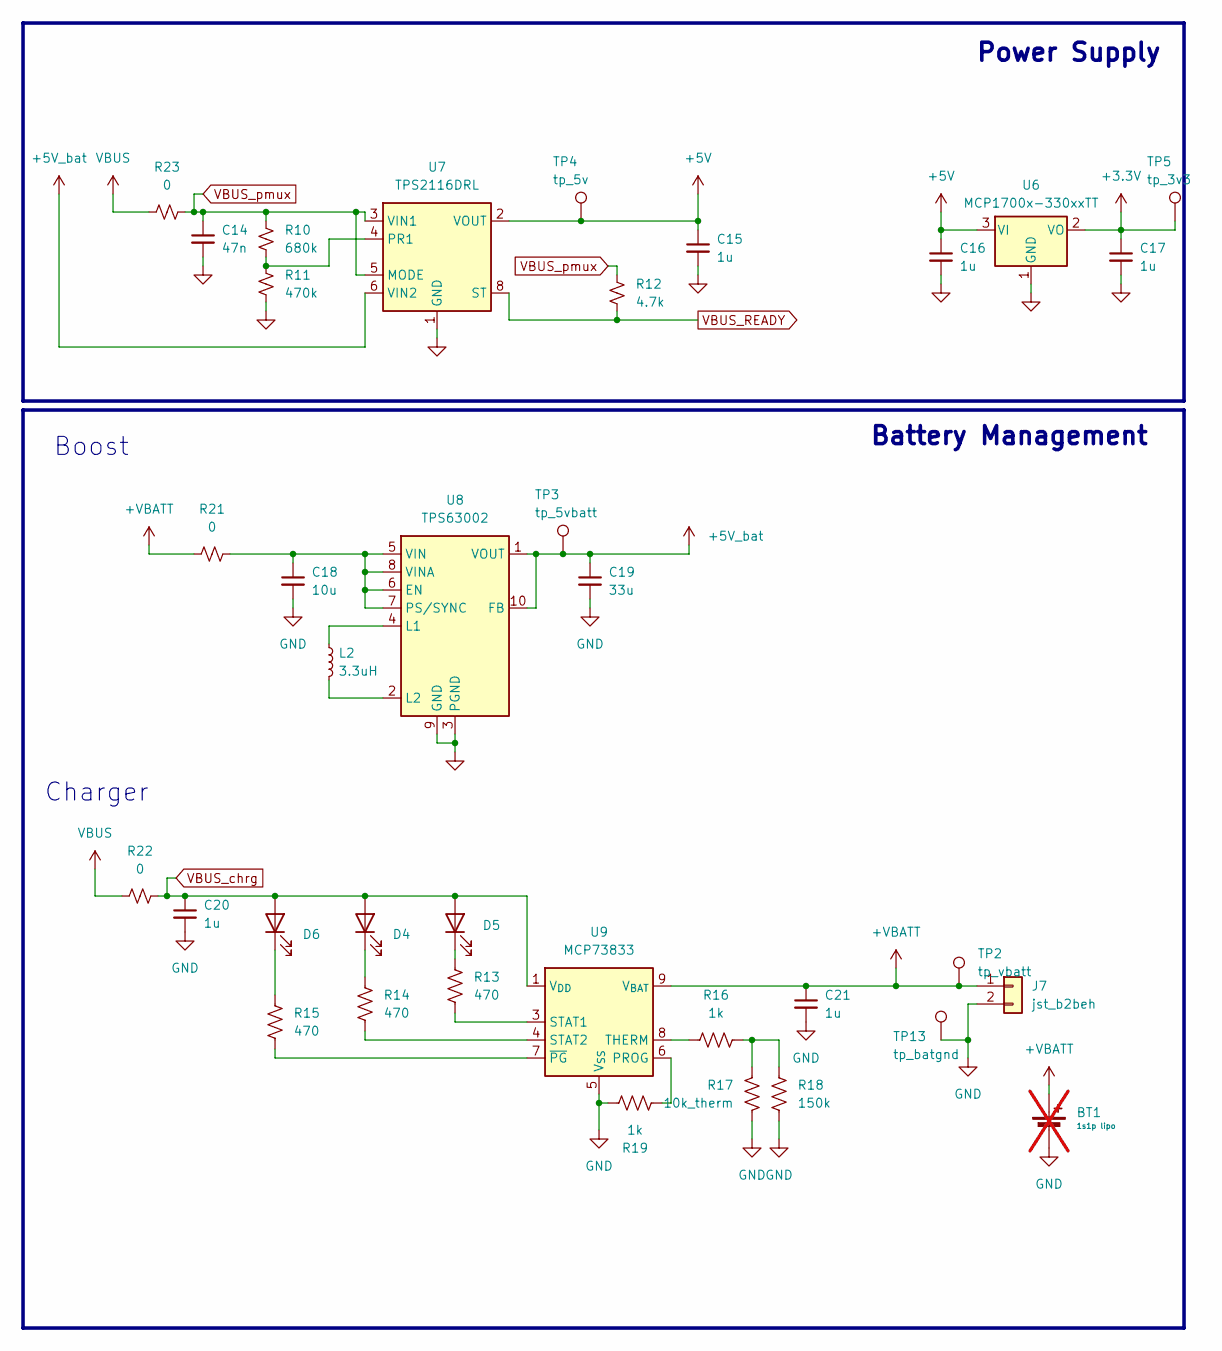
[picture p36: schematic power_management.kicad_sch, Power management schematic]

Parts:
BT1: 1s1p lipo; Mfr PN 258; not fitted
C14: 47n; C_0603_1608Metric; Mfr PN CC0603KRX7R8BB473
C15, C16, C17, C20, C21: 1u; C_0603_1608Metric; Mfr PN GCM188R71C105KA64D
C18: 10u; C_1206_3216Metric; Mfr PN CL31A106KBHNNNE
C19: 33u; C_1206_3216Metric; Mfr PN C3216JB1C336M160AB
D4: Green; LED_0603_1608Metric; Mfr PN LTST-C191KGKT
D5: Yellow; LED_0603_1608Metric; Mfr PN LTST-C191KSKT
D6: Red; LED_0603_1608Metric; Mfr PN LTST-C190KRKT
J7: jst_b2beh; JST_EH_B2B-EH-A_1x02_P2.50mm_Vertical; Mfr PN B2B-EH-A
L2: 3.3uH; L_Coilcraft_LPS3010; Mfr PN LPS3015-332MRC
R10: 680k; R_0603_1608Metric; Mfr PN RC0603FR-07680KL
R11: 470k; R_0603_1608Metric; Mfr PN RMCF0603FT470K
R12: 4.7k; R_0603_1608Metric; Mfr PN RC0603JR-074K7L
R13, R14, R15: 470; R_0603_1608Metric; Mfr PN RC0603JR-07470RL
R16, R19: 1k; R_0603_1608Metric; Mfr PN RMCF0603FT1K00
R17: 10k_therm; R_0603_1608Metric; Mfr PN NCU18XH103F60RB
R18: 150k; R_0603_1608Metric; Mfr PN RMCF0603FT150K
R21, R22, R23: 0; R_1812_4532Metric; Mfr PN ERJ-12Y0R00U
TP2: tp_vbatt; TestPoint_THTPad_1.5x1.5mm_Drill0.7mm
TP3: tp_5vbatt; TestPoint_THTPad_1.5x1.5mm_Drill0.7mm
TP4: tp_5v; TestPoint_THTPad_1.5x1.5mm_Drill0.7mm
TP5: tp_3v3; TestPoint_THTPad_1.5x1.5mm_Drill0.7mm
TP13: tp_batgnd; TestPoint_THTPad_1.5x1.5mm_Drill0.7mm
U6: MCP1700x-330xxTT; SOT-23; Mfr PN MCP1700T-3302E/TT
U7: TPS2116DRL; SOT-583-8; Mfr PN TPS2116DRLR
U8: TPS63002; Texas_DRC0010J_ThermalVias; Mfr PN TPS63002DRCR
U9: MCP73833; MSOP-10_3x3mm_P0.5mm; Mfr PN MCP73833T-AMI/UN

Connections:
+3.3V: C17.1, TP5.1, U6.2 (VO); also elsewhere on the board
+5V: C15.1, C16.1, TP4.1, U6.3 (VI), U7.2 (VOUT), U7.7 (VOUT)
+5V_bat: C19.1, TP3.1, U7.6 (VIN2), U8.1 (VOUT), U8.10 (FB)
+VBATT: BT1.1 (+), C21.1, J7.1, R21.1, TP2.1, U9.9 (V_{BAT}), U9.10 (V_{BAT})
GND: C14.2, C15.2, C16.2, C17.2, C18.2, C19.2, C20.2, C21.2, J7.2, R11.2, R17.2, R18.1, R19.1, TP13.1, U6.1 (GND), U7.1 (GND), U8.3 (PGND), U8.9 (GND), U8.11 (PGND), U9.5 (V_{SS}); also elsewhere on the board
unnamed: D4.1 (K), R14.1
unnamed: D5.1 (K), R13.1
unnamed: D6.1 (K), R15.1
unnamed: R16.2, R17.1, R18.2
unnamed: R10.2, R11.1, U7.4 (PR1)
unnamed: C18.1, R21.2, U8.5 (VIN), U8.6 (EN), U8.7 (PS/SYNC), U8.8 (VINA)
unnamed: L2.1, U8.4 (L1)
unnamed: L2.2, U8.2 (L2)
unnamed: R19.2, U9.6 (PROG)
unnamed: R13.2, U9.3 (STAT1)
unnamed: R14.2, U9.4 (STAT2)
unnamed: R16.1, U9.8 (THERM)
unnamed: R15.2, U9.7 (~PG)
VBUS: R22.1, R23.1; also elsewhere on the board
VBUS_READY: R12.2, U7.8 (ST)
VBUS_chrg: C20.1, D4.2 (A), D5.2 (A), D6.2 (A), R22.2, U9.1 (V_{DD}), U9.2 (V_{DD})
VBUS_pmux: C14.1, R10.1, R12.1, R23.2, U7.3 (VIN1), U7.5 (MODE)

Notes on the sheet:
Boost
Battery Management
Charger
Power Supply

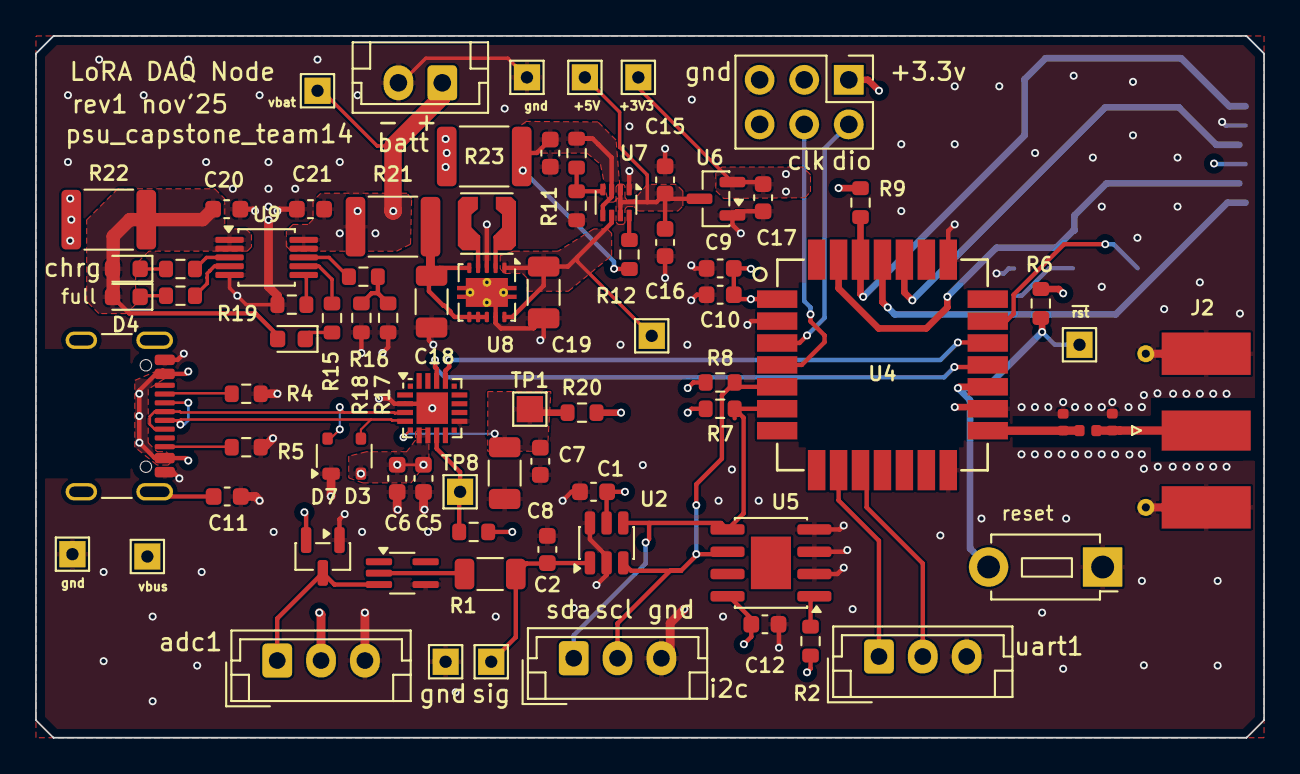
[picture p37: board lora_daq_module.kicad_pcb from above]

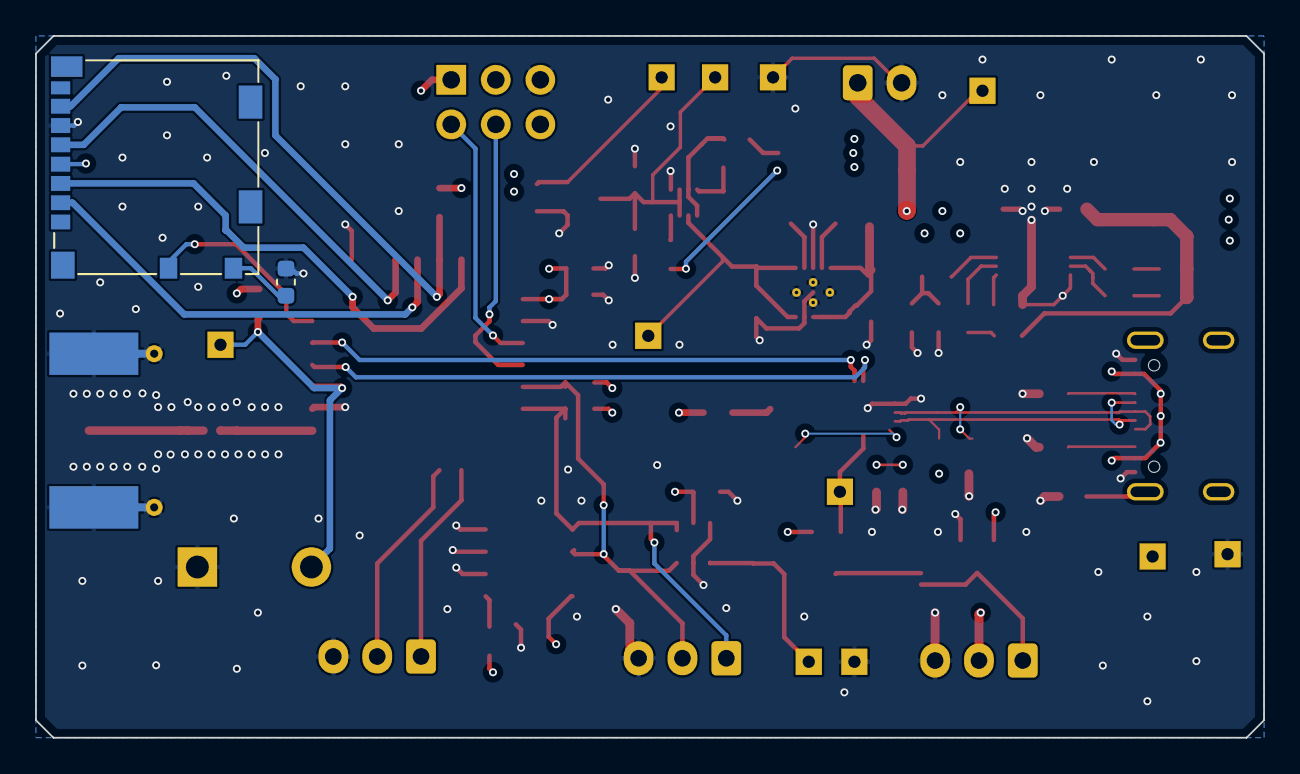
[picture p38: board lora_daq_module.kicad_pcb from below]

Board: 4 copper layers, 70.0 x 40.0 mm, 81 parts (2 on the bottom side), 50 nets.

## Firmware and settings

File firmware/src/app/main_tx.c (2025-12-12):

#include "am2320.h"     // AM2320 sensor
#include "i2c_driver.h" // I2C driver
#include "lora_app.h"
#include "main.h"
#include "stm32wlxx_hal.h"
#include <stdio.h>
// #include "ads1110.h"         // Analog sensor
// #include "sensor_digital.h"  // Digital sensor
// #include "data_buffer.h"
#include "ads1110.h" // ADS1110 ADC
#include "board_config.h"
#include "gpio_driver.h"
#include "scheduler.h"
#include "uart_debug.h" // UART debug functions

void SystemClock_Config(void);
void LED_Init(void);
void LED_Blink(uint8_t times, uint32_t delay_ms);
void LED_On(void);
void LED_Off(void);

// static GPIO_Handle_t led = {
//     .port = LED_GPIO_PORT,
//     .pin = LED_GPIO_PIN,
//     .mode = GPIO_MODE_OUTPUT,
//     .pull = GPIO_PULL_NONE,
//     .speed = GPIO_SPEED_LOW
// };

int main(void) {
  HAL_Init();
  SystemClock_Config();

  // Initialize UART for debugging
  UART_Debug_Init();
  UART_Debug_Println("=== LoRa DAQ Module Starting ===");

  /* TODO: Initialize I2C bus */
  if (I2C_Init() != I2C_OK) {
    UART_Debug_Println("ERROR: I2C initialization failed!");
    while (1)
      ; // Stop here if I2C fails
  }
  UART_Debug_Println("I2C initialized");
  if (AM2320_Init() != I2C_OK) {
    UART_Debug_Println("WARNING: AM2320 not detected on I2C bus");
    UART_Debug_Println("Check connections: SDA=PA15, SCL=PB15");
    // Continue anyway for testing
  } else {
    UART_Debug_Println("AM2320 sensor detected!");
  }

  // ADS1110 configuration
  ADS1110_Config_t adc_config = {
      .gain = ADS1110_GAIN_1,         // gain 1
      .data_rate = ADS1110_DR_60SPS,  // 60 samples/sec
      .mode = ADS1110_MODE_CONTINUOUS // continuous mode
  };
  ADS1110_Init(&adc_config);

  /* TODO: Initialize storage modules */
  // DataBuffer_Init();
  LoRa_App_Init();
  UART_Debug_Println("LoRa module initialized");

  Scheduler_Init();
  UART_Debug_Println("Scheduler initialized");

  Scheduler_SetSampleInterval(2);
  Scheduler_SetTxInterval(10);

  UART_Debug_Println("Sample interval: 2 sec, TX interval: 10 sec");
  UART_Debug_Println("System ready!");
  // Variable for sensor data
  float temperature = 0.0f;
  float humidity = 0.0f;
  float adc_voltage = 0.0f;
  uint8_t lora_buffer[64];
  uint16_t lora_len = 0;
  while (1) {
    if (Scheduler_ShouldSample()) {
      UART_Debug_Println("Sampling AM2320...");
      /*TODO: Read sensors */
      int8_t result = AM2320_Read(&temperature, &humidity);
      if (result == I2C_OK) {
        // Create debug message
        char debug_msg[64];
        snprintf(debug_msg, sizeof(debug_msg),
                 "Temp: %.1f C, Humidity: %.1f %%", temperature, humidity);
        UART_Debug_Println(debug_msg);

        // // Prepare data for LoRa transmission
        // lora_len = snprintf((char *)lora_buffer, sizeof(lora_buffer),
        //                     "T:%.1f,H:%.1f", temperature, humidity);
      } else if (result == I2C_TIMEOUT) {
        UART_Debug_Println("ERROR: AM2320 timeout (sensor not responding)");
      } else {
        UART_Debug_Println("ERROR: AM2320 I2C error");
      }

      /* TODO: Read other sensors */

      int8_t result_adc = ADS1110_ReadVoltage(&adc_voltage);
      if (result_adc == I2C_OK) {
        char msg[64];
        snprintf(msg, sizeof(msg), "ADS1110: Voltage=%.4fV", adc_voltage);
        UART_Debug_Println(msg);
      } else {
        UART_Debug_Println("ADS1110: Read failed");
      }

      // Prepare data for LoRa transmission
      uint32_t timestamp = Get_Uptime_Seconds();

      lora_len = snprintf((char *)lora_buffer, sizeof(lora_buffer),
                          "ID:%d,T:%lu,TEMP:%.1f,H:%.1f,V:%.3f", BOARD_ID,
                          timestamp, temperature, humidity, adc_voltage);
    }
    if (Scheduler_ShouldTransmit()) {
      UART_Debug_Println("Transmitting...");
      // Send LoRa
      /* TODO: send actual data */
      // Send actual sensor data if available
      if (lora_len > 0) {
        LoRa_App_SendData(lora_buffer, lora_len);
        UART_Debug_Println("Sensor data transmitted.");
      } else {
        // Send test message if no sensor data
        uint8_t test_msg[] = "No sensor data";
        LoRa_App_SendData(test_msg, sizeof(test_msg));
        UART_Debug_Println("Test message transmitted.");
      }
      UART_Debug_Println("Transmission complete.");
    }

    __WFI(); // Wait for interrupt
  }
}

void SystemClock_Config(void) {
  RCC_OscInitTypeDef RCC_OscInitStruct = {0};
  RCC_ClkInitTypeDef RCC_ClkInitStruct = {0};

  HAL_PWR_EnableBkUpAccess();
  __HAL_RCC_LSEDRIVE_CONFIG(RCC_LSEDRIVE_LOW);
  __HAL_PWR_VOLTAGESCALING_CONFIG(PWR_REGULATOR_VOLTAGE_SCALE1);

  RCC_OscInitStruct.OscillatorType =
      RCC_OSCILLATORTYPE_LSE | RCC_OSCILLATORTYPE_MSI;
  RCC_OscInitStruct.LSEState = RCC_LSE_ON;
  RCC_OscInitStruct.MSIState = RCC_MSI_ON;
  RCC_OscInitStruct.MSICalibrationValue = RCC_MSICALIBRATION_DEFAULT;
  RCC_OscInitStruct.MSIClockRange = RCC_MSIRANGE_11;
  RCC_OscInitStruct.PLL.PLLState = RCC_PLL_NONE;
  if (HAL_RCC_OscConfig(&RCC_OscInitStruct) != HAL_OK) {
    Error_Handler();
  }

  RCC_ClkInitStruct.ClockType = RCC_CLOCKTYPE_HCLK3 | RCC_CLOCKTYPE_HCLK |
                                RCC_CLOCKTYPE_SYSCLK | RCC_CLOCKTYPE_PCLK1 |
                                RCC_CLOCKTYPE_PCLK2;
  RCC_ClkInitStruct.SYSCLKSource = RCC_SYSCLKSOURCE_MSI;
  RCC_ClkInitStruct.AHBCLKDivider = RCC_SYSCLK_DIV1;
  RCC_ClkInitStruct.APB1CLKDivider = RCC_HCLK_DIV1;
  RCC_ClkInitStruct.APB2CLKDivider = RCC_HCLK_DIV1;
  RCC_ClkInitStruct.AHBCLK3Divider = RCC_SYSCLK_DIV1;

  if (HAL_RCC_ClockConfig(&RCC_ClkInitStruct, FLASH_LATENCY_2) != HAL_OK) {
    Error_Handler();
  }
}

void LED_Init(void) {
  __HAL_RCC_GPIOB_CLK_ENABLE();

  GPIO_InitTypeDef gpio = {0};
  gpio.Pin = GPIO_PIN_5;
  gpio.Mode = GPIO_MODE_OUTPUT_PP;
  gpio.Pull = GPIO_NOPULL;
  gpio.Speed = GPIO_SPEED_FREQ_LOW;
  HAL_GPIO_Init(GPIOB, &gpio);
}

void LED_Blink(uint8_t times, uint32_t delay_ms) {
  for (uint8_t i = 0; i < times; i++) {
    HAL_GPIO_TogglePin(GPIOB, GPIO_PIN_5);
    HAL_Delay(delay_ms);
  }
  HAL_GPIO_WritePin(GPIOB, GPIO_PIN_5, GPIO_PIN_RESET);
}

void LED_On(void) { HAL_GPIO_WritePin(GPIOB, GPIO_PIN_5, GPIO_PIN_SET); }

void LED_Off(void) { HAL_GPIO_WritePin(GPIOB, GPIO_PIN_5, GPIO_PIN_RESET); }

void Error_Handler(void) {
  __disable_irq();
  while (1) {
    UART_Debug_Println("Error occurred! Halting.");
  }
}

uint32_t Get_Uptime_Seconds(void) { return HAL_GetTick() / 1000; }

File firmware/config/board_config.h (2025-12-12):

#ifndef BOARD_CONFIG_H
#define BOARD_CONFIG_H

#include "stm32wlxx_hal.h"

// GPIO Pin and Peripheral Configuration
// Below is for Wio-e5 board configuration
#define LED_GPIO_PORT GPIOB
#define LED_GPIO_PIN GPIO_PIN_5
#define LED_GPIO_CLK_ENABLE() __HAL_RCC_GPIOB_CLK_ENABLE()

#define BOARD_ID 1

#define I2C_TIMING 0x00702991 // 100kHz @ 48MHz

#define I2C_TIMEOUT_MS 100 // Timeout in milliseconds

#define I2C_SCL_GPIO_PORT GPIOB
#define I2C_SCL_GPIO_PIN GPIO_PIN_15
#define I2C_SCL_GPIO_AF GPIO_AF4_I2C2

#define I2C_SDA_GPIO_PORT GPIOA
#define I2C_SDA_GPIO_PIN GPIO_PIN_15
#define I2C_SDA_GPIO_AF GPIO_AF4_I2C2

#define USART_BAUDRATE 115200

#if defined(BOARD_CUSTOM)
// Custom PCB uses different UART pins
#define USARTx_TX_Pin GPIO_PIN_2
#define USARTx_TX_GPIO_Port GPIOA

#define USARTx_RX_Pin GPIO_PIN_3
#define USARTx_RX_GPIO_Port GPIOA
#else
// Wio-E5 (default)
#define USARTx_TX_Pin GPIO_PIN_6
#define USARTx_TX_GPIO_Port GPIOB

#define USARTx_RX_Pin GPIO_PIN_7
#define USARTx_RX_GPIO_Port GPIOB
#endif
// LoRa Configuration Parameters
#define LORA_FREQUENCY 915000000 // 915 MHz (US)

// TODO: Find in Radio.SetTxConfig call
#define LORA_TX_POWER_DBM 14    // TX power in dBm
#define LORA_BANDWIDTH 0        // 0=125kHz, 1=250kHz, 2=500kHz
#define LORA_SPREADING_FACTOR 7 // SF7..SF12
#define LORA_CODING_RATE 1      // 1=4/5, 2=4/6, 3=4/7, 4=4/8
#define LORA_PREAMBLE_LENGTH 8  // Preamble length in symbols
#define LORA_TX_TIMEOUT_MS 3000 // TX timeout

#endif // BOARD_CONFIG_H

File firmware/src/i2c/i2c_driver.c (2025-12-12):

// #include <stdint.h>
#include "i2c_driver.h"
#include "board_config.h"
// #include "stm32wlxx_hal.h"

// I2C handle for I2C2 peripheral
static I2C_HandleTypeDef hi2c2;

// Initialize I2C peripheral
int8_t I2C_Init(void) {
  __HAL_RCC_GPIOA_CLK_ENABLE();
  __HAL_RCC_GPIOB_CLK_ENABLE();
  __HAL_RCC_I2C2_CLK_ENABLE();

  GPIO_InitTypeDef GPIO_InitStruct = {0};

  // Configure PA15 as I2C2_SDA
  GPIO_InitStruct.Pin = I2C_SDA_GPIO_PIN;

  GPIO_InitStruct.Mode = GPIO_MODE_AF_OD; // AF: Alternate Function Open-Drain
  GPIO_InitStruct.Pull = GPIO_PULLUP;
  GPIO_InitStruct.Speed = GPIO_SPEED_FREQ_HIGH;
  GPIO_InitStruct.Alternate = I2C_SDA_GPIO_AF; // SDA function
  HAL_GPIO_Init(I2C_SDA_GPIO_PORT, &GPIO_InitStruct);

  // Configure PB10 as I2C2_SCL
  GPIO_InitStruct.Pin = I2C_SCL_GPIO_PIN;
  GPIO_InitStruct.Alternate = I2C_SCL_GPIO_AF; // SCL function
  HAL_GPIO_Init(I2C_SCL_GPIO_PORT, &GPIO_InitStruct);

  hi2c2.Instance = I2C2;
  hi2c2.Init.Timing = I2C_TIMING; // 100kHz @ 48MHz
  hi2c2.Init.OwnAddress1 = 0;
  hi2c2.Init.AddressingMode = I2C_ADDRESSINGMODE_7BIT;
  hi2c2.Init.DualAddressMode = I2C_DUALADDRESS_DISABLE;
  hi2c2.Init.OwnAddress2 = 0;
  hi2c2.Init.OwnAddress2Masks = I2C_OA2_NOMASK;
  hi2c2.Init.GeneralCallMode = I2C_GENERALCALL_DISABLE;
  hi2c2.Init.NoStretchMode = I2C_NOSTRETCH_DISABLE;
  if (HAL_I2C_Init(&hi2c2) != HAL_OK) {
    return I2C_ERROR; // Initialization Error
  }
  // Configure analog filter
  if (HAL_I2CEx_ConfigAnalogFilter(&hi2c2, I2C_ANALOGFILTER_ENABLE) != HAL_OK) {
    return I2C_ERROR;
  }

  // Configure digital filter (0 = disabled)
  if (HAL_I2CEx_ConfigDigitalFilter(&hi2c2, 0) != HAL_OK) {
    return I2C_ERROR;
  }

  return I2C_OK;
}

// Write to I2C device
int8_t I2C_Write(uint8_t dev_addr, uint8_t *data, uint16_t len) {
  HAL_StatusTypeDef status;

  // HAL expects 7-bit address shifted left by 1
  status =
      HAL_I2C_Master_Transmit(&hi2c2, dev_addr << 1, data, len, I2C_TIMEOUT_MS);

  if (status == HAL_OK)
    return I2C_OK;
  else if (status == HAL_TIMEOUT)
    return I2C_TIMEOUT;
  else if (status == HAL_BUSY)
    return I2C_BUSY;
  else
    return I2C_ERROR;
}

int8_t I2C_Read(uint8_t dev_addr, uint8_t *data, uint16_t len) {
  HAL_StatusTypeDef status;

  status =
      HAL_I2C_Master_Receive(&hi2c2, dev_addr << 1, data, len, I2C_TIMEOUT_MS);

  if (status == HAL_OK)
    return I2C_OK;
  else if (status == HAL_TIMEOUT)
    return I2C_TIMEOUT;
  else if (status == HAL_BUSY)
    return I2C_BUSY;
  else
    return I2C_ERROR;
}

int8_t I2C_WriteRead(uint8_t dev_addr, uint8_t *tx_data, uint16_t tx_len,
                     uint8_t *rx_data, uint16_t rx_len) {
  HAL_StatusTypeDef status;

  // First write the data (usually register address)
  status = HAL_I2C_Master_Transmit(&hi2c2, dev_addr << 1, tx_data, tx_len,
                                   I2C_TIMEOUT_MS);
  if (status != HAL_OK) {
    if (status == HAL_TIMEOUT)
      return I2C_TIMEOUT;
    if (status == HAL_BUSY)
      return I2C_BUSY;
    return I2C_ERROR;
  }

  // Then read the response
  status = HAL_I2C_Master_Receive(&hi2c2, dev_addr << 1, rx_data, rx_len,
                                  I2C_TIMEOUT_MS);

  if (status == HAL_OK)
    return I2C_OK;
  else if (status == HAL_TIMEOUT)
    return I2C_TIMEOUT;
  else if (status == HAL_BUSY)
    return I2C_BUSY;
  else
    return I2C_ERROR;
}

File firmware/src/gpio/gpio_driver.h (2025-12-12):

#ifndef GPIO_DRIVER_H
#define GPIO_DRIVER_H

#include "stm32wlxx_hal.h"
#include <stdint.h>

// GPIO configuration structure
typedef struct {
  GPIO_TypeDef *port;
  uint16_t pin;
  uint32_t mode;
  uint32_t pull;
  uint32_t speed;
} GPIO_Handle_t;

// Pull-up/down options
#define GPIO_PULL_NONE GPIO_NOPULL
#define GPIO_PULL_UP GPIO_PULLUP
#define GPIO_PULL_DOWN GPIO_PULLDOWN

// GPIO speed options
#define GPIO_SPEED_LOW GPIO_SPEED_FREQ_LOW
#define GPIO_SPEED_MEDIUM GPIO_SPEED_FREQ_MEDIUM
#define GPIO_SPEED_HIGH GPIO_SPEED_FREQ_HIGH

// Function prototypes
void GPIO_Init(GPIO_Handle_t *gpio);
void GPIO_Write(GPIO_Handle_t *gpio, uint8_t state);
uint8_t GPIO_Read(GPIO_Handle_t *gpio);
void GPIO_Toggle(GPIO_Handle_t *gpio);

#endif // GPIO_DRIVER_H

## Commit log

2025-10-16 add .gitignore to prevent local kicad configs which will cause merge issues
2025-10-16 add kicad project files
    [adc.kicad_sch, lora_daq_module.kicad_pcb, lora_daq_module.kicad_sch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]
2025-10-16 add idea for kicad version control to readme
2025-10-16 update schematic properties
    [lora_module.kicad_sch]
2025-10-21 add dev notes for adc integration
2025-10-21 add dev notes for power schematic
2025-10-24 add chips and start wiring USBC Recept. & UART bridge
    [lora_module.kicad_sch]
2025-10-24 added eeprom support, antenna connector, and general connections needed for rev0 schematic
    [lora_module.kicad_sch]
2025-10-24 schematic documentation
    [lora_module.kicad_sch]
2025-10-27 added ADC input filter schematic
    [adc.kicad_sch]
2025-10-27 added Oct 26 ADC KiCad schematic design notes
2025-10-28 added Oct 26 ADC schematic design log
2025-10-28 added the mcp73833
    [power_management.kicad_sch]
2025-10-29 added the tps63001 and tps63002 with their reference design
    [power_management.kicad_sch]
2025-10-30 Updated the Adc circuit w/filters
    [adc.kicad_sch]
2025-11-11 docs: voltage divider optimization notes Nov 10
2025-11-11 modified ADC input filter schematic
    [adc.kicad_sch]
2025-11-11 post design review comments
    [lora_module.kicad_sch]
2025-11-12 adjusted ADC input filter power rails, added commets
    [adc.kicad_sch]
2025-11-12 add pinout for wio-e5 and add entry about schematic revisions to the dev note
    [wio-e5pinout.csv]
2025-11-12 add sd card, swd connector, external uart, and update pinout for wio-e5
    [lora_module.kicad_sch]
2025-11-12 add kicad symbol for wio-e5
2025-11-12 Removed the 3.3V buck-boost converter from the original design, then added LDO
    [power_management.kicad_sch]
2025-11-13 update dev notes, add prelim layout pdf, prelim layout cad as pngs, and updated schematic as pdf
2025-11-13 updated power schematic to include power switching IC for battery/usb power, minor changes to lora module schematic, added footprints to all component and began with the preliminary layout based on d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
    [adc.kicad_sch, lora_daq_module.kicad_pcb, lora_daq_module.kicad_sch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]
2025-11-13 setup BOM columns
    [adc.kicad_sch, lora_module.kicad_sch, power_management.kicad_sch]
2025-11-14 add preliminary bom as xlsx, update dev notes regarding bom decision making process
    [lora_daq_module_prelim_bom.xlsx]
2025-11-14 assign parts and update BOM in symbol field table, warn: pcb footprints need update
    [adc.kicad_sch, lora_module.kicad_sch, power_management.kicad_sch]
2025-11-14 add prelim bom as csv for native viewing on github
    [prelim_bom.csv]
2025-11-16 near-complete layout of power domain
    [lora_daq_module.kicad_pcb, lora_module.kicad_sch]
2025-11-17 lay traces to all components
    [adc.kicad_sch, lora_daq_module.kicad_pcb, lora_module.kicad_sch]
2025-11-17 finish rough layout, drc fixedup
    [lora_daq_module.kicad_pcb]
2025-11-17 add rough draft schematic
2025-11-18 add test points and antenna microstrip
    [adc.kicad_sch, lora_daq_module.kicad_pcb, lora_module.kicad_sch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]
2025-11-18 add notes regarding antenna microstrip design
2025-11-20 edit board setup for jlcpcb 4 layer 1.6mm 1oz copper in/out and redesign antenna microstrip
    [lora_daq_module.kicad_pcb]
2025-11-20 add ohm resistors for power schematic, update design rules for jlc
    [lora_daq_module.kicad_pcb, power_management.kicad_sch]
2025-11-21 add pcb final revision dev notes
2025-11-21 add final schematics, layout, 3dmodels
2025-11-21 add 0Ω resistors for disabling power circuits, revise adc input buffer and filter based on design review feedback, revise microstrip trace, add hardware reset button, add i2c connector and jst recept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
    [adc.kicad_sch, lora_daq_module.kicad_pcb, lora_module.kicad_sch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]
2025-11-21 add production files used for jlc order
    [bom.csv, designators.csv, positions.csv]
2025-12-01 enable lora, timer interrupt scheduling main structure and layout for src structure
2025-12-02 add I2C interface
2025-12-04 Add GPIO driver, ADS1110 ADC, and board config system
2025-12-06 fix interrupt issues during initializing timmer
2025-12-06 fix: using uart building from HAL instead, not relying on example driver... That brings robotness of changing UART peripheral much easier; remove gpio mode Macro as this has delared everywhere
    [gpio_driver.h, uart_debug.c]
2025-12-06 add ADC application code; test once with our analog sensor but keep reading the same value
2025-12-12 add Board ID config
